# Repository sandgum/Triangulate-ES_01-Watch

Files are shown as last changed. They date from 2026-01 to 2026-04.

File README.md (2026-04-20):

# Triangulate ES_01 E-ink Watch

---

An ultra-thin ESP32S3-based smartwatch (at just 5mm thick at its thickest point) which uses an E-ink display and two OLEDs to display information while consuming a small amount of power. The main E-ink panel is touch-enabled, with the two additional OLED panels above and below it displaying auxiliary information, such as notifications, background activities etc. 
The watch has built-in heart rate and spO2 sensing via an Analog Devices MAX30102, high-precision smart movement sensing via a Bosch BH260AP IMU and a Bosch BMP585 barometric pressure sensor.

render1
render10

*ACKNOWLEDGMENT: Most of the materials and the human hand model you see in the renders are not my own work, but is Royalty-free or CC0 licensed work legitimately downloaded from BlenderKit using their free plan*

---

To top it all off, the ES_01 is completely workout-friendly, with rubberised sides and no pesky side buttons that get pressed mid-pushup (Every physical input is at the top of the watch)!
The watch features a sleek design, with each component being laid out single file and in its own separate segment of the watch. These segments can all bend around the watch, preserving a uniform thickness all around, which also adds the benefit of being aesthetically pleasing.
The main microcontroller running the watch is an Espressif ESP32-S3 running with Bluetooth LE capabilities, which also allow for it to sync with a smartphone to relay notifications, workout, and weather data etc. through firmware based on ESP-IDF and host smartphone software for iPhone based on Swift (Coming soon, and Android support will come later!)

---

## PCB:

- 4 layers
- Flex PCB
- Single-sided component placement
- 0.2mm board thickness
- Added 0.1mm FR4 stiffeners
- All resistors and capacitors are 0402 size

### Schematics:

ES_01 Schematics_Page_1
ES_01 Schematics_Page_2
ES_01 Schematics_Page_3
ES_01 Schematics_Page_4

### PCB Layout and render:


render4

*Render is out of date*

---

## Enclosure:

- Main cases and top plates of each segment 3D printed using PLA
- Bottom plates for OLED segments are CNC machined from 6061 Aluminium by JLCCNC (can substitute with any rigid material or also with SLA/MSLA printed resin)
- Bottom plate for main E-ink segment 3D printed using an SLM printer in 316L stainless steel (can substitute with other rigid metal with high thermal conductivity)
- Side flexible pieces printed in TPU by an FDM 3D printer

---

## Assembly instructions:

### To manufacture the PCB, refer to the instructions [here](PCB/README.md)

1. Use the solder stencil to squeegee solder paste onto main PCB
2. Place each component onto its respective pads on the main PCB
3. Use a hotplate or a reflow oven to reflow the solder paste underneath the components
4. Hand-solder a thin insulated wire (enamel insulated or rubber insulated) connecting the pads "BATT1_WIRE" together on the PCB
5. Create a solder bridge connecting the pads "GND_TO_GNDIO" and "GNDIO_TO_GND"
6. Create a solder bridge connecting the pads "GND_TO_GNDPWR" and "GNDPWR_TO_GND"
7. Assemble the two "end battery" segments by threading battery wires through them, placing the battery in and attaching the top plates to their respective main cases with superglue
8. Assemble the other battery segment and the haptic module segment in the same way, but thread the "end battery" wires through the dedicated channels in these segments, you should have two sets of two segments with four wires coming out of each set of segments
9. Take the main cases of the OLED modules and superglue the OLED displays into the top of each, making sure the flex cables poke through their dedicated holes
10. Do the same with the E-ink segment and the E-ink display
11. Attach each remaining top plate to its respective main case using superglue
12. Place and superglue the main Flex PCB into the bottom of the E-ink segment and the two OLED segments. The back of the PCB should face the displays
13. Thread the wires from the two sets of segments from step 8 through the holes in the side of the OLED modules and hand-solder the wires onto their respective pads
14. Plug in the flex cables from each display into thir respective FPC connectors on the main PCB
15. Superglue the bottom panels for the OLED segments onto their respective main cases
16. Apply thermal paste on the ESP32-S3 chip on the main PCB
17. Superglue threaded inserts in the two dedicated holes in the corners of the bottom panel for the E-ink segment
18. Superglue the bottom panel to the main case of the E-ink segment
19. Screw two screws into the holes in the top case of the E-ink segment until they mesh with the threaded inserts from the previous step
20. Take two more screws and cut off their entire threaded sections until just the heads remain. Superglue those heads in the holes in the other two corners of the top panel of the E-ink segment
21. Superglue the side TPU pieces to the sides of all the segments
22. Plug in a patch antenna into the exposed U.FL port on the back of the watch, guide the cable through its designated groove, and stick the patch antenna somewhere on the watch

---

## Bill of materials:

### Electronic Components: (Order quantities account for minimum order quantity of parts from the chosen retailer)

| Manufacturer Part Number | Mfr. | Order Qty. | Unit Price(USD) | Ext.Price(USD) | Package | Description | Product Link |
| --- | --- | --- | --- | --- | --- | --- | --- |
| CC0402JRNPO9BN110 | YAGEO | 100 | 0.0013 | 0.13 | 0402 | 11pF �5% 50V Ceramic Capacitor NP0 0402 | https://www.lcsc.com/product-detail/C527000.html |
| GRM155R61E475ME15D | muRata | 20 | 0.0403 | 0.81 | 0402 | 4.7uF �20% 25V Ceramic Capacitor X5R 0402 | https://www.lcsc.com/product-detail/C2858031.html |
| ESP32-S3 | ESPRESSIF | 1 | 3.0048 | 3 | QFN-56-EP(7x7) | -98.4dBm 150Mbps 2.412GHz~2.484GHz 2.4GHz 3V~3.6V QFN-56-EP(7x7) RF Transceiver ICs RoHS | https://www.lcsc.com/product-detail/C2913192.html |
| 2328702-6 | TE Connectivity | 5 | 0.2027 | 1.01 | SMD,P=0.5mm,Surface Mount,Right Angle  | FFC/FPC Connector 6 Position 0.5mm Pitch Double-Sided Contacts, Top and Bottom Entry Surface Mount, Right Angle -40?~+85?  | https://www.lcsc.com/product-detail/C3151647.html |
| FFC2B28-24-G | Global Connector Technology | 1 | 0.5754 | 0.58 | SMD,P=0.5mm,Surface Mount,Right Angle  | FFC/FPC Connector 24 Position 0.5mm Pitch Double-Sided Contacts, Top and Bottom Entry Surface Mount, Right Angle -25?~+85? | https://www.lcsc.com/product-detail/C3151659.html |
| BHI260AP | Bosch | 1 | 9.8338 | 9.83 | LGA-44 | LGA-44 IMUs (Inertial Measurement Units) RoHS | https://www.lcsc.com/product-detail/C3288651.html |
| SI1308EDL-T1-GE3 | VISHAY | 5 | 0.1543 | 0.77 | SOT-323 | N-Channel 30V 1.5A 0.4W Surface Mount SOT-323 | https://www.lcsc.com/product-detail/C469327.html |
| XC6206P302MR | HXY MOSFET | 50 | 0.0176 | 0.88 | SOT-23 | Linear Voltage Regulator IC Positive Fixed 1 Output 300mA SOT-23 | https://www.lcsc.com/product-detail/C5148691.html |
| MBR0530 | Huixin | 20 | 0.0296 | 0.59 | SOD-123 | 5.5A 1 Independent 30V 500mV@500mA 500mA SOD-123 Single Diodes RoHS | https://www.lcsc.com/product-detail/C49435625.html |
| 0402WGF1004TCE | UNI-ROYAL | 100 | 0.0008 | 0.08 | 0402 | 1M? �1% 62.5mW 0402 Thick Film Resistor | https://www.lcsc.com/product-detail/C26083.html |
| CL05A105KA5NQNC | Samsung Electro-Mechanics | 100 | 0.0033 | 0.33 | 0402 | 1uF �10% 25V Ceramic Capacitor X5R 0402 | https://www.lcsc.com/product-detail/C52923.html |
| XL2EL89CPI-111YLC-40M | YXC Crystal Oscillators | 10 | 0.0619 | 0.62 | SMD3225-4P | Crystal 40MHz �10ppm 15pF SMD3225-4P | https://www.lcsc.com/product-detail/C5444549.html |
| TS-1088-AR02016 | XUNPU | 10 | 0.0455 | 0.46 | SMD,4x3mm | Tactile Switch SPST 160gf 2mm SMD (SMT) Tab 4mm x 3mm Surface Mount | https://www.lcsc.com/product-detail/C720477.html |
| BSS138 | R+O | 50 | 0.0172 | 0.86 | SOT-23 | N-Channel 50V 340mA 350mW Surface Mount SOT-23 | https://www.lcsc.com/product-detail/C7420339.html |
| TCR2EF33,LM(CT | TOSHIBA | 5 | 0.1077 | 0.54 | TSOT-25 | 3.3V 5.5V Positive Fixed TSOT-25 Voltage Regulators - Linear, Low Drop Out (LDO) Regulators RoHS | https://www.lcsc.com/product-detail/C843273.html |
| LQG15HS3N3S02D | muRata | 100 | 0.0079 | 0.79 | 0402 | 800mA 3.3nH 170m? Multilayer inductor 0402 Fixed Inductors RoHS | https://www.lcsc.com/product-detail/C86064.html |
| MRA4003T3G | onsemi | 10 | 0.1152 | 1.15 | SMA(DO-214AC) | Diode 300V 1A Surface Mount SMA(DO-214AC) | https://www.lcsc.com/product-detail/C94410.html |
| DRV2605LDGSR | TI | 1 | 1.3734 | 1.37 | VSSOP-10-0.5mm | I2C VSSOP-10-0.5mm Motor Drivers, Controllers RoHS | https://www.lcsc.com/product-detail/C527464.html |
| LQG15HS2N0S02D | muRata | 100 | 0.0084 | 0.84 | 0402 | 900mA 2nH 100m? Multilayer inductor 0402 Fixed Inductors RoHS | https://www.lcsc.com/product-detail/C18216.html |
| 0402WGF5603TCE | UNI-ROYAL | 100 | 0.0006 | 0.06 | 0402 | 560k? �1% 62.5mW 0402 Thick Film Resistor | https://www.lcsc.com/product-detail/C132339.html |
| CL05B103KB5NNNC | Samsung Electro-Mechanics | 100 | 0.0014 | 0.14 | 0402 | 10nF �10% 50V Ceramic Capacitor X7R 0402 | https://www.lcsc.com/product-detail/C15195.html |
| 0402B102K500NT | FH | 100 | 0.0012 | 0.12 | 0402 | 1nF �10% 50V Ceramic Capacitor X7R 0402 | https://www.lcsc.com/product-detail/C1523.html |
| CL05B104KO5NNNC | Samsung Electro-Mechanics | 100 | 0.0013 | 0.13 | 0402 | 100nF �10% 16V Ceramic Capacitor X7R 0402 | https://www.lcsc.com/product-detail/C1525.html |
| 0402CG1R0C500NT | FH | 100 | 0.0012 | 0.12 | 0402 | 1pF 50V Ceramic Capacitor C0G 0402 | https://www.lcsc.com/product-detail/C1550.html |
| CL05A106MQ5NUNC | Samsung Electro-Mechanics | 100 | 0.0056 | 0.56 | 0402 | 10uF �20% 6.3V Ceramic Capacitor X5R 0402 | https://www.lcsc.com/product-detail/C15525.html |
| CL05B224KO5NNNC | Samsung Electro-Mechanics | 100 | 0.0041 | 0.41 | 0402 | 220nF �10% 16V Ceramic Capacitor X7R 0402 | https://www.lcsc.com/product-detail/C16772.html |
| BMP585 | Bosch | 1 | 3.5109 | 3.51 | LGA-9(3.3x3.3) | 30Kpa~1.25bar LGA-9(3.3x3.3) Pressure Sensors, Transducers RoHS | https://www.lcsc.com/product-detail/C18184976.html |
| LD39200PU33R | ST | 1 | 1.0184 | 1.02 | DFN-6(3x3) | 3.3V 6V Positive Fixed DFN-6(3x3) Voltage Regulators - Linear, Low Drop Out (LDO) Regulators RoHS | https://www.lcsc.com/product-detail/C222192.html |
| CL05A475MP5NRNC | Samsung Electro-Mechanics | 50 | 0.0055 | 0.28 | 0402 | 4.7uF �20% 10V Ceramic Capacitor X5R 0402 | https://www.lcsc.com/product-detail/C23733.html |
| 0402WGF2201TCE | UNI-ROYAL | 100 | 0.0008 | 0.08 | 0402 | 2.2k? �1% 62.5mW 0402 Thick Film Resistor | https://www.lcsc.com/product-detail/C25879.html |
| 0402WGF4701TCE | UNI-ROYAL | 100 | 0.0008 | 0.08 | 0402 | 4.7k? �1% 62.5mW 0402 Thick Film Resistor | https://www.lcsc.com/product-detail/C25900.html |
| ANR4012T470M | APV | 10 | 0.0544 | 0.54 | SMD,4x4mm | 500mA 47uH 500mA Magnetic Shielded Inductor �20% SMD,4x4mm Fixed Inductors RoHS | https://www.lcsc.com/product-detail/C7497063.html |
| MAX30102EFD+T | MAXIM | 1 | 13.0636 | 13.06 | OESIP-14 | I2C OESIP-14 Specialized Sensors RoHS | https://www.lcsc.com/product-detail/C6454833.html |
| MAX17048X+T10 | MAXIM | 1 | 1.1576 | 1.16 | WLP-8(0.9x1.8) | Lithium Battery I2C WLP-8(0.9x1.8) Battery Management RoHS | https://www.lcsc.com/product-detail/C7497002.html |
| 1N4148 | onsemi | 50 | 0.0353 | 1.77 | DO-35 | Diode 100V 200mA Through Hole DO-35 | https://www.lcsc.com/product-detail/C258182.html |
| FRC0402F1001TS | FOJAN | 100 | 0.0006 | 0.06 | 0402 | 1k? �1% 62.5mW 0402 Thick Film Resistor | https://www.lcsc.com/product-detail/C2906864.html |
| FRC0402F22R0TS | FOJAN | 100 | 0.0006 | 0.06 | 0402 | 22? �1% 62.5mW 0402 Thick Film Resistor | https://www.lcsc.com/product-detail/C2929994.html |
| FRC0402F2R20TS | FOJAN | 100 | 0.0008 | 0.08 | 0402 | 2.2? �1% 62.5mW 0402 Thick Film Resistor | https://www.lcsc.com/product-detail/C2909330.html |
| FRC0402F1002TS | FOJAN | 100 | 0.0006 | 0.06 | 0402 | 10k? �1% 62.5mW 0402 Thick Film Resistor | https://www.lcsc.com/product-detail/C2906861.html |
| LW06121 | WENDA | 100 | 0.07 | 7 | SMD,P=0.62mm,Surface Mount,Right Angle | 1.2H 14Pin 0.62mm Pitch OLED FPC/FFC Upper Contact Pull-Out Horizontal SMD Flat Connector | https://www.alibaba.com/product-detail/WENDA-LW06121-1-2H-14Pin-0_1601292173873.html |
| GDEY0154D67-T03 | Goodisplay | 1 | 11.32 | 11.32 | - | 1.54Inch Touch E-Paper 200x200 E-Ink Display | https://www.aliexpress.com/item/1005005200574055.html |
| SSD1306 | - | 2 | 0.72 | 1.44 | - | 0.91 Inch I2C OLED Module | https://www.aliexpress.com/item/1005004415958608.html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 |
| 401230 | - | 5 | 8.37 | 11.7 | - | 3.7V 130mAh Rechargeable Li-Po Polymer Battery | https://www.aliexpress.com/item/1005011548432569.html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,scm-url:1007.40050.354490.0,pvid:3bd3e2fd-a970-4708-ad0d-5a1d5a035dc8,tpp_buckets:668%232846%238108%231977&pdp_ext_f=%7B"order"%3A"6"%2C"eval"%3A"1"%2C"sceneId"%3A"30050"%2C"fromPage"%3A"recommend"%7D&pdp_npi=6%40dis%21USD%2113.08%218.37%21%21%2189.86%2157.51%21%402101e2b417711150796635781ebc60%2112000055887278871%21rec%21AU%216047249797%21XZ%211%210%21n_tag%3A-29919%3Bd%3A65a10f57%3Bm03_new_user%3A-29895&utparam-url=scene%3ApcDetailTopMoreOtherSeller%7Cquery_from%3A%7Cx_object_id%3A1005011548432569%7C_p_origin_prod%3A |
| 0619AAC | - | 1 | 3.06 | 3.06 | - | Brushless X-axis 1.2V 100mA Max Precision Vibration Motor | https://www.aliexpress.com/item/1005006421331249.html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 |
| TS-A002 | - | 20 | 0.069 | 1.38 | - | Momentary Tact Switch SMD | https://www.aliexpress.com/item/1005008702742151.html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 |
| - | - | 50 | 0.0264 | 1.32 | - | M1.4 Torx countersunk machine screw 4mm length | https://www.aliexpress.com/item/33006942612.html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 |
| - | - | 50 | 0.0244 | 1.22 | - | M1.4 Brass threaded inserts 1.5mm length | https://www.aliexpress.com/item/1005007653131713.html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 |

Total: $88.97 USD

### Manufactured Components

| Description | Manufacturer | Material | Price (USD) |
| --- | --- | --- | --- |
| CNC Machined OLED Segment Bottom Plates  | JLCCNC | Aluminium 6061 | 17.46 |
| SLM 3D Printed Main Segment Bottom Plate | JLC3DP | 316L Stainless Steel | 8.39 |
| Main 4-layer Flex PCB | JLCPCB | Yellow 0.2mm Polyimide with 0.1mm FR4 Stiffener | 94.00 |
| SMD Stencil for Main Flex PCB | JLCPCB | Steel | 7.47 |

Total: $127.32 USD

---

## Grand Total (Excl. Shipping): $216.29 USD

---

render2
render3
render7
render9
render6
render5

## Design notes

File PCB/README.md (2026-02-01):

# How to Manufacture the PCB

1. Go to the folder `PCB/Production Files`

2. Find the zip file named `ES_01_mainPCB-vxx.zip`

3. Upload the zip file to JLCPCB (or your preferred PCB manufacturing site), DO NOT expand the file

4. If you are using JLCPCB, follow these next instructions:
   
   1. **Set Base Material to Flex**
   
   2. Set Substrate Type to 25um dielectric thickness
   
   3. **Set Layers to 4**
   
   4. Leave Dimensions unchanged (They should be greyed out anyways)
   
   5. **Set PCB Qty to 5**
   
   6. Leave Different Design and Delivery Format unchanged
   
   7. **Set PCB Thickness to 0.2mm**
   
   8. Set Coverlay Color to whatever you want! (Yellow is the cheapest btw)
   
   9. Leave Silkscreen, Copper Type, Surface Finish and Gold Thickness unchanged
   
   10. Leave Outer Copper Weight, Inner Copper Weight, Specify Layer Sequence, Stackup Type, Layer Stackup, Coverlay Thickness and Gold Fingers unchanged
   
   11. Set EDA Software to Other
   
   12. **Set Stiffener to FR4**
   
   13. **Set FR4 Thickness to 0.1mm**
   
   14. Leave Cutting Method and Confirm Production file unchanged
   
   15. Set Mark on PCB to Order Number
   
   16. Leave everything else unchanged
   
   17. At the very bottom, select PCB Stencil. In its settings:
       
       1. Leave Framework, Step Stencil and Nano-coating unchanged
       
       2. **Set Stencil Style to Top only**
       
       3. Leave Dimensions unchanged
       
       4. **Set Stencil Qty to 1**
       
       5. Leave everything else unchanged
   
   18. Click Save to Cart, and you're done!

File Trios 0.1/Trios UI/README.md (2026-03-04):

# How this UI project works

* After a lot of going back and forth, this UI uses EEZ studio as its drag and drop editor.
* Since EEZ Studio cannot support multiple displays in one project (The ES_01 has three displays), each display gets its own EEZ Studio project.
* These will be exported (once done) and have custom logic added to the C files which links events happening on the main screen to changes on the two OLEDS.
* There will be a bunch of other stuff added to the C code, including wiring in all the variables and setting callback functions for haptics.

# Implemented features

* Watch face showing:
  * Time
  * Date
  * Heart rate
  * Altitude
  * Step count for today
* 3 menu pages with 12 "apps" in total
  * ### Workout app:
    * 6 different workout types
      * Run
      * Walk
      * Cycle
      * HIIT
      * Yoga
      * Other
    * Statistics based on previous workouts
      * Zoomable graph showing activity over time
      * Top three favourite workouts, ranked by number of times done
    * Multipurpose counter
    * Workout sensor data
      * Heart rate
      * Estimated calories
      * Reps/distance travelled
    * After workout statistics
      * Zoomable graphs for:
        * Heart rate over time
        * Calories over time
        * Distance/reps over time
      * Average heart rate
      * Total calories burnt
  * ### Barometer app:
    * Current altitude
    * Average altitude for today
    * Zoomable graph for altitude over time
    * Current air pressure
    * Average air pressure for today
    * Zoomable graph for air pressure over time
  * ### Activity stats app:
    * Total step count, calories, activity time for today
    * Portion of daily step, calorie, activity goal completed
    * Zoomable graph for:
      * Step count over time
      * Calorie count over time
      * Activity over time
  * ### Vitals app:
    * Current heart rate, SpO2
    * Resting heart rate
    * Average SpO2
    * Zoomable graph showing heart rate, SpO2
  * ### Weather app:
    * Current temperature from iPhone WeatherKit
    * Current temperature measured by onboard sensor
    * Min/max temperatures for today (WeatherKit)
    * Current weather conditions (WeatherKit)
    * Forecasted temperature, weather conditions for the rest of the day (WeatherKit)
    * Forecasted min/max temperatures, weather conditions for next 10 days (WeatherKit)
  * ### Notifications:
    * Shows an indefinite number of notifications in the form of pages of four
    * App, title and text content of each notification
    * Tapping a notification opens an extended notification view, where more content text is shown
    * Notifications show an extended view when new notifications arrive
    * Specialised notification view for calls, with the option to decline or accept on phone
  * ### Timekeeping app:
    * Stopwatch
      * All logic is integrated using EEZ Flow
      * Stopwatch can be stopped, resumed and reset
      * Up to 99h 59m 59s counting
      * Arc to show seconds
    * Timer
      * All logic is implemented using EEZ Flow
      * Rollers for hours, minutes and seconds
      * Values on roller automatically update with countdown
      * Timer continues in the background
      * End of timer pop-up which shows upon completion, no matter where in the UI the user is
  * ### Timetable app:
    * Shows an arbitrary number of timetable events for a single day on a roller
    * Shows all timetable events for each day of the week
    * Editing timetable events will happen through the iPhone app
    * Timetable event popup which appears a set period of time before each event

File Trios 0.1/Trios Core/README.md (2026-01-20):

# Functions implemented so far:

* Wrote driver for 1.54 inch e-ink display to operate over SPI (uses ssd1681 driver IC)
* Wrote driver for FT6336 touch driver IC (for main e-ink panel)
* Implemented LVGL v9 into project
* Implemented OLED displays (ssd1306 driver IC) into project and LVGL
* Upgraded project to use ESP-IDF 5.3 (to use built-in ssd1306 component)
* Created minimal driver library for MAX30102 heart rate sensor
* Implemented basic heart rate measurement using MAX30102
* Implemented various functions using Bosch BHI260AP IMU using Bosch API, including:

  * Orientation tracking using IMU's built-in sensor fusion algorithm
  * Intelligent step counting using IMU's built-in algorithm running on its own coprocessor
  * Intelligent wrist raise detection, sending interrupts to wake ESP32 from light sleep

* Implemented basic sleep/wake-up logic, including:

  * Putting ESP32 in light sleep after a certain period of inactivity on touch screen
  * Putting ESP32 in light sleep when BHI260AP detects that the user's wrist is facing downwards
  * Waking ESP32 from light sleep using its own timer to periodically take heart rate measurements

* Implemented reading Bosch BMP585 pressure/temperature sensor using Bosch sensor API
* Implemented driving DRV2605 haptic driver
* IT BUILDS!!!

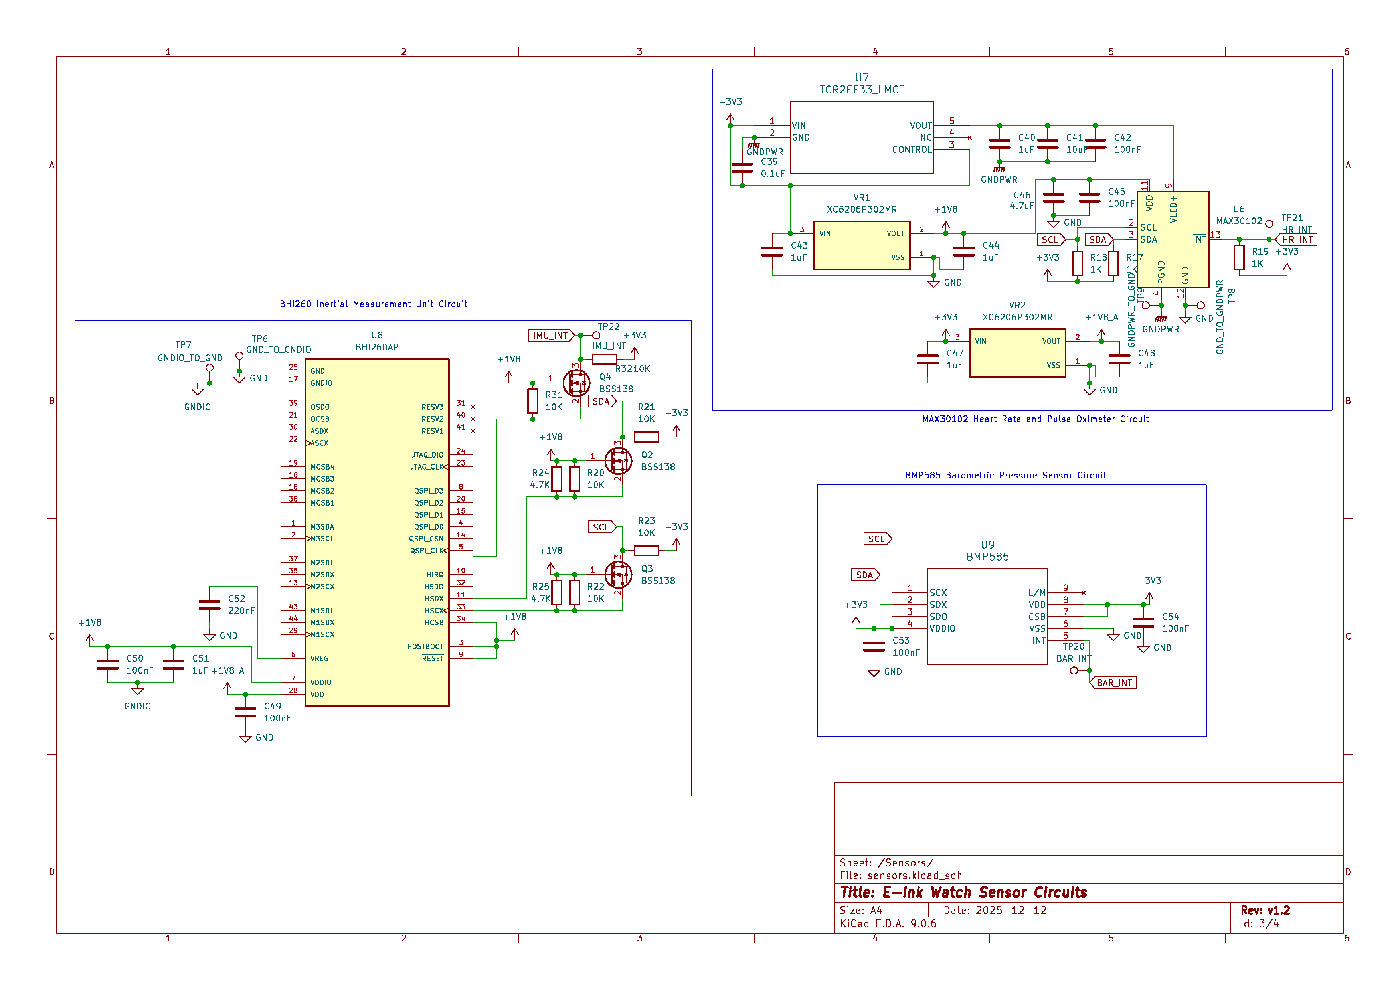
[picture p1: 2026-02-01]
PCB/KiCAD Files v3.2/E-ink watch_Page_3.png

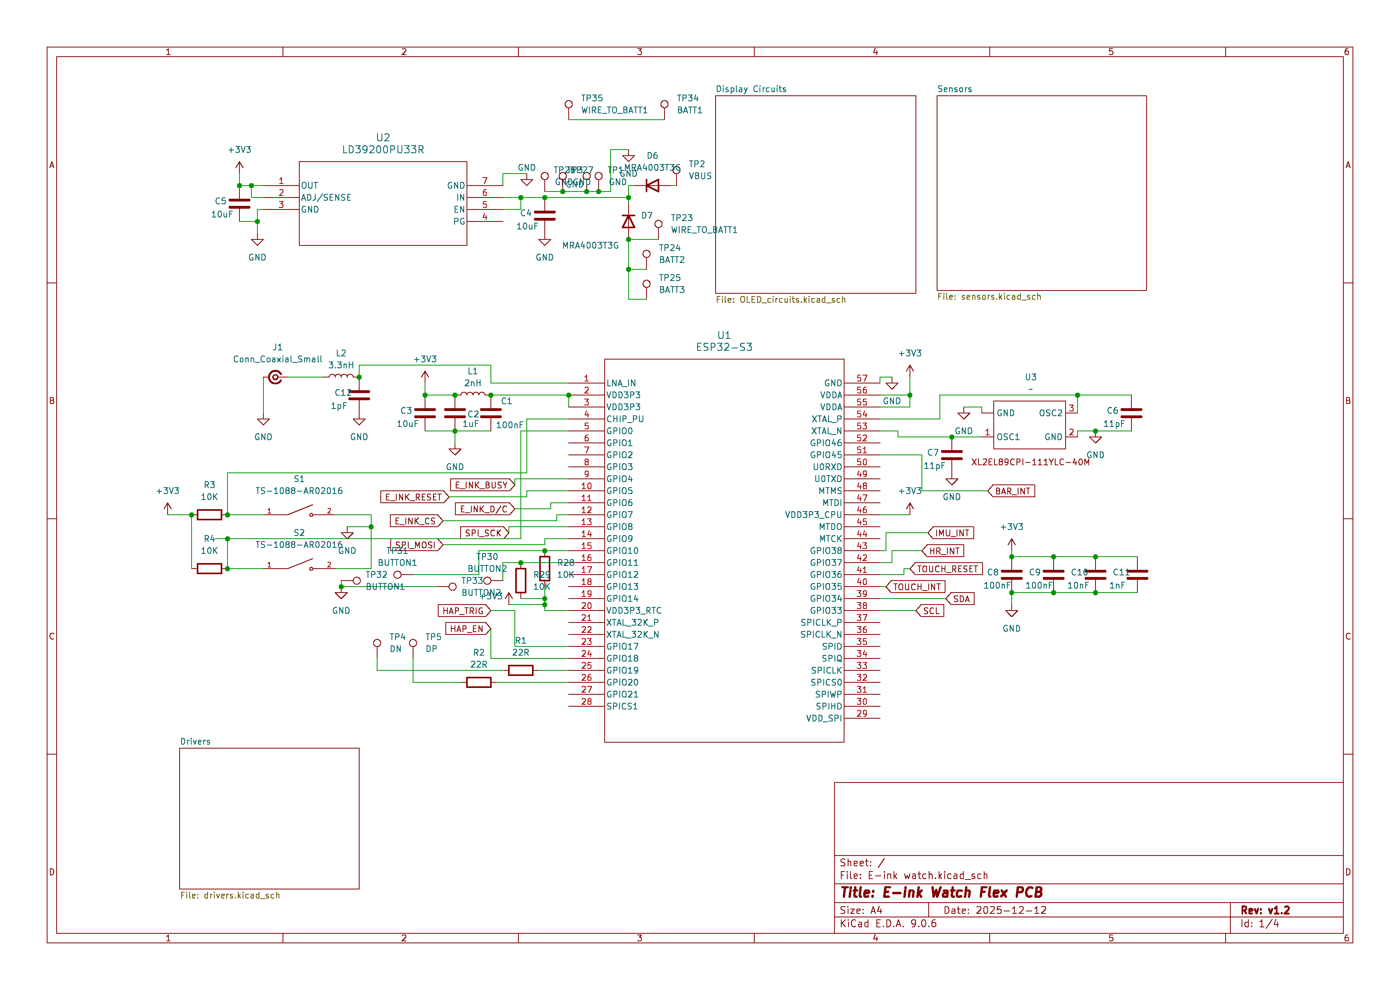
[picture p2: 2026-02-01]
PCB/KiCAD Files v3.2/E-ink watch_Page_1.png

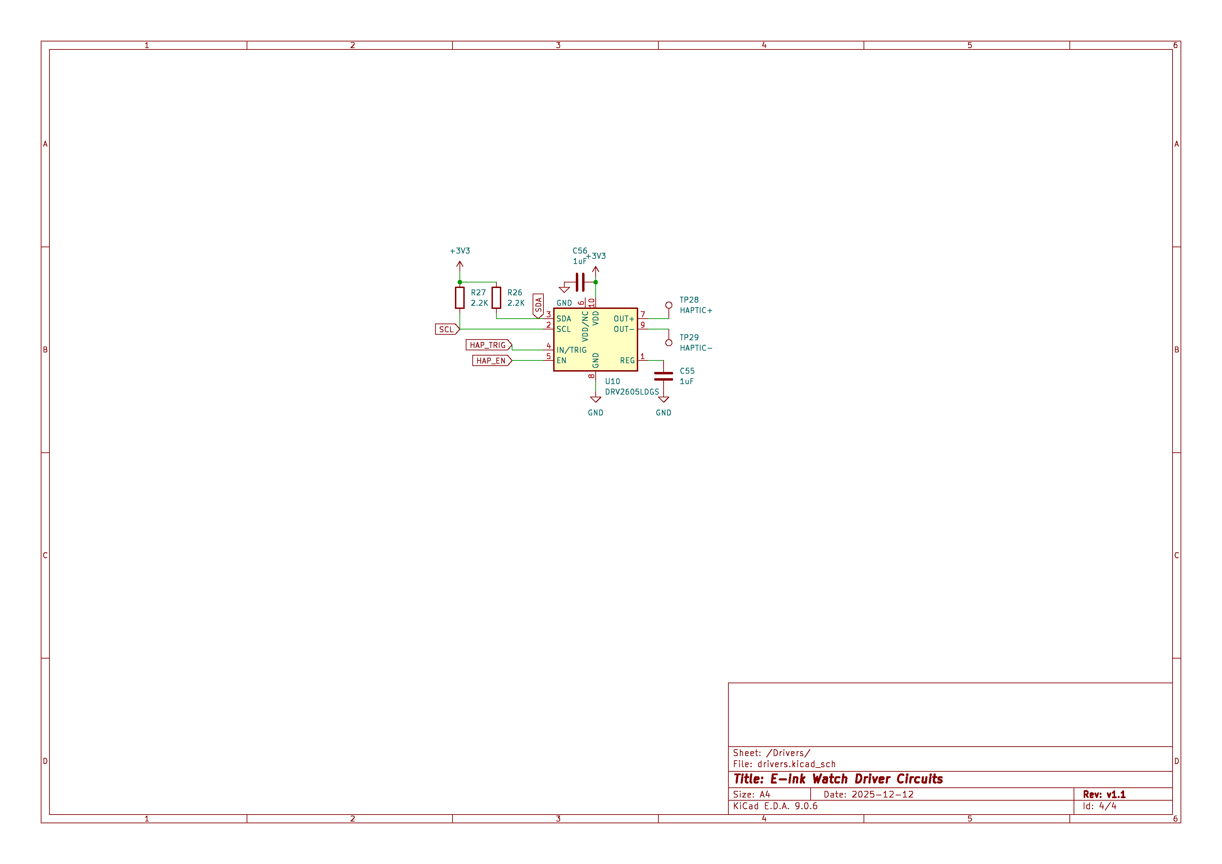
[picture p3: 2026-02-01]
PCB/KiCAD Files v3.2/E-ink watch_Page_4.png

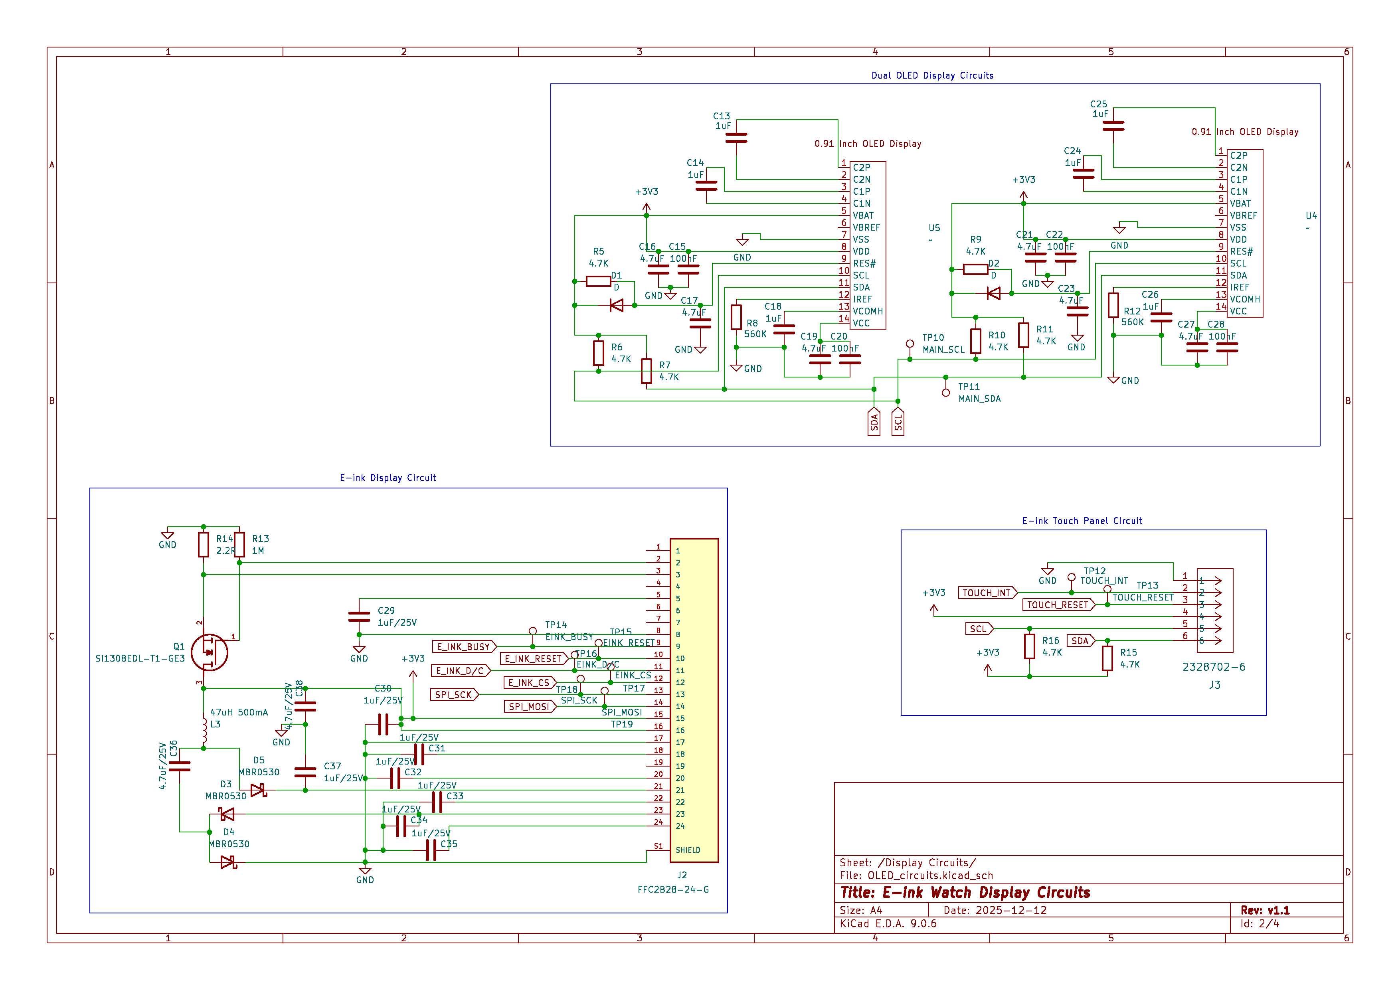
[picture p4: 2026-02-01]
PCB/KiCAD Files v3.2/E-ink watch_Page_2.png

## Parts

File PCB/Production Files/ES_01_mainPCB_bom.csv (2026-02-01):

Designator | Footprint | Quantity | Value | LCSC Part #
C1, C15, C20, C22, C28, C42, C45, C49, C50, C53, C54, C8, C9 | 0402 | 13 | 100nF
C10 | 0402 | 1 | 10nF
C11 | 0402 | 1 | 1nF
C12 | 0402 | 1 | 1pF
C13, C14, C2, C24, C25, C40, C43, C44, C47, C48, C51, C55, C56, C57, C58 | 0402 | 15 | 1uF
C16, C17, C19, C21, C23, C27, C46 | 0402 | 7 | 4.7uF
C18, C26 | 0402 | 2 | 2.2uF
C29, C30, C31, C32, C33, C34, C35, C37 | 0402 | 8 | 1uF/25V
C3, C4, C41, C5 | 0402 | 4 | 10uF
C36, C38 | 0402 | 2 | 4.7uF/25V
C39 | 0402 | 1 | 0.1uF
C52 | 0402 | 1 | 220nF
C6, C7 | 0402 | 2 | 11pF
D1, D2 | D_DO-35_SOD27_P7.62mm_Horizontal | 2 | D
D3, D4, D5 | 0805 | 3 | MBR0530
D6, D7 | D_SMA | 2 | MRA4003T3G
J1 | U.FL_Hirose_U.FL-R-SMT-1_Vertical | 1 | Conn_Coaxial_Small
J2 | GCT_FFC2B28-24-G | 1 | FFC2B28-24-G
J3 | CONN6_2328702-6_TEC | 1 | 2328702-6
L1 | 0402 | 1 | 2nH
L2 | 0402 | 1 | 3.3nH
L3 | Untitled | 1 | 47uH 500mA
Q1 | SOT65P210X110-3N | 1 | SI1308EDL-T1-GE3
Q2, Q3, Q4 | SOT-23 | 3 | BSS138
R1, R2 | 0402 | 2 | 22R
R10, R11, R15, R16, R24, R25, R5, R6, R7, R9 | 0402 | 10 | 4.7K
R12, R8 | 0402 | 2 | 560K
R13 | 0402 | 1 | 1M
R14 | 0402 | 1 | 2.2R
R17, R18, R19 | 0402 | 3 | 1K
R20, R21, R22, R23, R28, R29, R3, R30, R31, R32, R33, R34, R35, R4 | 0402 | 14 | 10K
R26, R27 | 0402 | 2 | 2.2K
S1, S2 | SW_TS-1088-AR02016 | 2 | TS-1088-AR02016
TP1, TP26, TP27, TP3 | TestPoint_Pad_1.5x1.5mm | 4 | GND
TP10 | TestPoint_Pad_D1.0mm | 1 | MAIN_SCL
TP11 | TestPoint_Pad_D1.0mm | 1 | MAIN_SDA
TP12 | TestPoint_Pad_D1.0mm | 1 | TOUCH_INT
TP13 | TestPoint_Pad_D1.0mm | 1 | TOUCH_RESET
TP14 | TestPoint_Pad_D1.0mm | 1 | EINK_BUSY
TP15 | TestPoint_Pad_D1.0mm | 1 | EINK_RESET
TP16 | TestPoint_Pad_D1.0mm | 1 | EINK_D/C
TP17 | TestPoint_Pad_D1.0mm | 1 | EINK_CS
TP18 | TestPoint_Pad_D1.0mm | 1 | SPI_SCK
TP19 | TestPoint_Pad_D1.0mm | 1 | SPI_MOSI
TP2 | TestPoint_Pad_1.5x1.5mm | 1 | VBUS
TP20 | TestPoint_Pad_D1.0mm | 1 | BAR_INT
TP21 | TestPoint_Pad_D1.0mm | 1 | HR_INT
TP22 | TestPoint_Pad_D1.0mm | 1 | IMU_INT
TP23, TP35 | TestPoint_Pad_1.5x1.5mm | 2 | WIRE_TO_BATT1
TP24 | TestPoint_Pad_1.5x1.5mm | 1 | BATT2
TP25 | TestPoint_Pad_1.5x1.5mm | 1 | BATT3
TP28 | TestPoint_Pad_1.5x1.5mm | 1 | HAPTIC+
TP29 | TestPoint_Pad_1.5x1.5mm | 1 | HAPTIC-
TP30, TP33 | TestPoint_Pad_1.5x1.5mm | 2 | BUTTON2
TP31, TP32 | TestPoint_Pad_1.5x1.5mm | 2 | BUTTON1
TP34 | TestPoint_Pad_1.5x1.5mm | 1 | BATT1
TP4 | TestPoint_Pad_1.5x1.5mm | 1 | DN
TP5 | TestPoint_Pad_1.5x1.5mm | 1 | DP
TP6 | TestPoint_Pad_1.5x1.5mm | 1 | GND_TO_GNDIO
TP7 | TestPoint_Pad_1.5x1.5mm | 1 | GNDIO_TO_GND
TP8 | TestPoint_Pad_1.5x1.5mm | 1 | GND_TO_GNDPWR
TP9 | TestPoint_Pad_1.5x1.5mm | 1 | GNDPWR_TO_GND
U1 | QFN56_7X7_EXP | 1 | ESP32-S3
U10 | VSSOP-10_3x3mm_P0.5mm | 1 | DRV2605LDGS
U11 | SON50P200X200X80-9N | 1 | MAX17048G_T10
U2 | SON_DFN6_3X3_STM | 1 | LD39200PU33R
U3, U4, U5 | Untitled | 3 | ~
U6 | Maxim_OLGA-14_3.3x5.6mm_P0.8mm | 1 | MAX30102
U7 | SOT-25 SMV_TOS | 1 | TCR2EF33_LMCT
U8 | XDCR_BHI260AP | 1 | BHI260AP
U9 | LGA9_BMP585_BOS | 1 | BMP585
VR1, VR2 | SOT95P280X130-3N | 2 | XC6206P302MR

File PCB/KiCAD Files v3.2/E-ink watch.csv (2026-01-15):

Reference | Qty | Value | DNP | Exclude from BOM | Exclude from Board | Footprint | Datasheet
C1,C8,C9,C15,C20,C22,C28,C42,C45,C49,C50,C53,C54 | 13 | 100nF |  |  |  | Capacitor_SMD:C_0402_1005Metric_Pad0.74x0.62mm_HandSolder | ~
C2,C13,C14,C18,C24,C25,C26,C40,C43,C44,C47,C48,C51,C55,C56 | 15 | 1uF |  |  |  | Capacitor_SMD:C_0402_1005Metric_Pad0.74x0.62mm_HandSolder | ~
C3,C4,C5,C41 | 4 | 10uF |  |  |  | Capacitor_SMD:C_0402_1005Metric_Pad0.74x0.62mm_HandSolder | ~
C6,C7 | 2 | 11pF |  |  |  | Capacitor_SMD:C_0402_1005Metric_Pad0.74x0.62mm_HandSolder | ~
C10 | 1 | 10nF |  |  |  | Capacitor_SMD:C_0402_1005Metric_Pad0.74x0.62mm_HandSolder | ~
C11 | 1 | 1nF |  |  |  | Capacitor_SMD:C_0402_1005Metric_Pad0.74x0.62mm_HandSolder | ~
C12 | 1 | 1pF |  |  |  | Capacitor_SMD:C_0402_1005Metric_Pad0.74x0.62mm_HandSolder | ~
C16,C17,C19,C21,C23,C27,C46 | 7 | 4.7uF |  |  |  | Capacitor_SMD:C_0402_1005Metric_Pad0.74x0.62mm_HandSolder | ~
C29,C30,C31,C32,C33,C34,C35,C37 | 8 | 1uF/25V |  |  |  | Capacitor_SMD:C_0402_1005Metric_Pad0.74x0.62mm_HandSolder | ~
C36,C38 | 2 | 4.7uF/25V |  |  |  | Capacitor_SMD:C_0402_1005Metric_Pad0.74x0.62mm_HandSolder | ~
C39 | 1 | 0.1uF |  |  |  | Capacitor_SMD:C_0402_1005Metric_Pad0.74x0.62mm_HandSolder | ~
C52 | 1 | 220nF |  |  |  | Capacitor_SMD:C_0402_1005Metric_Pad0.74x0.62mm_HandSolder | ~
D1,D2 | 2 | D |  |  |  | Diode_THT:D_DO-35_SOD27_P7.62mm_Horizontal | ~
D3,D4,D5 | 3 | MBR0530 |  |  |  | Diode_SMD:D_0805_2012Metric_Pad1.15x1.40mm_HandSolder | ~
D6,D7 | 2 | MRA4003T3G |  |  |  | Diode_SMD:D_SMA | http://www.onsemi.com/pub_link/Collateral/MRA4003T3-D.PDF
J1 | 1 | Conn_Coaxial_Small |  |  |  | Connector_Coaxial:U.FL_Hirose_U.FL-R-SMT-1_Vertical | ~
J2 | 1 | FFC2B28-24-G |  |  |  | FFC2B28-24-G:GCT_FFC2B28-24-G
J3 | 1 | 2328702-6 |  |  |  | 2328702-6:CONN6_2328702-6_TEC | https://www.te.com/commerce/DocumentDelivery/DDEController?Action=srchrtrv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
L1 | 1 | 2nH |  |  |  | Inductor_SMD:L_0402_1005Metric_Pad0.77x0.64mm_HandSolder | ~
L2 | 1 | 3.3nH |  |  |  | Inductor_SMD:L_0402_1005Metric_Pad0.77x0.64mm_HandSolder | ~
L3 | 1 | 47uH 500mA |  |  |  | ANR4012T470M inductor:Untitled | ~
Q1 | 1 | SI1308EDL-T1-GE3 |  |  |  | SI1308EDL-T1-GE3:SOT65P210X110-3N
Q2,Q3 | 2 | BSS138 |  |  |  | Package_TO_SOT_SMD:SOT-23 | https://www.onsemi.com/pub/Collateral/BSS138-D.PDF
R1,R2 | 2 | 22R |  |  |  | Resistor_SMD:R_0402_1005Metric_Pad0.72x0.64mm_HandSolder | ~
R3,R4,R20,R21,R22,R23,R28,R29 | 8 | 10K |  |  |  | Resistor_SMD:R_0402_1005Metric_Pad0.72x0.64mm_HandSolder | ~
R5,R6,R7,R9,R10,R11,R15,R16,R24,R25 | 10 | 4.7K |  |  |  | Resistor_SMD:R_0402_1005Metric_Pad0.72x0.64mm_HandSolder | ~
R8,R12 | 2 | 560K |  |  |  | Resistor_SMD:R_0402_1005Metric_Pad0.72x0.64mm_HandSolder | ~
R13 | 1 | 1M |  |  |  | Resistor_SMD:R_0402_1005Metric_Pad0.72x0.64mm_HandSolder | ~
R14 | 1 | 2.2R |  |  |  | Resistor_SMD:R_0402_1005Metric_Pad0.72x0.64mm_HandSolder | ~
R17,R18,R19 | 3 | 1K |  |  |  | Resistor_SMD:R_0402_1005Metric_Pad0.72x0.64mm_HandSolder | ~
R26,R27 | 2 | 2.2K |  |  |  | Resistor_SMD:R_0402_1005Metric_Pad0.72x0.64mm_HandSolder | ~
S1,S2 | 2 | TS-1088-AR02016 |  |  |  | TS-1088-AR02016:SW_TS-1088-AR02016
TP1,TP3,TP26,TP27 | 4 | GND |  |  |  | TestPoint:TestPoint_Pad_1.5x1.5mm | ~
TP2 | 1 | VBUS |  |  |  | TestPoint:TestPoint_Pad_1.5x1.5mm | ~
TP4 | 1 | DN |  |  |  | TestPoint:TestPoint_Pad_1.5x1.5mm | ~
TP5 | 1 | DP |  |  |  | TestPoint:TestPoint_Pad_1.5x1.5mm | ~
TP6 | 1 | GND_TO_GNDIO |  |  |  | TestPoint:TestPoint_Pad_1.5x1.5mm | ~
TP7 | 1 | GNDIO_TO_GND |  |  |  | TestPoint:TestPoint_Pad_1.5x1.5mm | ~
TP8 | 1 | GND_TO_GNDPWR |  |  |  | TestPoint:TestPoint_Pad_1.5x1.5mm | ~
TP9 | 1 | GNDPWR_TO_GND |  |  |  | TestPoint:TestPoint_Pad_1.5x1.5mm | ~
TP10 | 1 | MAIN_SCL |  |  |  | TestPoint:TestPoint_Pad_D1.0mm | ~
TP11 | 1 | MAIN_SDA |  |  |  | TestPoint:TestPoint_Pad_D1.0mm | ~
TP12 | 1 | TOUCH_INT |  |  |  | TestPoint:TestPoint_Pad_D1.0mm | ~
TP13 | 1 | TOUCH_RESET |  |  |  | TestPoint:TestPoint_Pad_D1.0mm | ~
TP14 | 1 | EINK_BUSY |  |  |  | TestPoint:TestPoint_Pad_D1.0mm | ~
TP15 | 1 | EINK_RESET |  |  |  | TestPoint:TestPoint_Pad_D1.0mm | ~
TP16 | 1 | EINK_D/C |  |  |  | TestPoint:TestPoint_Pad_D1.0mm | ~
TP17 | 1 | EINK_CS |  |  |  | TestPoint:TestPoint_Pad_D1.0mm | ~
TP18 | 1 | SPI_SCK |  |  |  | TestPoint:TestPoint_Pad_D1.0mm | ~
TP19 | 1 | SPI_MOSI |  |  |  | TestPoint:TestPoint_Pad_D1.0mm | ~
TP20 | 1 | BAR_INT |  |  |  | TestPoint:TestPoint_Pad_D1.0mm | ~
TP21 | 1 | HR_INT |  |  |  | TestPoint:TestPoint_Pad_D1.0mm | ~
TP22 | 1 | IMU_INT |  |  |  | TestPoint:TestPoint_Pad_D1.0mm | ~
TP23,TP35 | 2 | WIRE_TO_BATT1 |  |  |  | TestPoint:TestPoint_Pad_1.5x1.5mm | ~
TP24 | 1 | BATT2 |  |  |  | TestPoint:TestPoint_Pad_1.5x1.5mm | ~
TP25 | 1 | BATT3 |  |  |  | TestPoint:TestPoint_Pad_1.5x1.5mm | ~
TP28 | 1 | HAPTIC+ |  |  |  | TestPoint:TestPoint_Pad_1.5x1.5mm | ~
TP29 | 1 | HAPTIC- |  |  |  | TestPoint:TestPoint_Pad_1.5x1.5mm | ~
TP30,TP33 | 2 | BUTTON2 |  |  |  | TestPoint:TestPoint_Pad_1.5x1.5mm | ~
TP31,TP32 | 2 | BUTTON1 |  |  |  | TestPoint:TestPoint_Pad_1.5x1.5mm | ~
TP34 | 1 | BATT1 |  |  |  | TestPoint:TestPoint_Pad_1.5x1.5mm | ~
U1 | 1 | ESP32-S3 |  |  |  | ESP32-S3:QFN56_7X7_EXP | ESP32-S3
U2 | 1 | LD39200PU33R |  |  |  | LD39200PU33R:SON_DFN6_3X3_STM | https://www.st.com/resource/en/datasheet/ld39200.pdf
U3 | 1 | ~ |  |  |  | XL2EL89CPI-111YLC-40M:Untitled
U4,U5 | 2 | ~ |  |  |  | 2328702-6:Untitled
U6 | 1 | MAX30102 |  |  |  | OptoDevice:Maxim_OLGA-14_3.3x5.6mm_P0.8mm | https://datasheets.maximintegrated.com/en/ds/MAX30102.pdf
U7 | 1 | TCR2EF33_LMCT |  |  |  | TCR2EF33_LMCT:SOT-25 SMV_TOS | TCR2EF33_LMCT
U8 | 1 | BHI260AP |  |  |  | BHI260AP:XDCR_BHI260AP
U9 | 1 | BMP585 |  |  |  | BMP585:LGA9_BMP585_BOS | BMP585
U10 | 1 | DRV2605LDGS |  |  |  | Package_SO:VSSOP-10_3x3mm_P0.5mm | http://www.ti.com/lit/ds/symlink/drv2605l.pdf
VR1,VR2 | 2 | XC6206P302MR |  |  |  | XC6206P302MR:SOT95P280X130-3N

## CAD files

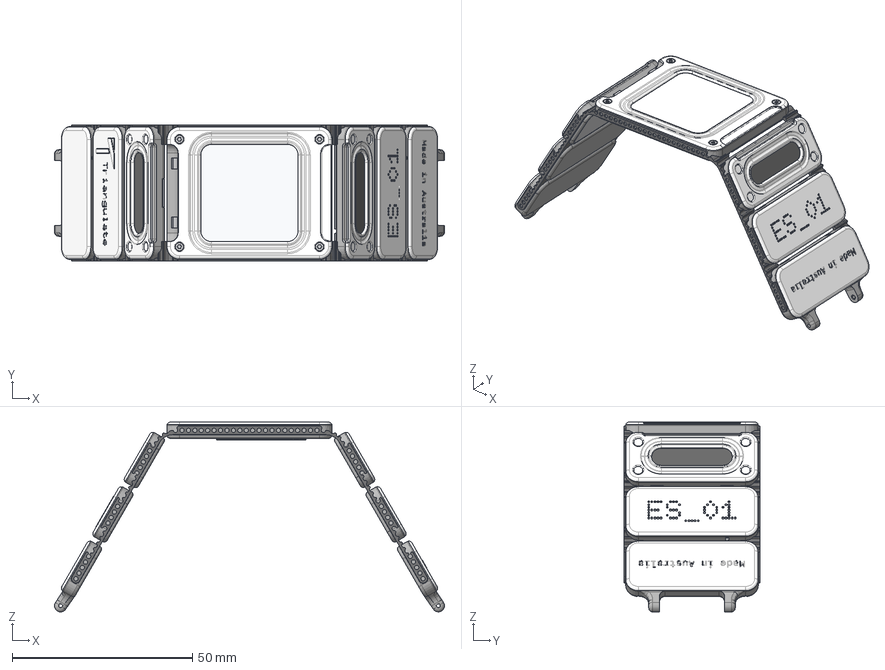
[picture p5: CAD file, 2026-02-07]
CAD/ES_01_FullAssembly.step
108.2 x 37.8 x 52.7 mm

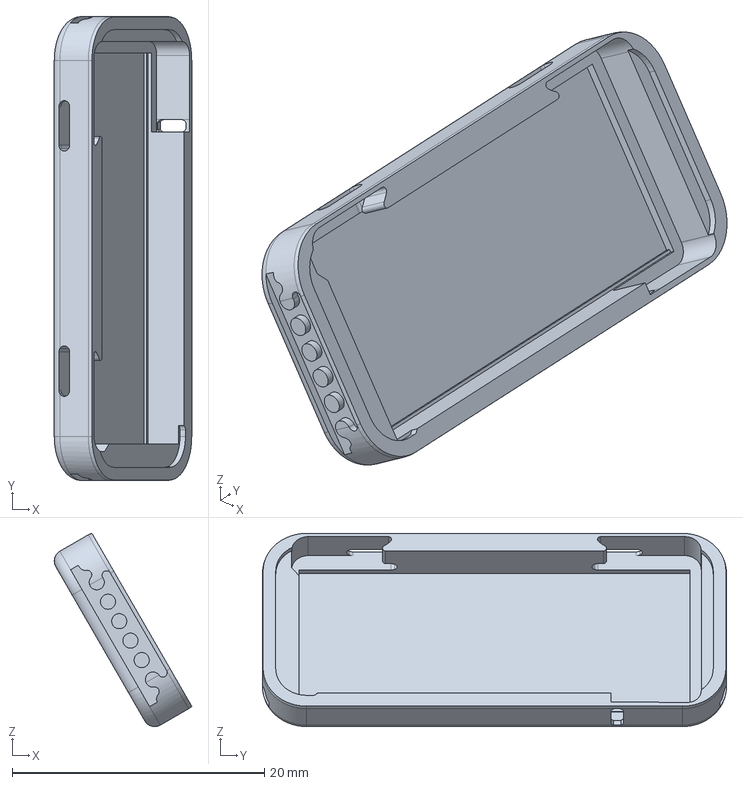
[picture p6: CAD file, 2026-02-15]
CAD/Battery Segment/main case (battery).step
10.9 x 36.8 x 15.3 mm

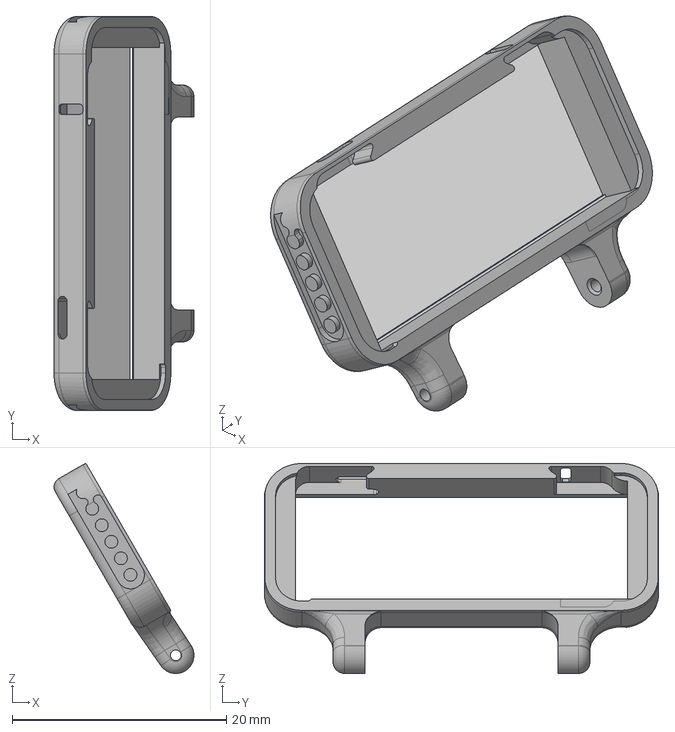
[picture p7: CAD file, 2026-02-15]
CAD/End Battery Segment 2/main case (end battery 2).step
13.1 x 36.8 x 19.6 mm

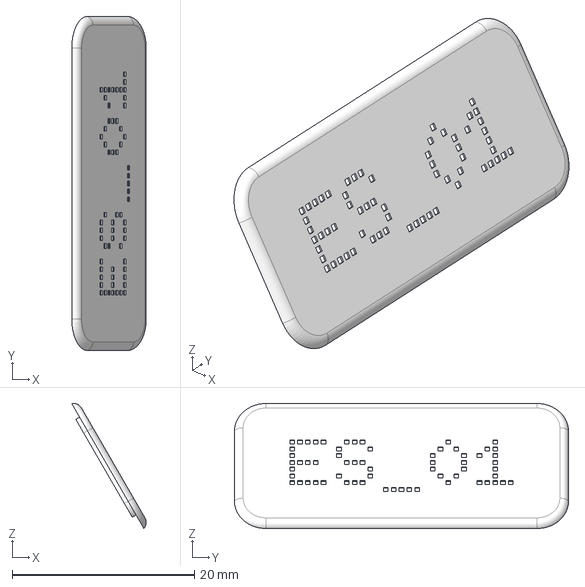
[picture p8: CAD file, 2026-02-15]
CAD/Battery Segment/top plate (battery).step
8.17 x 36.7 x 13.7 mm

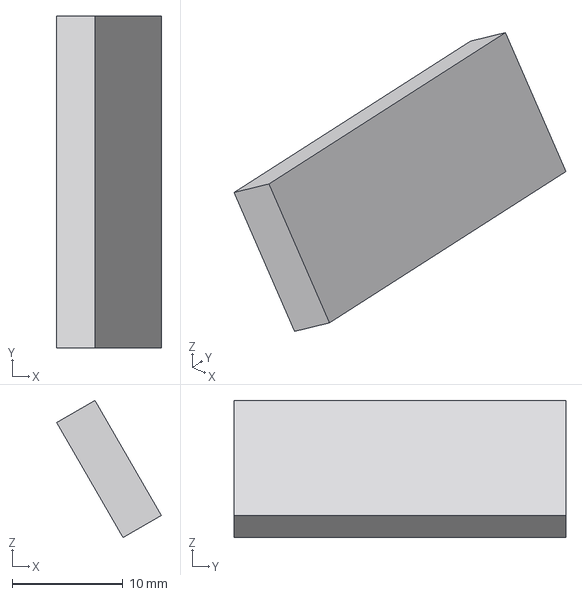
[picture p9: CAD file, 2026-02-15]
CAD/Components (DON'T PRINT)/130mah battery_2.step
9.46 x 30.0 x 12.4 mm

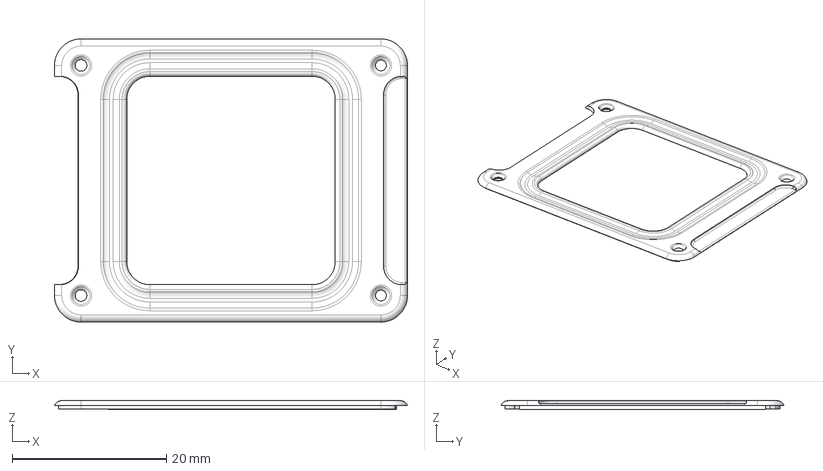
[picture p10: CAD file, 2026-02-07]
CAD/E-Ink Segment/top plate (E-ink).step
45.7 x 36.7 x 1.13 mm

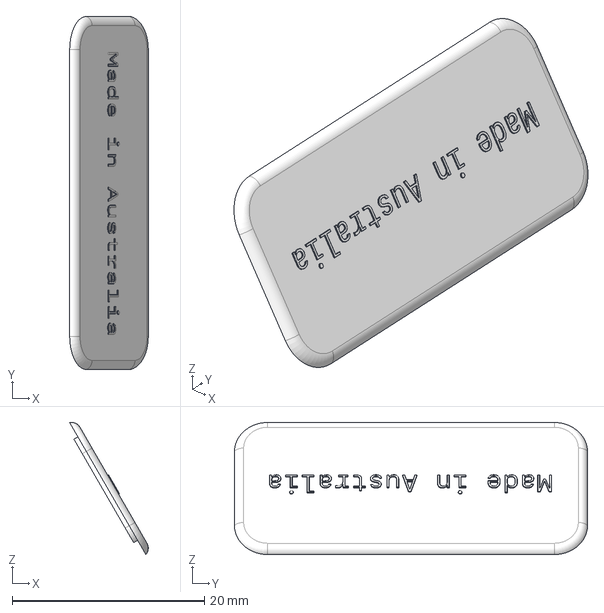
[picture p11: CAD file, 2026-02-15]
CAD/End Battery Segment 2/top plate (end battery 2).step
8.17 x 36.7 x 13.7 mm

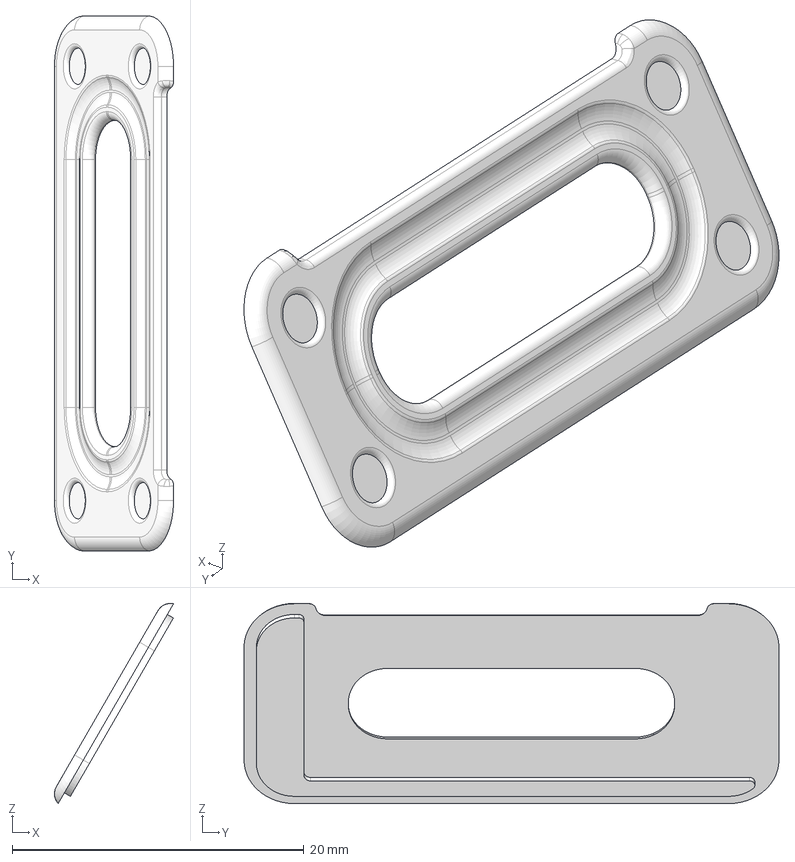
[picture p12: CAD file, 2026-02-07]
CAD/OLED Segment 2/top plate (OLED 2).step
8.17 x 36.7 x 13.7 mm

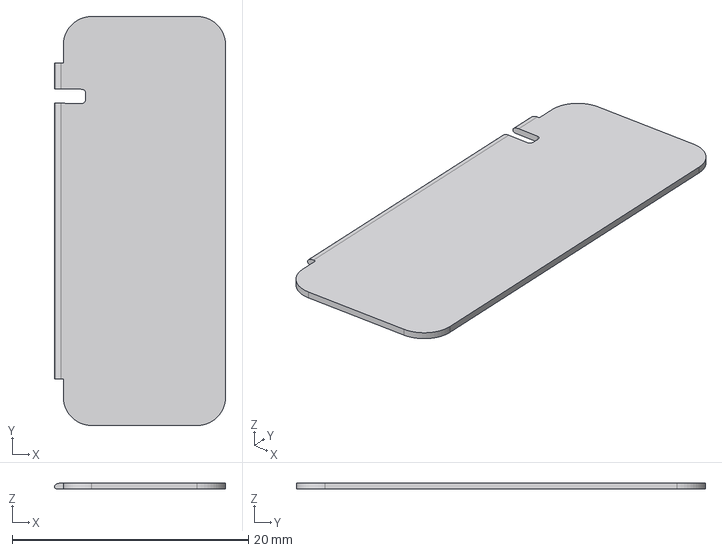
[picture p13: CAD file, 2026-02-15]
CAD/OLED Segment/bottom plate (OLED).step
14.5 x 34.6 x 0.5 mm

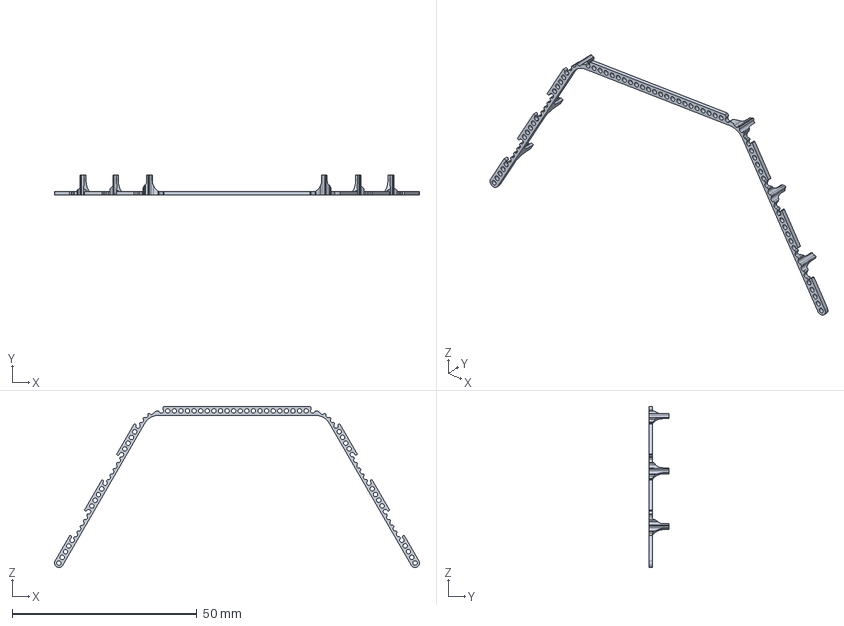
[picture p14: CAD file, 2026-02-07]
CAD/Side TPU Pieces/Side TPU Piece 1.step
98.7 x 5.39 x 43.6 mm

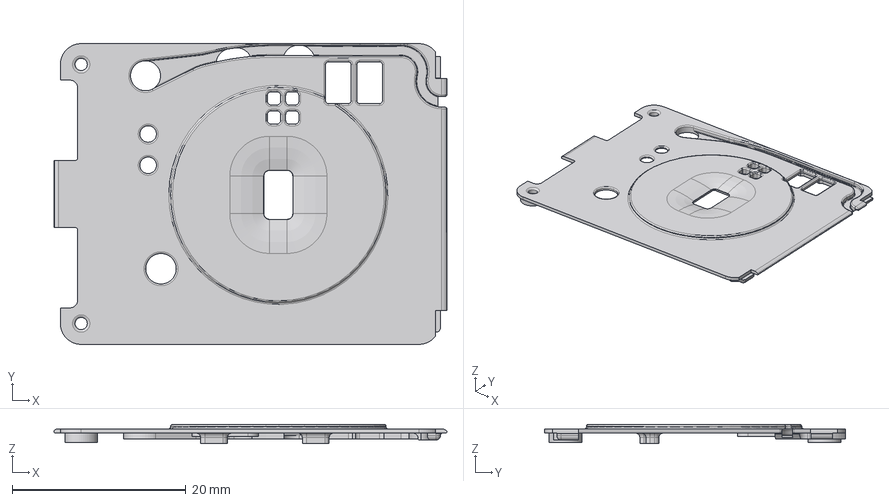
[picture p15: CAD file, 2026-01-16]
CAD/E-Ink Segment/bottom plate (E-ink)(DONT PRINT).step
45.2 x 34.6 x 2.20 mm

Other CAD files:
CAD/End Battery Segment/main case (end battery).step
CAD/End Battery Segment/top plate (end battery).step
CAD/Haptic Segment/top plate (haptic).step
CAD/Components (DON'T PRINT)/130mah battery_3.step
CAD/OLED Segment 2/bottom plate (OLED 2).step
CAD/OLED Segment/top plate (OLED).step
CAD/Side TPU Pieces/Side TPU Piece 2.step
Blender/ES01Render.blend
Blender/assets/materials/black-plastic-ti_b99e844b-22d0-4a01-904a-b68efa6bd27f/black-plastic-tiles_2K_43d20e5f-ffd5-40af-b8ef-8094d5e06349.blend
Blender/assets/materials/black-plastic_7241e7a9-cc3e-4f80-ab34-076465f5e7b7/black-plastic_6acbffe2-8be6-4458-9b88-4d81a32f724b.blend
Blender/assets/materials/black-scratched-_5ea80401-e392-4653-b911-38c41de30f31/black-scratched-plastic_2K_563fd0d4-9b0a-4c85-abd9-2abbef7b1642.blend
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

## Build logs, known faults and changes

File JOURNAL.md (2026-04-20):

<!--
  This journal is auto generated by Hack Club Blueprint.
-->

# 12/5/2025 12 PM - Initial Design  

_Time spent: 3.0h_  

I own a smartwatch which I use throughout my daily life, but there are so many gripes I have about my watch which seems like EVERY other manufacturer includes in their watches as well.

1. The watch's OLED display consumes too much power, and is unreadable in bright sunlight. Although manufacturers have tried to brute-force this problem with brighter and brighter OLED screens, that just increases power consumption and nukes battery life.

Why not use E-ink display technology for this??? It consumes so much less power and works in a way that bright sunlight actually makes the watch MORE readable.

2. The watch is BULKY. Modern smartwatches have become so thick, regularly exceeding 11 or 12mm in thickness. This is not the noticeable for regular use, but during workouts, where the wrist has to bend backwards at large angles (for bench-presses, push-ups etc.), the thickness of the watch digs into the wrist, making it extremely uncomfortable. Moreover, most watch manufacturers place their buttons on the side of the watch, exactly where the wrist contacts it when it bends backwards. This results in me accidentally pausing my workouts SO MANY TIMES mid-bench-press.

Therefore, this watch must be less than 5mm thick at its thickest point, and have NO buttons or touch surfaces on the side.

With this set of criteria, I looked towards finding suitable components for the main aspects of the watch, such as the display(s), battery and haptic motor.

Of course, including an E-ink display was at the top of my list, so I settled on a 1.54-inch panel with touch functionality from Good Display. 
(Link: https://www.aliexpress.com/item/1005005200574055.html)
However, I also remembered some of E-ink's drawbacks which I would have to work around in my design. For example, E-ink does not emit any light, so I would either have to engineer my own backlight/frontlight for the display so that it can be used in the dark, or... I decided to include two tiny 0.91 inch OLED displays alongside the E-ink panel, one above and one below, to show additional information and to show information in the dark.
(Link: https://www.aliexpress.com/item/1005004415958608.html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)

I also wanted this watch to have satisfying haptics, so I did some research into different types of haptic motors and settled on a linear motor (The same kind used in Apple's Taptic Engine) with reasonably beefy specs for MAXIMUM HAPTICS!!!
(Link: https://www.aliexpress.com/item/1005006421331249.html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)

Powering everything were three small (but mighty) 100mAh 3.7v LiPo batteries, which I chose because they are thin, narrow and almost the same width as the other components, so it would be a PERFECT fit.
(Link: 
https://www.aliexpress.com/item/1005006129236699.html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)

After compiling a list of components I wanted to include into the watch, I had some baseline dimensions to morph the design around.



I took the official dimensions of each component listed by the seller, modelled them in my 3D software of choice, Shapr3D, and started moving around the components in 3D to explore my options.



I eventually settled on a linear design, as it was one of my criteria for this watch to be as thin as possible for maximum comfort while wearing it. Placing each component in single file in a single layer was the best way to achieve that. I then brainstormed rough 2D renditions of the final design, making sure the overall silhouette looks aesthetically pleasing.



I settled on a design which splits up each component into its own segment, which are all connected together using a flexible material (most likely TPU) structurally, while a flexible PCB runs through each segment. To make the design as simple as possible, I wanted to design the watch so that it would only use 1 flexible circuit board for the entire device.

And that's about it for now! Now that I have a basic idea as to what this watch will look like, I can start designing the enclosure for it, making it actually manufacturable.

# 12/5/2025 11 PM - Enclosure Design  

_Time spent: 4.0h_  

After coming up with a rough 2D design of the watch, I then hopped onto Shapr3D to model my vision in 3D. Starting off with the segment of the watch which houses the E-ink display, it was very important to the aesthetics for the display to be centred within the segment. However, as the display itself was asymmetric vertically, this resulted in a significant amount of empty space between the top of the display and the border of the segment. Also, the amount of blank plastic surrounding the display made it look blocky. 



But then I remembered: One of the criteria for this watch was for it to not have any buttons on the side, so the top of the watch can be used to house buttons! On top of that, this watch is made from segments that bend relative to each other when wrapped around a wrist. That means that the gaps in between each segment will expand towards the top of the segment, which frees up a lot of space for a human finger to reach into the gap and press a button. Plus, fitting two large buttons into the watch filled up the empty space I talked about previously, and also allowed for some of the blank plastic on both sides (as you can see in the picture) to be cut away, which added more visual depth to the design, making it much more aesthetically pleasing.

Now, up until this point, I haven’t really talked about where the control circuitry for the watch will reside. There must be somewhere where I can fit an ESP32-S3 circuit, a heart rate sensor circuit, an IMU circuit, a haptic  motor driver circuit and maybe a lil amplifier circuit for a speaker. This is where I decided to design each enclosure which houses a display to have two separate sections, one for the approx. 1.5mm display, and the rest reserved for all of the circuitry, elegantly placed on a single flexible PCB which makes its way through the central three segments.




Also, you can see the addition of 2 screws (Yes, you see 4, the other two are fake) to hold the top, middle, and bottom pieces of the E-ink segment together, with the bottom piece having a cool mechanism which lets one end slot into the middle piece (Like the battery cover on a TV remote) and the other end gets secured with the screws, which secures all four corners of the bottom plate. Of course, a smartwatch has to be water resistant, so a bunch accommodations were made to ensure that watertight adhesive could easily be used to join all the pieces. 



After coming up with a sick colour palette for the finished product (off-white for the top and bottom, and grey for the sides), I modelled the segments housing the OLED displays, which basically used the exact thickness and width of the E-ink segment to keep the design consistent. Since the modules were too small to incorporate real screws into them, some stylistic circles were carved into the corners, which again added visual depth to the design. Also, at this time I realised that the display segments were still too bland, so a nice indentation around the display borders was also added.

Next, it was time to design the segments of the watch which carry the batteries, which again used the exact same dimensions as the OLED segments. After adding two batteries to one side and two other segments to the other side, the uniform dimensions of each segment started to make the watch almost look like it has a bracelet made from REALLY chunky links. After me blabbering on about visual depth this whole time, you might be surprised to see completely blank faces on the battery segments, but that was done for two reasons:

A: The thickness of the top piece was WAY too thin for any carvings to be made in it (The battery is 4mm thick and the watch is 4.5mm thick)

B: This part of the watch is barely going to be visible to the wearer, and it should only serve to draw attention to the main focus of the watch, the displays. Plus, it looks CLEAN.



However boring the face of these battery segments might be, I cut some cable channels inside the middle piece for the cables from segments after it to be neatly routed through, as there really isn’t any room in this watch for messy cabling. 



Now, it was finally time to address the aspect of this watch I have been shoving under the carpet this whole time. How is each segment actually going to connect to each other??? Initially, I thought about using hinges to allow for each segment to pivot relative to each other, but that would result in the hairs on the wearer’s writs being caught up in the hinge, and also: How can I fit a reliable hinge between two segments just 1.5mm apart?

Next, I thought about inserting a flexible piece of material between each segment, but that also came with potential drawbacks. Firstly, placing flexible material between segments would interfere with the placement of wires and the flex PCB, and it would be extremely fiddly to print and attach tiny 1.5mm-long pieces between segments.

I then settled on having one continuous piece of rubber-like material (Most likely 3D printed TPU) on each side of the watch, with dedicated sections optimised for where the material will bend. I went with this cool circle design to keep things visually interesting, while cutting away the top part of the structure where it’s designed to bend. Moreover, the places where the material bends are curved into the gap between the segments for extra thickness. Apart from being SO MUCH EASIER to print and assemble, another advantage of this design is that the sides of the watch are also rubberised, which improves shock resistance and durability. 





After adding some 18mm standard watch band attachment points, the overall design is virtually finished!. Of course, some cutouts will have to be made for the heart rate sensor and the charging pins, but that will only be possible after the flex PCB is fully designed, which is what I will be doing next! In the meantime, enjoy some preliminary renders of the enclosure.



# 12/8/2025 - Started the PCB Schematic  

_Time spent: 2.5h_  

Now that I had spent quite a bit of time tweaking and perfecting the aesthetics of the enclosure of the watch, it was time to focus my attention on towards creating the flexible PCB which will precisely fit inside the central three segments housing the displays.



So, I booted up KiCad to start work on the first (and most obvious) part of the schematic of the E-ink smartwatch: The ESP32-S3 circuit itself! I had measured the amount of space I had left underneath the main display in my 3D model, and it turns out that the smallest pre-built ESP32-S3 module I could find was more than a millimetre TOO THICK to fit inside the watch’s enclosure. Well, there went my only chance to include a relatively fail-proof built-in module, so I turned to the various teeny-tiny ESP32-S3 boards I could find, and set about finding the one with the simplest schematic that I could integrate into my project. I eventually found that the ESP32-S3 Zero module from Waveshare had an extremely compact circuit schematic which still allowed for a plethora of pins to be exposed to connect to the various other components of the watch. 

Screenshot 2025-12-06 at 6.55.13 pm
Screenshot 2025-12-06 at 6.55.36 pm

Then I started trying to create a separate schematic sheet for the driving circuits of all the displays, as the panels I selected for my use case needed quite a lot of extra components to function correctly (This was done because of (you guessed it) thickness). I managed to find proper pinouts for the bare 0.91 inch OLED displays I wanted to use, and there are plenty of manufacturers who make simple breakout boards for the displays to be connected via I2C, so I used a schematic from one of those breakout boards and incorporated that into my design as well. The OLEDs would be simple to implement in code as well, as they communicate over I2C and have extensive libraries that the open-source community have created for them.

Screenshot 2025-12-06 at 6.55.49 pm

But I had to address the elephant in the room: The fancy Good Display E-ink panel with TOUCH functionality. After checking the data sheet, I was provided with a nice application circuit for the main 24-pin display, however the pinout and application circuit for the touch panel were nowhere to be found. It was only after reaching out to a Good Display representative that I was directed to a full application circuit intended for an ESP32 (How lucky!!) that utilised the display and ALL of its capabilities! I promptly implemented the schematic into my PCB, making sure to link the I2C lines with the ones from the OLED displays and other devices included in the schematic. Interestingly, the display itself uses a variant of SPI for communication with the microcontroller, which, thankfully, the ESP32 also supports through basically all of its pins.

Screenshot 2025-12-07 at 9.23.48 pm

After implementing a robust 3.3v regulator to power everything, the first half of the schematic was DONE. Now it’s time to focus my attention towards the sensors that will be included in the watch, and also the driver circuitry for the haptic feedback and possibly the loudspeaker!  

# 12/12/2025 - Finished the PCB Schematic  

_Time spent: 3.0h_  



After fully implementing the circuits for the displays and the main microcontroller, it was time to shift my focus to the various sensors and the haptic driver circuit that would enable the smartwatch to take accurate measurements, both of the user and of the environment around it, and also be able to communicate with the user to notify them of events.

First up was to select the main inertial measurement unit (IMU) as that will be used for various functions, like wake up on raise, step counting, calorie/rep counting during workouts and depending on the quality of the IMU used, it can even be used (sort of) as a 3D mouse by using sensor fusion and dead reckoning together to give rough position estimates in 3D space. Since my main ESP32-S3 only has two cores (although quite powerful ones running at 200MHz), I would ideally want to perform a minimal number of calculations on the main microcontroller, as the IMU is one of the sensors which need to be operational almost all of the time, since it dictates when the device sleeps. 

Screenshot 2025-12-12 at 9.04.34 am
Screenshot 2025-12-12 at 9.05.43 am

I then turned to Bosch Sensortec’s line of IMUs, specifically, *smart* IMUs which incorporate their own teeny-tiny microcontroller to handle basic functions such as sensor fusion and even some tiny machine learning models to provide stuff like step counting. I immediately set my sights on their newest and most powerful addition to their lineup, the BHI385, however there was no library, API, or even SDK (to develop custom machine learning models) available for it, as the chip had only been released in September 2025. Looking around for a chip with more community support and established open-source software, I eventually landed on using the BHI260AP, which foregoes some of the more fancy AI-enabled features of the BHI385, but still provides onboard step tracking, wake interrupts, and sensor fusion so that the gyroscope and the accelerometer’s outputs are properly combined together to give an accurate idea of the absolute position and velocity of the watch. Following the application schematic on the datasheet for the BHI260AP was simple enough, but the implementation of this IMU also needed a separate 1.8V (TWO separate 1.8V power rails, actually) power rail to not fry the chip, and that also meant that the I2C signals coming from the chip had to be level shifted up to 3.3V so that it could interface with the ESP32, and I used a simple bidirectional logic level shifter circuit to achieve this.

Screenshot 2025-12-12 at 9.07.14 am
Screenshot 2025-12-12 at 9.07.41 am

Another integral part of any smartwatch is the heart rate tracking, which I decided to implement in this watch using the very well-known (and very well-documented) Analog Devices MAX30102 module, which incorporates the sensor IC, an LED, optics, and a light detector all in one tiny package, which was very convenient as it did not require *me* messing around with those things and possibly blowing something up. The application schematic for this module is also very simple, with it nicely interfacing through I2C and it also having a comprehensive Arduino library which can be implemented into ESP-IDF as a header file.

Screenshot 2025-12-12 at 9.08.21 am

Since I wanted to possibly enable absolute 3D positioning in this watch (using dead reckoning on the IMU), I thought it would be very useful to include a barometer into the build to precisely monitor the watch’s absolute elevation, which can be used for other things as well, such as an estimation of calories burnt during a hike based on elevation change data and many more. Again, Bosch Sensortec has the perfect option for this available, with the BMP585 pressure sensor being one of their most accurate and also happening to be completely waterproof (It is even specifically designed for wearables!). Plus, the sensor itself integrates a large number of components into its own package, which made it so the sensor only required two external capacitors to function!

Screenshot 2025-12-12 at 9.09.10 am

Lastly, I went on a hunt to find the perfect haptic driver for my linear resonant actuator (LRA) motor that I had selected for the watch. After searching online and reading forums, I settled on the DRV2605L from Texas Instruments, as it provides a handy selection of over 100 of its own built-in haptic waveforms, which can all be triggered using simple I2C yet again. Moreover, the chip has comprehensive open-source libraries available for it, one of them being a module specifically designed for ESP-IDF which would slot nicely into the watch’s firmware stack. So I implemented the application schematic for that as well.

Screenshot 2025-12-12 at 9.10.41 am

Looking back at the total of three schematic sheets in the whole project, the schematic and all of the watch’s intended functionality was now fully laid out. Now it is time to lay out all of these components on the PCB. Bye for now!

P.S. You can see the updated KiCAD Files on my Github repository right now!!

# 12/14/2025 - Designed and routed the PCB  

_Time spent: 7.0h_  

Now that the schematic for the main PCB on the ES-01 (Yes, I ACTUALLY came up with a name!!) was finished, I then started to lay out the PCB as it would be in its final form (Spoiler! Here’s the finished layout).

Screenshot 2025-12-14 at 1.22.46 pm

To start, I drew out a rough outline for the flex PCB inside the 3D model, making sure it precisely matched the dimensions of the space I had left for it in the enclosure. Since the PCB is supposed to flex between the different segments of the watch, I also accounted for the length of the PCB that would be lost due to it bending in the enclosure, which added roughly 4mm to the length. After modelling the PCB’s shape, I exported its sketch in an SVG file, which I imported into KiCAD as the board’s Edge Cuts layer.

Screenshot 2025-12-14 at 2.26.11 pm

Then, after selecting and assigning various footprints to the custom libraries I uploaded while making the schematic, it was time to place all the components. I determined (and locked in) the placement of the four display connectors (Yes, four, because the E-ink panel’s touch feature needed its own connector), the heart rate sensor and the battery and haptic motor pads, which corresponded to holes cut out for their wires in the enclosure. 

Soooooo, I decided to tackle probably the toughest-to-wire and most complicated package in my PCB FIRST, which was the ESP32-S3 chip. I decided on placing this sorta in the corner of the PCB, which allowed for *just* enough room above and ton the left of it for me to place the circuitry needed for WiFi and Bluetooth, a BUNCH of decoupling caps, and other circuitry for stuff like the external crystal oscillator. I decided to go for a 4-layer flexible PCB to base my design on, as I *really* need ultimate thinness, and flex PCBs start at just 0.2mm thick (even for 4-layer boards, that’s CRAZY). I’m proud of the way I efficiently placed each component so that it maximises the space used on the top of the PCB while minimising trace length as much as possible. However, to achieve this incredible component density, I did have to use some goofy routing in my internal and bottom layers, which you’ll see later as the board started to become more crowded with components…

Screenshot 2025-12-10 at 2.10.48 pm
Screenshot 2025-12-10 at 2.55.14 pm

During this time, I also placed the pads for the watch’s connection to its charging/programming dock, after which I realised that having exposed pads… with a DIRECT electrical connection to the 3.7v Li-Po batteries AND the internal power management unit was maybe a little bit of an oversight in terms of safety, cause literally ANYTHING could find its way onto those pads, short the batteries, and BLOW UP THE WATCH. So I added two beefy diodes which limited which way the current could go, as I only intended to use those pads for *supplying* power to the watch, not the other way around. With my configuration, it is also possible for a USB device to supply a clean 5V to power the whole watch without the 3.7v from the batteries, buuuuut that probably won’t be used if I’m already going to implement a battery charging circuit in the charging/programming puck thingy.

Screenshot 2025-12-14 at 2.27.51 pm

When routing the wires for the main display’s connector, things really started to get packed, with me having to resort to using quite a lot of vias (and some crazy precise placement to not violate design rules) to route the SPI and various other signals from the display to the ESP32 chip. It only got worse while routing the wires for the heart rate sensor and the two other sensors, however the wiring for those components could just connect to the shared I2C bus throughout the whole PCB, so that saved MANY vias from being placed near the main chip. There, the main section of the PCB was basically done, but I still had to route the power signals… See, what I had done up to this point was that every time a component needed a connection to the 3.3v or 1.8v power rails, I just placed some vias there in the hopes of connecting them all together when I had fully routed all the signal traces. When the routing for these traces was done, however, there was basically no space left in ANY layer to route the power rails, and so I was left stumped. I even considered switching to a 6-layer flex PCB, but that would drive costs SKY HIGH, limiting how many iterations I could make of the PCB. So I did the difficult task of carefully rerouting a bunch of the signals to make way for 3.3v and 1.8v power traces of acceptable thicknesses which could accommodate the power needs of every component. 

Screenshot 2025-12-14 at 2.28.57 pm

Thankfully, I managed it, which then just left the two auxiliary parts of the PCB to be routed. These would include the two OLED display circuits and the haptic motor driver, which were thankfully very easy to route together, because there was quite a lot of space on these two sections.

Now to spend a couple of hours fixing OVER 100 DESIGN RULES VIOLATIONS that I had somehow missed during the design of the board, and then it was time to finally move on to the silkscreen layer and add some *flair* to the PCB. I opted to use a very small 0.4mm text size for all the component designations (simply because there was only enough space between said components for that size), and added some nice logos and text to the board, tying up the whole design nicely. I added a custom layer for JLCPCB to apply plastic stiffeners to the parts of the watch which DON’T bend, and finally, FINALLY the first version of the completed PCB was DONE.

Screenshot 2025-12-14 at 2.37.20 pm

Since I’m using a 4-layer Flex PCB, the manufacturing costs were quite high on JLCPCB, with my putting in a quote and seeing the price of just 5 boards at just less than $150 Australian dollars (that’s basically $100 USD for the Americans). Yikes. (I think it’s time to go tier 1???)

# 12/17/2025 - Budgeting!!!  

_Time spent: 4.5h_  

After finalising the design of the PCB, I exported all of the production files for it onto JLCPCB, which (through the KiCAD Plugin for JLCPCB I used) also left me with the bill of materials file which I uploaded into JLCPCB’s automatic parts selector. I previously wanted the PCB to be assembled by JLCPCB, but that resulted in the cost for only two PCBs rising to over $400 AUD, which would eat up a significant portion of my allocated budget. Instead, I have chosen to assemble the PCB myself, with the aid of a metal stencil that I will order from JLCPCB and the tools I have for solder reflowing (I have already assembled SMD PCBs before, so I also have experience).


*nice image for banner lol*

Screenshot 2025-12-17 at 11.53.33 am

Finding parts on JLC that suited my requirements, the parts needed to assemble one PCB totalled a much more modest $48 AUD, with the actual PCB and stencils totalling $180 AUD (including shipping) for one iteration. That brings the total cost of the PCB to $228 AUD, which is just over $151 USD (Well under my budget!).

Screenshot 2025-12-17 at 11.50.33 am

However, I have run into a major problem relating to the enclosure design for the ES_01 watch. A lot of the smallest parts that make up the enclosure were too small to be printed by JLC3DP, so I have to revise the design and merge some of the smallest base plates of the battery and haptic segments into the larger main enclosures. This left the bottom plates of the OLED segments that were too small to be printed in any JLC3DP machine, so I decided that the bottom plates of the three central segments (E-ink, and the two OLEDs) will be CNC machined out of aluminium. This, as well as making the small OLED bottom plates manufacturable, will also place metal directly above the heat-generating components of the watch, such as the ESP32-S3 chip which generates quite a lot of heat when doing compute-intensive tasks, especially with any wireless tasks like Bluetooth and WiFi.

Also, having the bottom plates be made from aluminium will add additional rigidity to the watch, and also make it look much more aesthetically pleasing. After quoting the cheapest possible options for 3D printing the remaining parts, CNC machining the bottom plates, fabricating the PCB and obtaining the PCB’s components, the total cost of everything from JLC (including shipping) came to $295 AUD, which is roughly $196 USD. Additionally, the total cost of the rest of the components (E-ink display, two OLEDs, missing PCB components JLCPCB did not have) is approximately $70 AUD, which is roughly $47 USD. 

Therefore, the total combined cost of the ES_01 watch at this point is $243 USD. This cost might also increase with the additional charging/programming puck I have yet to design, but the manufacturing of that component will be quite cheap, so my current estimate on its cost is less than $10 USD. Accordingly, I have updated my requested grant from Hack Club to $250 USD. Yippeeee! Now I actually know how much this thing will cost!! Full compiled BoM coming later!  

# 12/22/2025 - Finishing Touches on the 3D Model  

_Time spent: 4.0h_  

Now that I have basically finished the design of the first version of the ES_01, it was time to focus on making some finishing touches to make the project *perfect* and ready to be manufactured.

u74837684

First up, I assigned each and every component in my KiCAD PCB to its own 3D STEP file, as a bunch of the packages I had used were from external libraries from Ultra Librarian and SnapEDA. Finding (in some cases, creating), assigning and aligning each 3D model to its respective PCB footprint took about two hours of work, after which I was ready to finally export the full PCB’s 3D model from KiCAD.

pcbrender

After importing the PCB 3D model into Shapr3D, I checked the fitment of the PCB inside of the watch’s enclosure (IT FITS!!) and also started to work on the bottom panel of the segment of the watch which holds the E-ink panel. This component had to be modified now that the PCB that sits above it has a bunch of parts which require extra clearance. I created holes for the 5 or so components on the PCB which stick out the most, and also created holes that expose the contacts for charging the watch and programming it. 

Most importantly, I created cutouts for the heart rate sensor and the pressure sensor (they need cutouts for obvious reasons) but then I also created a raised section around the heart rate sensor so that it would provide clearance for air to make its way to the pressure sensor, and so that the two diodes which stick out the most would not dig into the wearer’s wrist uncomfortably. Plus, this raised section allows for a gentle fillet into the cutout for the heart rate sensor, which will hopefully guide the wearer’s skin towards the sensor, potentially improving accuracy.

bottomplate64724

Also, I previously discussed the benefits of an aluminium bottom panel for providing thermal relief to the ESP32-S3 chip, so I made a raised section towards the chip which aims to contact it directly (through a thermal intersect material like thermal paste) and dissipate its generated heat through the whole panel. Moreover, I made use of the electrical conductivity of aluminium to act as EMI shielding for the circuits in the watch. To achieve this, I created more raised sections towards the PCB which directly connect to exposed GND pads in the PCB (which I designed to connect together analog and digital grounds).

This shielding is especially useful for the U.FL patch antenna I plan on routing through the watch (for Bluetooth and WiFi), which will now have a nice EMI-shielded path for the antenna’s cable (before the actual patch in the patch antenna) to go through to minimise noise. 

insideESP32

At this point, I realised that maybe the bottom plate for the E-ink segment was too complicated to CNC machine, especially with the many tiny geometric features I had modelled into it. So I looked towards getting this part 3D printed out of stainless steel, and it is nearly 3 times less expensive to do so! While CNC-ing this part would cost about $36 AUD, 3D printing it only costs about $12 AUD! (Plus, I’ll save some poor CNC machinist the pain of machining such a complex part).

bottomsidefinished

Now, the full 3D model is basically done, and now it’s time to focus on polishing up my project (especially the GitHub repo) with some PROPER renders (not in Shapr3D, but BLENDER!!!) of the whole thing!

# 12/25/2025 - Finished Blender Renders  

_Time spent: 3.0h_  

To polish up my repository so that it passes the design review, I set my sights on creating some really pretty renders of the ES_01 in Blender, where I had WAY more flexibility for lighting and scene design than in the native model renderer in Shapr3D. Importing a model with THOUSANDS of components (thanks to the very detailed PCB model 😅) while preserving colour information for each of them was not very straightforward, however, and required multiple exports into multiple file formats. This continued until I found that exporting into a USDZ file finally retained material information that Blender could recognise. 

Of course, this was only for the PCB model, as I planned on assigning more visually advanced materials to the rest of the components which would make the whole watch look even more realistic.



I then decided that it would be a good idea to bend the watch and actually show what it would look like on a human hand, which required me to create an armature rig for the watch and also required importing a Blender model of a human hand (The BlenderKit add-on was EXTREMELY useful for quickly importing materials and external models).

In the end, I was left with 10 really nice-looking renders (while using all my Blender skills) that I have now updated the Readme on my repository with! Now I just have to add the final touches (Journal, full BoM on repo) and I’ll be ready to submit this project for a design review!!!

render4render3
render7render5
render10render9render8render2render6render1

# 1/13/2026 - Started working on firmware and implemented displays  

_Time spent: 5.0h_  

After a restful holiday (and some feedback from Blueprint reviewers that I should include firmware), I set out on a journey to learn ESP-IDF (the main FreeRTOS-based framework used to develop REAL apps on ESP32) and to implement components for all of my physical electronic components in the watch, and most of all, to make them all work together. That is my main goal for now.

Screenshot 2026-01-09 at 7.30.36 pm

First of all, I assumed that ESP-IDF would have way more support from the community as in most components I would need would have already been available, much like the situation with libraries on Arduino. I was wrong. I only found one component to drive my main e-ink display, and that required me to completely change my ESP-IDF project from C to C++! 

Screenshot 2026-01-09 at 7.29.53 pm

I was not having that, so I turned to the sample Arduino code that GooDisplay themselves provided as a demo for their e-ink display on ESP32. As this was written in Arduino in C++, it did require major changes to the code to be able to import it into my project as a component, and ChatGPT assisted quite a bit with actually interpreting the COMPLETELY COMMENT-LESS code and condensing the functions into simpler versions compatible with ESP-IDF.

Screenshot 2026-01-10 at 7.19.42 pm

And there it was! A display driver for the SSD1681 driver IC (used in my e-ink display) which supported all the fancy features listed in the data sheet, namely the screen’s ability to perform partial refreshes (which only take 0.3 seconds) and fast refreshes (which only take 1.5 seconds). Next, I had to try and figure out how to implement touch functionality in my project using the e-ink display’s built-in FT6336 touch driver IC. Again, I turned to the internet to hopefully find a nice, well-maintained open-source component I could use, but alas, I had to resort to the same thing I did with the e-ink display. I used the demo code from GooDisplay and got ChatGPT to assist in writing a driver for it.

Next up was actually figuring out how LVGL works. See, to create nice-looking UIs on ESP32, you can pick from a bunch of different libraries, but none is as full-featured and as FREE as LVGL. Buuuuut with such a full-featured library comes a complicated API to use. Eventually, I figured out display flush callbacks and also learnt a surprising amount about how LVGL actually works, and I was able to successfully link my touch driver and e-ink driver with LVGL.

Now here’s where a HUGE roadblock showed itself. I wanted to add in the two OLED panels which use the SSD1306 driver IC into LVGL. Since this is a very widely-used display in the world of Arduino and ESP32, I found a bunch of drivers for it, the most-used ones developed by Espressif themselves. I found a particular component which was actually built into ESP-IDF itself, and didn’t need importing into my project at all. So I implemented the component into my project, and added two of these displays to my LVGL instance, but when I tried to build the project, it kept saying that it couldn’t find that built-in component at all. That’s when I found out that that component was only added in ESP-IDF 5.3 and later, and my project was in ESP-IDF 5.1. So I changed the version, but all of a sudden, several MORE errors which hadn’t been there before began to appear. The WHOLE PROJECT was filled with red and yellow lines. Feeling utterly hopeless, I turned to ChatGPT again, which explained all the changes Espressif made between 5.1 and 5.3, and that I was using functions and structs which had been renamed and revised. After implementing ChatGPT’s suggested fixes…

Screenshot 2026-01-12 at 10.20.56 pm

IT BUILDS!!! IT FINALLY BUILDS!!!!!!

Now that the main displays are implemented, I can write the logic for BLE and the other sensors, like heart rate and altitude.  

# 1/16/2026 - Implemented IMU and pressure/temp sensor in firmware  

_Time spent: 4.0h_  

After finishing my implementation of the first actual sensor that is in the watch’s PCB. I turned to implementing logic to control the next most important sensor in the whole project, which is the Bosch BHI260AP intelligent inertial measurement unit. What makes this IMU “intelligent” (and it’s also the reason I chose it for this project) is that Bosch have integrated not only a pretty accurate 3-axis accelerometer and 3-axis gyroscope into its package, they have also integrated an adorable little microcontroller into the same package which runs its own firmware, complete with algorithms which enable all sorts of cool functionality in the form of virtual sensors which the ESP32 can read data from.

render1
*Nice image for banner lol*

Screenshot 2026-01-16 at 6.47.09 pm

For example, the BHI260AP has its own internal sensor fusion algorithm which lets its microcontroller do some complex maths to give the ESP32 an idea of its general orientation, which is accurate enough to be used in VR game controllers and head tracking applications. Furthermore, the BHI260AP also has its own step-tracking feature, which runs a teeny-weeny little machine learning model (you heard that right) to detect and count every step when its mounted on a user’s wrist or placed in a pocket (Hmmm… I wonder what smart device is mounted on the user’s wrist?). Even better, the BHI260AP can send an interrupt signal to the ESP32, telling it to wake up because ANOTHER algorithm on the sensor said that the user raised their wrist to look at the smartwatch’s display. 

Screenshot 2026-01-16 at 6.47.50 pm

ALL of the functions I have just said were implemented into the ES_01’s firmware, and having all of this happening on the sensor’s microcontroller frees up SO MANY resources on the main ESP32-S3 chip. Moreover, Bosch provides their own APIs which just drop into ESP-IDF and (most of the time) just WORK. I only needed a little bit of assistance from ChatGPT for this one, plus I learnt so much from this coding adventure.

It was also at this time that I realised that for the interrupt function between the BHI260AP and the ESP32 to work, I had to add a logic level converter which converts from 1.8V logic (used by the BHI260AP) to 3.3V logic for the interruption to work. That then required a change in the PCB schematic, where I added a transistor and a couple of resistors to do the job, and was luckily able to find enough free space on the PCB to make room for those extra components. I also didn’t need to update the BoM since the minimum order quantity for all the resistors I’ll order are like 50 anyways. 

Screenshot 2026-01-16 at 6.48.46 pm

Next, it was time to integrate code for the Bosch BMP585 sensor to work in my firmware, which required a process very similar to that of implementing the other Bosch sensor. Actually, this one was much easier to do as well, since the BMP585 is way “dumber” than the BHI260AP, and so behaves much more like a normal sensor where it just spits out values and doesn’t care. Therefore, the API Bosch provided for this sensor was also much smaller and friendlier to an amateur like me.

Screenshot 2026-01-16 at 6.49.23 pm

Finally, with the newfound functions and callbacks I had gained access to, I wanted to create a main task that schedules when the watch should sleep and wake up to hopefully make the battery last longer than the ones in the watches from a certain trillion-dollar fruit company. That required setting timers for when the ESP32 should go to sleep and wake up, and I implemented logic which would only wake up the watch every so often to take heart rate (the most power-intensive) measurements, and then force it back to sleep.

Screenshot 2026-01-16 at 6.49.53 pm

Anyways, this firmware is progressing very well, and I’ve finally done the task of integrating all my hardware and making my software recognise it. I also think I’m pretty close to resubmitting this project for review, and the next things to do in the firmware is to tackle another beast: the USER INTERFACE!!!  

# 1/20/2026 - Added support for DRV2605 haptic driver in firmware  

_Time spent: 1.5h_  

After submitting my project for review, a strong urge came upon me to continue the development of the ES_01's firmware IMMEDIATELY after. Now I understand why people code for a living, the profession just drags people gravitationally towards it. Jokes aside, I still hadn't integrated the last piece of hardware into my ESP-IDF project, which is one of the most important for cool factor, the DRV2605 haptic driver.

render5
*cool image for the project banner lol*

First of all, I searched the ESP-IDF component registry for a library that could provide an easy path to integration, and my search was successful. I came across the DRV2605 library in the espp project, but upon downloading the component, I was shocked to see that it is written in C++ and is meant for ESP-IDF projects written in C++! I *could* possibly try and smash it into my project by using a bunch of C to C++ linker wrappers, but I decided that implementing I2C mutexes into the library's own I2C functions would be WAY too cumbersome.



See, an I2C mutex is what FreeRTOS uses to orchestrate I2C bus access across different tasks. Because my sensors and OLED displays each have their own tasks, but all share a SINGLE I2C bus (the same two wires), then a bunch of tasks running independently of each other would try and access the shared bus at the same time, which causes things to break SPECTACULARLY. An I2C mutex ensures that each task has to wait for other tasks to finish their I2C transactions before taking control of the bus for themselves. It was already a chore to go into all my hardware component files and tell them to manipulate an I2C mutex, but doing that IN C++!? Hell no.

The only other DRV2605 library I found was one made for Arduino, which again, USES C++. After I was done crashing out at letters on a screen, I asked ChatGPT as a last resort to hopefully conjure up a clean ESP-IDF component (in C) which supported the many features of the DRV2605 (namely the ability to select from the chip's built-in library of haptic effects). And the component it spat out was surprisingly simple, and IT BUILDS!!!



This journal entry was quite short, but I'm going to post another one like, today, which explains the ordeal of trying to develop UI for this thing. Byee!  

# 1/21/2026 - Found a suitable UI editor and started building the UI  

_Time spent: 5.0h_  

Time to finally tackle the task of trying to make something PRETTY display on the ES_01’s screens! That task was MUCH easier said than done, as I will explain in this journal entry. I initially configured my ESP-IDF project to use the Light and Versatile Graphics Library, or LVGL for all of its UI needs, so I passed display refresh callback functions to LVGL and initialised an LVGL task in my main firmware. Now I just needed to find an editor for it which would let me drag and drop LVGL widgets precisely where I want them on the screen. I figured that doing this programmatically would be HELLA cumbersome, and would require a bunch of trial and error to make sure things are aligned.

render6
*nice image for banner once again*

Good thing for me, there are exactly three good LVGL editors grazing the web right now, with the first one I tried being the VERY newly introduced LVGL Pro Web Editor. It’s only on version 1.0  right now, so it was riddled with bugs, such as straight-up NOT BEING ABLE TO CREATE NEW FILES. Instead of submitting an error, I thought it would be faster to switch to the desktop version of the LVGL Pro Editor, which, after only giving me a 30-day free trial, decided to actually work… until it stopped working when I switched from doing my project on Mac to doing my project on my Windows PC. The same story happened for the LVGL Pro Editor’s VSCode extension.

Screenshot 2026-01-21 at 11.09.42 am
*i know this one says "No repository found", I took this screenshot like right now*

After that, I had had ENOUGH of this LVGL Pro editor (which, by the way, only lets you add stuff programmatically via a separate XML language I had to learn). I abandoned my very basic UI project and switched to the other editor on the market, SquareLine Studio. Upon activating my very basic and feature-limited free license (only a maximum of 10 pages!? Are you serious?), I was greeted by a user interface which forced me to use one of the 15 or so curated boards with displays of different resolutions to mine. “Ok, maybe I can just change the display resolution and bit depth once I’m in a project” is what I assumed with hope, until that hope was crushed by  the unyielding software. It DIDN’T LET ME CHANGE THE DISPLAY RESOLUTION!? 

Screenshot 2026-01-21 at 11.11.30 am

Once AGAIN, I had enough of SquareLine Studio, and then moved to using EEZ studio for UI modelling. STILL, there were headaches, because EEZ studio does not support projects with multiple displays, so I had to create separate UI projects for each of my displays. That isn’t really a problem however, as I can just modify the C logic generated by EEZ studio to use callback functions which synchronise the pages displayed on my OLEDs with the page displayed on the E-ink panel. Moreover, I can also modify the code to call a function that triggers haptic feedback every time I press a button on screen.

Screenshot 2026-01-21 at 11.11.57 am

After finally, FINALLY settling on an editor, now I can share my UI-building experience with you. After figuring out how to change pages with buttons on EEZ studio, I managed to build a really nice-looking main launch screen, and two cute launch screens for the OLEDs as well. This was also the time where I made my font and icon choices, and I really have to give credit to Google Fonts, which provided both really high-quality fonts and icons completely free of charge. It’s much better than some virus-riddled website named “really-cool-legit-fonts.com” or something.

Screenshot 2026-01-21 at 11.12.26 am

*this is how the UI will appear to the user, OLED1 at the top and OLED2 at the bottom*
Screenshot 2026-01-21 at 10.49.31 am
Screenshot 2026-01-21 at 10.49.05 am
Screenshot 2026-01-21 at 10.49.41 am

During the process of building the launch screen, I also got an idea of the general design direction that this UI will take, which aims to make the most of the monochrome-ness and the crazy low resolution of all three display panels I am using. After that, I designed the UIs for the main watch face, which carries across all three displays, showing a ton of useful information beautifully.

Screenshot 2026-01-21 at 10.51.40 am
Screenshot 2026-01-21 at 10.51.28 am
Screenshot 2026-01-21 at 10.51.50 am

The upper OLED (which is called OLED1 in my project) shows the current time (That is because in the dark, the e-ink panel won’t be visible, so you can tell the time using the OLED) and the current weather conditions, which it will hopefully connect to a phone and use its weather service to obtain. The main e-ink panel shows the time (again, but prettier), the date and a bunch of sensor data, like steps, heart rate, altitude and finally, battery percentage (uhhhh, I actually have no way for the ESP32 to measure the battery percentage in my PCB right now…). Next, the bottom OLED displays notifications, with it showing the number of unread notifications and also showing a preview of the most recent one. This functionality will be implemented using BLE ANCS functionality on iPhone (which thankfully, the ESP32-S3 supports).

Next, I built the screens which show on the OLEDs during workouts, showing sensor data such as heart rate (with a really nice animation), number of reps or distance travelled (The Bosch BHI260AP can approximate this using dead reckoning and also step data). The top OLED continues showing the current time (in case you like working out in the dark?) and the time elapsed since the workout started. I chose to place these rapidly-changing stats on the OLEDs to reduce the number of refreshes the E-ink display has to do, which saves a bunch of power. I haven’t built the workout UI for the E-ink panel yet, but it will most likely be a bunch of buttons to control the workout, such as pausing/ending, and maybe even a counter.

Screenshot 2026-01-21 at 11.14.49 am
Screenshot 2026-01-21 at 11.14.57 am

So far, this UI doesn’t look so bad, and I tried to make it different to the various cloned UIs that most smartwatches use, while still making it look neat with concentric rounding radii and leaning into the low-resolution, monochrome nature of the displays.  

# 1/25/2026 - Implemented Workout and Barometer "Apps" in UI  

_Time spent: 6.5h_  

After creating the basis upon which the ES_01’s user interface will be built, including the all-important design and aesthetic direction I would be heading, it was time to flesh out the watch’s basic navigational UI (basically, how is the user going to get around the different “apps” and functions of the watch?).

render10
*unrelated, but cool render of the watch's enclosure (for the banner)*

Screenshot 2026-01-25 at 9.49.55 am

First of all, I have decided to go with an “apps” structure for how functions will be laid out in the watch, with each sensor reading or calculated value appearing in its own “app” complete with other relevant stats and numbers. This is quite similar to how many low-cost smartwatches structure their UIs, such as examples from Huawei. Higher-end watches like the Apple Watch and Samsung Galaxy watches use a more “phone-like” approach to their UIs, where most raw sensor numbers are calculated into insights or trends for the user to see. This, of course, introduces A LOT of computing overhead, which the beefy chips in those high-end watches can easily handle. The same cannot be said about the ESP32-S3 I am using.

So, I needed to create a “Home Screen” of apps on the ES_01, but I was significantly limited by the capabilities of the e-ink display I am using. Since even a fast refresh of that panel takes about 1.5 seconds, it would be INSANELY clunky for the user to be able to scroll through the various apps and menus in the UI. Plus, the goal with any E-ink display is to do as few refreshes as possible, because even though the panel consumes no power when its just sitting there, refreshing the panel consumes quite a lot and frequent refreshes can outweigh the power savings e-ink panels are known for. That’s why I decided on reserving the top of the watch’s screen EXCLUSIVELY for navigation buttons, like forward, back and switching between tabs.

Screenshot 2026-01-25 at 9.50.49 am

Placing the navigation buttons in a consistent place, and always colouring them in white creates a sort of muscle memory for the user, very similar to how Android phones always have the back button on the bottom of the screen. I have also designed the placement of each back button in my UI to make it so that if a user keeps pressing the top-left corner of the screen repeatedly, they will always end up back at the watch face. Also, since my “Home Screen” only has two pages, it’s not that bad to navigate between them using buttons.

Most of the “apps” that I will develop for this watch will have more than one page, in which case I have settled for using a “tab switcher” element at the top to switch between two or more pages. This makes sure the user can switch between every page very easily, and doesn’t have to use back and forward buttons which they could easily get lost in the UI with.

Ok, Ok, enough about me blabbering about the UI’s actual design, let’s get to the two “apps” that I have implemented so far. First on the list is one of the most complicated “apps”, the Workout app. Clicking on its icon in the Home Screen takes you to the New screen, in which you can choose your workout to do right now, or you can switch to the Stats screen, which shows your workout activity in a zoomable graph, and your three favourite workouts plus how many times you did them.

Screenshot 2026-01-25 at 9.51.47 am
Screenshot 2026-01-25 at 9.51.53 am

Selecting a new workout takes you to the active workout page, which starts the workout (which will be a task in ESP_IDF) and shows you your total calories burned, pause and end buttons, and a HUGE button that maps to a counter which can count pretty much whatever you want. If you’re running or cycling, you can use it to count laps, or you can use it to count sets if you’re weight training. It’s super useful, and I haven’t really seen it implemented in any other watch. On this screen, you only see one stat. This is on purpose, as most of the workout data is shown on the OLEDs, as the data is rapidly changing. Calories only update like once every 10 seconds, so that’s fine to show on the E-ink display. I have specifically designed the buttons in the active workout page to be as large as possible, so they’re easy to press in the heat of the moment.

Screenshot 2026-01-25 at 9.52.26 am
Screenshot 2026-01-25 at 9.52.48 am

After pressing the End button, you are taken to a confirmation screen which asks you whether to actually end the workout, and if you press End, then you are taken to a workout summary page specific to the workout you just did. This shows a graph of either heart rate, calories, or distance/reps over time (By tapping the button that says “Tap”), and also shows average heart rate, calories and the total time spent in the workout.

Screenshot 2026-01-25 at 9.53.19 am

That’s the workout “app” done, after which I moved onto creating the Barometer “app’s” UI. This consists of two pages, one showing the current altitude and stats relating to it (including a zoomable graph), and an identical page showing the same data about air pressure in hPa, which can be used to roughly forecast weather. I have also mapped the Altitude icon in the watch face to this app.

Screenshot 2026-01-25 at 9.53.43 am
Screenshot 2026-01-25 at 9.53.50 am

There we have it! The first two “apps” are fully fleshed out, and there are now six to go!

# 1/31/2026 - Activity, Vitals, Notifications, Timekeeping, Weather apps!  

_Time spent: 5.5h_  

Ok, I have been HARD at work relentlessly trying to complete this UI, because I have created 7 of the 8 "apps" that form all of the functions that the ES_01 is capable of. The first of the "apps" created during this time is the Activity "app", where it provides the user with all the information regarding step count, exercise time and total calories burned during the day. The Activity "app" has easy-to-read arcs which visualise the total percentage of each of the three tasks, which all get their data from the watch's sensors and user actions. The number of steps, exercise goal and calorie goals can also be adjusted by the user, and all of the visualisers in the Activity "app" reflect those changes. Much like most of the "apps" in the ES_01's UI (Which I have named es_OS), the Activity "app" has two pages, with the other page showing a zoomable graph of each of the activity parameters. This allows users to see trends in their performance and activity levels, with a button cycling through all three parameters at the bottom.




Next up was the design of the Vitals "app", which provides real-time data from the MAX30102 sensor in the watch. This "app" is very similar in layout to the previously-designed Altimeter "app", with there being a dedicated page for heart rate and blood oxygen levels, with each page showing current values as well as zoomable graphs.




After this, I decided to tackle the challenge of implementing a proper way for users to receive and view notifications, which started with a "pop-up" notification page. This page is shown by ESP-IDF whenever there is a new notification, with the page showing a maximum of 9 lines of text to show as much of the notification's content as possible. Since this page will interrupt users wherever they are in the UI, I created a much larger-than-normal back button for users to immediately find and hit to avoid annoyance. After this, I created the main Notifications "app", where the user can scroll through pages of their past notifications. Now, I could create a bunch of different pages depending on how many notifications there are, but you have to define each page in EEZ studio beforehand, and also it would make the code extremely unreadable and clunky to have a TON of pages. This is why I chose to give the user an illusion of switching pages, when in fact they are only switching the text in one page. This makes the generated EEZ code much more decipherable (in the very likely event I forgot to add some logic) and is just elegant in general. Plus, the pop-up notifications page is also used to view any of the notifications in the Notifications "app" by clicking on them.


*Ignore the blue lines, those aren't in the final UI*


After creating the UI for that, I moved on to making the Timekeeping "app", which houses a stopwatch and a configurable timer which continue in the background when the user leaves the "app". I decided to make these features look unique, yet still part of the UI, with the stopwatch page showing a large half-arc which shows seconds. The numbers displayed are large as well, and this page turned out to be one of my favourites for how simple yet elegant it subjectively looks. The timer page adjacent to the stopwatch shows LVGL UI elements that are new in this project: number rollers. Three number rollers allow for the user to pick seconds, minutes and hours, with a nice haptic tap happening when they change any of those values (iOS style!). Instead of having a separate label showing the actual timer's time, I also decided to use the number rollers *themselves* as labels, which saves a bunch of screen space and also makes the timer more user-friendly.




And lastly, I created the Weather "app" , which shows the user weather data which will hopefully be relayed to the watch from an iPhone with access to Apple's Weather API. This "app" consists of two pages yet again, with one showing the weather today, and the other showing the weather for the next 10 days. This first page shows the current temperature from the iPhone in huge letters, and also the temperature measured from the BMP585 sensor on the watch. Paired with that, the max and min temperatures are also shown, as well as the current weather conditions in the form of an icon. The right side of the page has a roller which shows the expected conditions and temperature for all of the hours of the day. The weather forecast page shows another roller which shows the weather for the next 10 days, and below that is a zoomable graph showing the temperature over those 10 days.


*Yeah the icons look cooked, that's just because all of them are placed on top of each other. In the actual UI, only one of them is shown at a time*

*Over here, the Day roller actually has a really long bit of logic to actually display the day of the week, it looks normal once its running*

This user interface is almost completely done now, with the only elements left to implement being the settings page where the user should have plenty of choices to customise the UI to their taste. I also still have to implement blood oxygen sensing algorithms in the main firmware, and also need to add BLE support to the firmware. But for now, I'll focus on the hardware to make this watch come to FRUITION!  

# 2/2/2026 - Fixed PCB Errors and added Fuel Gauge chip  

_Time spent: 2.5h_  

As I recently got my grant from Blueprint (Finally!!!), I can now start work on actually ordering the hardware that will make the ES_01 come to life. But first, I had to check all of my PCB documents to make ABSOLUTELY sure that my PCB was wired and arranged correctly, and I'm glad that I did do that.



Looking at my schematic, I found that the circuit for the main E-ink display was wired wrong enough that the PCB would not work at all if it was manufactured with that defect. After correcting the errors in the E-ink display circuit so that it matched the application circuit in the datasheet, I also found out that the connections to the touch panel for the E-ink display were wired in the wrong order. As the cables from the E-ink display have to bend around to reach the connectors on the PCB, the physical contacts are reversed, which I hadn't accounted for when wiring the touch panel's connector. Thankfully, that was also a quick fix. These schematic modifications did not result in major changes in the PCB layout either, so it was all done quite quickly.



I also made another modification to the schematic, which involved adding new components entirely. Specifically, I wanted added a MAX17048 fuel gauge chip which can measure the voltage and also calculate the amount of energy flowing through the batteries in the watch to provide an accurate estimate of the battery percentage. This is very similar to chips used in phones and laptops, and crucially allows for the watch to put itself in deep sleep when the battery gets to a low enough percentage so as to not damage the cells. I chose this specific chip mostly because it's extremely small and widely supported by the ESP32 community, so I won't have to write any sketchy drivers for it.



Because the chip is so small, it was able to fit easily in the less dense parts of the flex PCB which are underneath the OLED panels. Plus, the fuel gauge communicated via I2C, so those lines were easily connected to the same lines used to drive the OLEDs.



Now all that is left is to actually order the parts!  

# 2/8/2026 - Final FINAL finishing touches to 3D model and new "apps"!  

_Time spent: 3.5h_  

It’s time to make the FINAL FINAL finishing touches to all aspects of the ES_01’s hardware, and what was left to refine was the actual 3D model. This whole time, the ES_01 had no actual logos or identifiers on its 3D model, which I saw as a MASSIVE oversight that I promptly fixed. I installed the same Doto font from Google Fonts that was used in the main title screen of the UI, and cut away a nicely-proportioned “ES_01” in the top of one of the battery segments. Since that part of the top battery segment was only around 0.2mm thick, the indents of the text became holes which will show the real colour of the battery underneath. I think that’s actually pretty cool.

Screenshot 2026-02-08 at 8.09.31 am

Next to the ES_01 branding, on the second battery module, I put an embossed piece of text saying “Made in Australia” and rotated it by 180 degrees (hehe!). On the other side of the watch, the Triangulate logo and name were also embossed on the haptic driver segment of the watch. These texts only rise 0.1mm above the surface, so they are pretty subtle and not overly “in your face”, which would ruin the clean aesthetic. I also made a minor change to the display segments by rounding in the “cliffs” between the 3D-printed top cases and display screens for easier touch-ability, especially on the main panel.

Screenshot 2026-02-08 at 8.10.44 am

One more BIG change I made to the ES_01 is in its side TPU pieces, which now introduce a 60° downwards angle between the main E-ink segments and the OLED segments. I decided to do this because when worn, the angle between the E-ink and OLED segments are going to be quite large, (as you can see in the renders with a hand), and having a TPU piece that bends THAT much will pretty much guarantee failure in the future, That's why I rebuilt those pieces from scratch to account for that angle, and now the TPU pieces will not bend nearly as much when worn.

Screenshot 2026-02-08 at 8.11.27 am

I also made some changes to the UI after gaining a bunch of new ideas for functions the watch should do. As I recently started Year 12 of school, I found myself wanting to have my timetable on my watch so that I don’t have to access my phone (only for it to be confiscated). Then I noticed my smartwatch, and most smartwatches, for the matter, didn’t have a feature for this. This is why I created another page in the main menu in the UI, and added 4 MORE “apps” (just concepts, not developed yet) that I think would be really useful for a lot of people, whether they are in school or not. First is the Timetable “app”, which stores all your timetable data and displays it to you, as well as keeping track of time and telling you which class or meeting you have next through notifications. As it’s pretty complicated to set up each entry in ANY timetable, I have relegated the actual timetable editing to the iPhone app. So users can edit timetables and calendars in the app, and just observe them through the watch.

Screenshot 2026-02-08 at 8.12.25 am

Which brings me onto the next “app” I added, a Calendar. This basically functions the exact same as the Timetable “app”, but instead does not repeat and is meant for one-off events. Next, I added a “Find ur Phone” button in the main menu, which, through the app, causes the user’s phone to vibrate and make noise so that they can find it. It would have also been nice to include an Ultra Wideband module which works with Apple’s Find My so that users can locate their phone with more precision, but I guess that’s something to implement in version 2! 

Screenshot 2026-02-08 at 8.12.42 am

Lastly, I added a Shot Button to the main menu, which, when tapped, triggers the user’s phone to take a photo. This feature is similar to one found in Apple Watches, and it allows the user to set their phone down and remotely trigger a photo while they’re standing in front of it. 

Now that the 3D model of the ES_01 is completely refined as well, I think it’s now FINALLY FINALLY time to order the parts!  

# 2/15/2026 - PARTS ORDERED!!!!  

_Time spent: 2.5h_  

I FINALLY ORDERED THE PARTS!!! After like so much time meticulously looking over and refining the scariest parts of the ES_01 (namely, the PCB), I have activated my Hack Club grant and have ordered the majority of the parts from LCSC and AliExpress, and also the PCB and Metal 3D-printed E-ink bottom plate from JLC.

Firstly, just to make sure I wasn't going to order the wrong parts, I reloaded the Electronics_BOM.csv file from my repository onto LCSC, and good thing I did cause I found a couple of problems. There were 4 models of resistor in my BOM which were completely out of stock and backordered on LCSC, and they would've taken *60 DAYS* to get back in stock (Yikes), so I quickly changed those resistors out for ones that were in stock.

Also, looking at my AliExpress cart, I found that the 401225 batteries I was going to usei in the ES_01 were not available anymore, but that wasn't a really big deal as there were like 20 other listings selling the same thing. However, looking at these listings, I found a battery which was almost the same size as the 401225 batteries I was going to use, but have 30mAh more capacity each. 



These are 401230 batteries, with them being 30mm long instead of 25. After a quick check with my 3D model, I found that these batteries can easily fit into the battery compartments in the ES_01, so I set out to work modifying those segments from the inside to fit the extra 5mm. That turned out successfully, and now the ES_01 has a significant boost in battery capacity, going up from an already hefty (for a smartwatch) 300mAh to just under **390mAh!** For comparison, this is roughly 50% MORE capacity than an Apple Watch (non-Ultra), which uses a much more power-hungry S-series chip and OLED panel, so the ES_01 should now last ridiculously long, even with its ESP32-S3 chip.

As of now, I have still yet to order some random very specific connector (from Alibaba) for my OLED displays to work, but those only cost like $7. I've also gotten 3D-printing arranged as well (Shoutout to 0x62)!!!

# 3/4/2026 - Reworked Trios UI, added Timetable app, and parts arrived!  

_Time spent: 3.5h_  

Sorry for being silent for a while, cause these parts are do take their time! Anyways, this journal entry is an update on what has been happening in the past two-ish weeks, and BOY do I have some updates to give.

I continued with the firmware development process of the ES_01, with a bunch of newly-added functions which I still had to actually develop. But before I did that, I started reworking the internals of the UI which Trios (Yes, I came up with a name for the firmware) runs on. 

Looking back at my EEZ Studio project, especially the timekeeping app could have a bunch of its logic offloaded to EEZ Flow instead of implementing it in Trios core (the main ESP-IDF project). Both the stopwatch and timer features can be implemented in the EEZ Flow engine, so that’s exactly what I did, and it works!!

Screenshot 2026-03-04 at 7.18.36 pm
Screenshot 2026-03-04 at 7.19.07 pm

*Ignore the blue lines, those are just flow logic arrows which won't be visible while running*

After that, I started with redoing the notifications section in Trios. Before, Trios could only store a maximum of 32 notifications at a time, and ALL of them were loaded into the ES_01’s RAM on startup. Since strings take up a LOT of data, this would both eat RAM and restrict the number of notifications users can see. This was unacceptable, so I reworked it so that only 4 notifications are loaded into RAM at a time, and Trios will get any other notifications from the ES_01’s internal flash that can store WAY more data. Of course, implementing actual flash file storing logic is beyond the scope of the UI, so I just let the UI call some functions which I’ll define in Trios core later.

Screenshot 2026-03-04 at 7.19.38 pm

The third thing I added in Trios’s UI was the timetable app. This app shows upcoming events for the whole week, and it will have its timetable events loaded onto it by the ES_01’s iPhone app. To implement this, I created two rollers, one that scrolls through the events happening today, and another which scrolls through the days of the week, updating the first roller each time. Since a user can have an arbitrary number of timetable events, it would be terrible to have them all loaded into RAM for every day of the week, so only a single day’s events are actually in RAM. Trios will fetch the timetable events for each day from the ES_01’s internal flash when they are requested by the user. Lastly, I created a timetable screen which flashes 5 minutes (or a configurable amount of time) before a timetable event to notify the user.

Screenshot 2026-03-04 at 7.20.04 pm
Screenshot 2026-03-04 at 7.20.17 pm
Screenshot 2026-03-04 at 7.20.35 pm

Apart from the progress I made on Trios, the first of the ordered components for the ES_01 finally arrived today, which includes the huge box of tiny SMD components ordered from LCSC electronics! The flex PCB should arrive within the next week, after which I can finally start assembling the electronics for the watch! Stay tuned for further updates!

  

# 3/5/2026 - PCB has arrived!!!  

_Time spent: 0.5h_  

All of the parts from JLC have arrived! This includes the all-important main flex PCB, the solder stencil for it, and the one metal 3D-printed part meant for cooling the really hot ESP32-S3 chip!



The PCBs turned out basically flawless, with them having just the right rigidity in the parts with stiffeners, and just the right amount of flexibility in the parts that bend. It’s only now that I realise how crazy small the components in the ES_01 really are, but I’m reassured because now I have a proper stencil.



The stencil is really huge compared to the PCB it’s for, and I guess I’ll frame it and hang it up in my room after I don’t need it anymore! There is a small problem with the metal 3D printed part though.



It is quite warped, and I was notified of this issue by JLCPCB, but I insisted that they manufacture the part. This isn’t that big of a deal however, as since the part is made from steel, I can heat it up on a hotplate and bend it back into shape if I’m careful. Otherwise, this haul from JLCPCB was successful, and I look forward to assembling the PCB of the ES_01!!!
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

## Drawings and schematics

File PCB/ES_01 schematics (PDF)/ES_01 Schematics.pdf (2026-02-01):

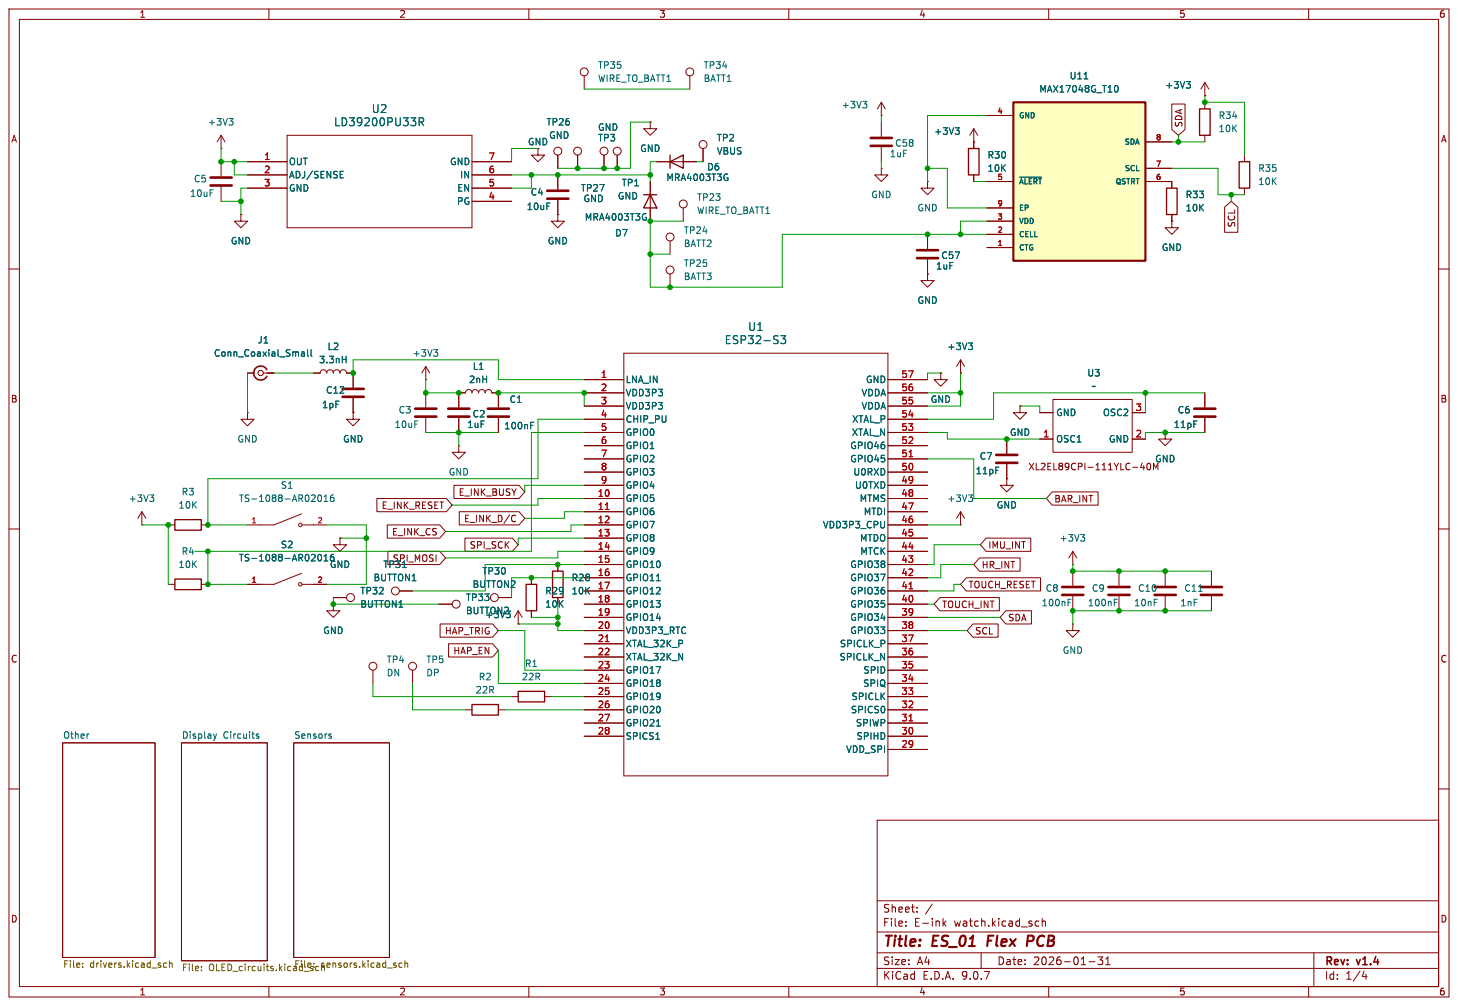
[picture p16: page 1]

Id: 1/4 Title: ES_01 Flex PCB

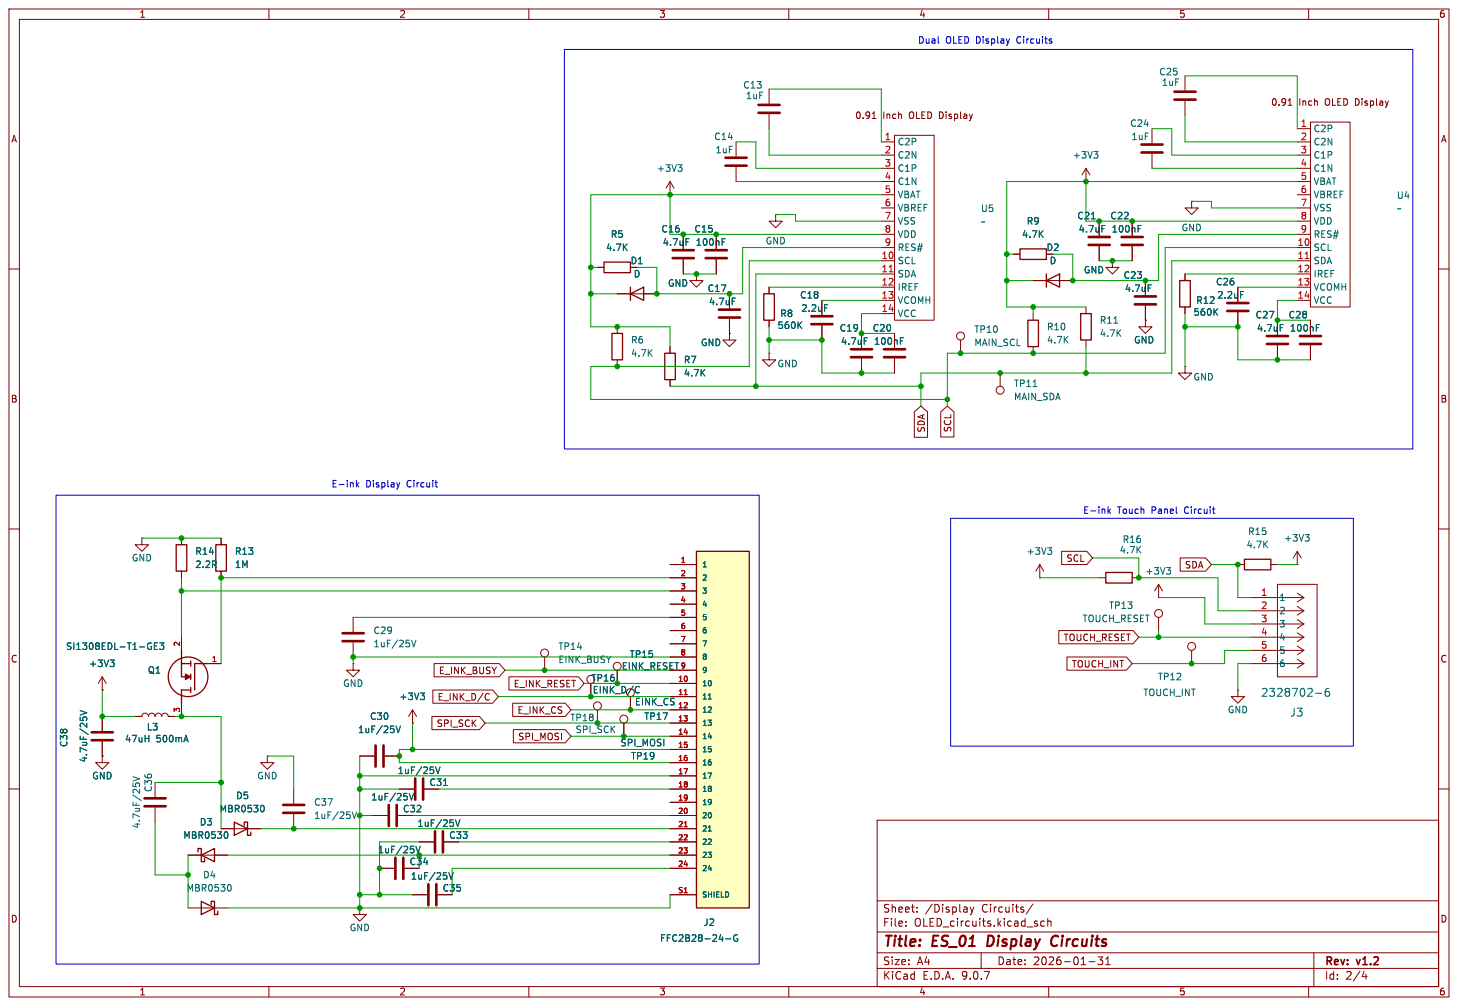
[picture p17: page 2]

Id: 2/4 Title: ES_01 Display Circuits

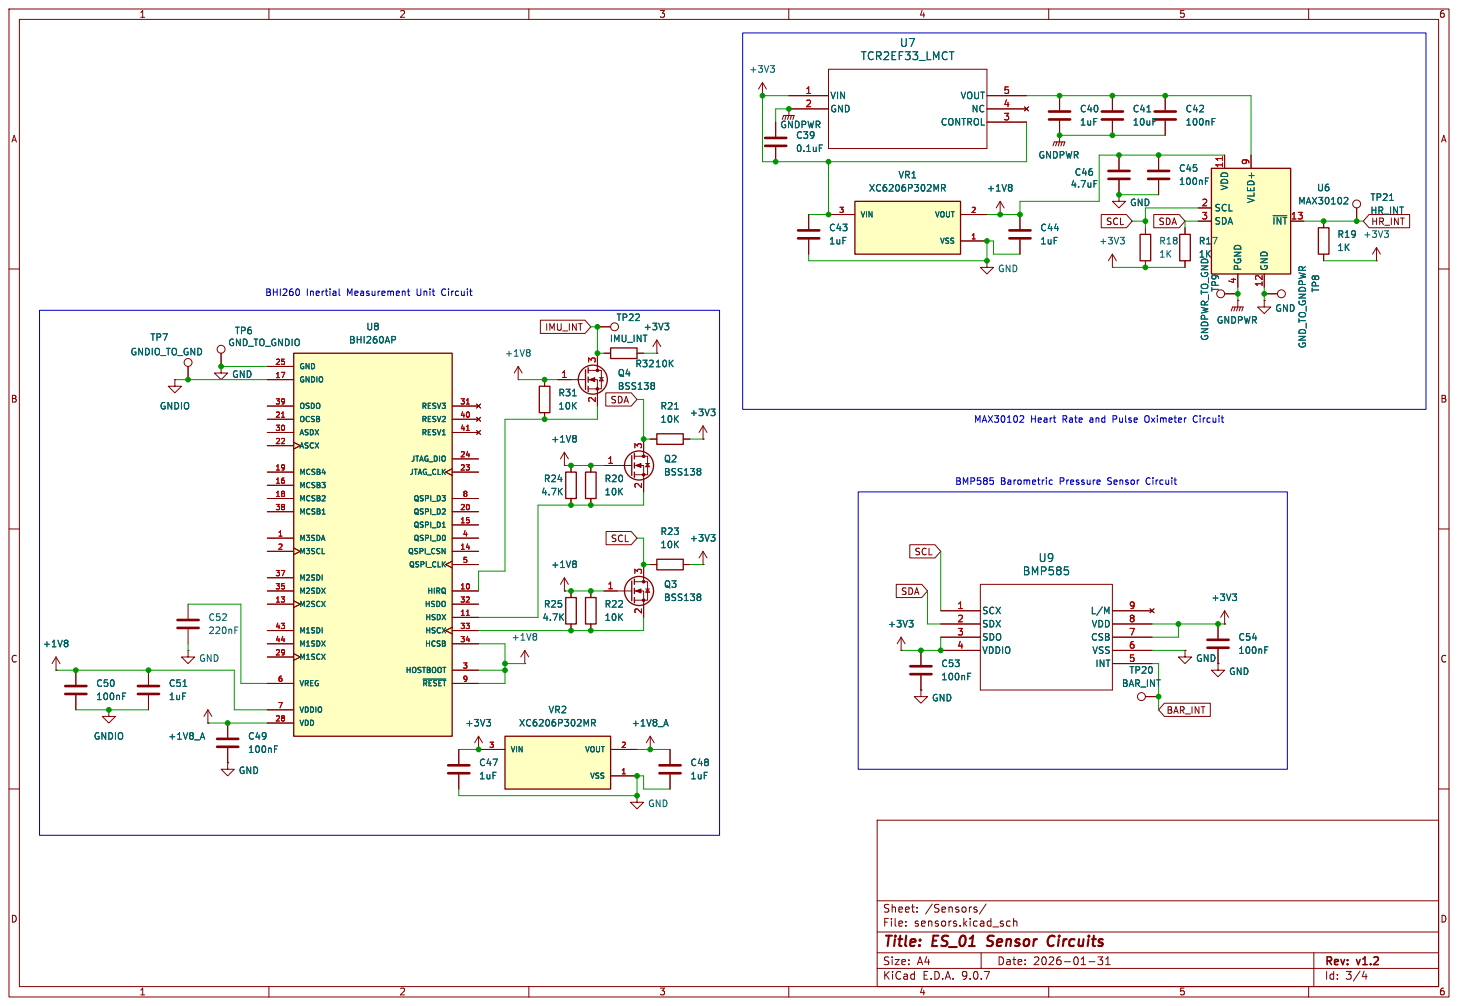
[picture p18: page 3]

Id: 3/4 Title: ES_01 Sensor Circuits

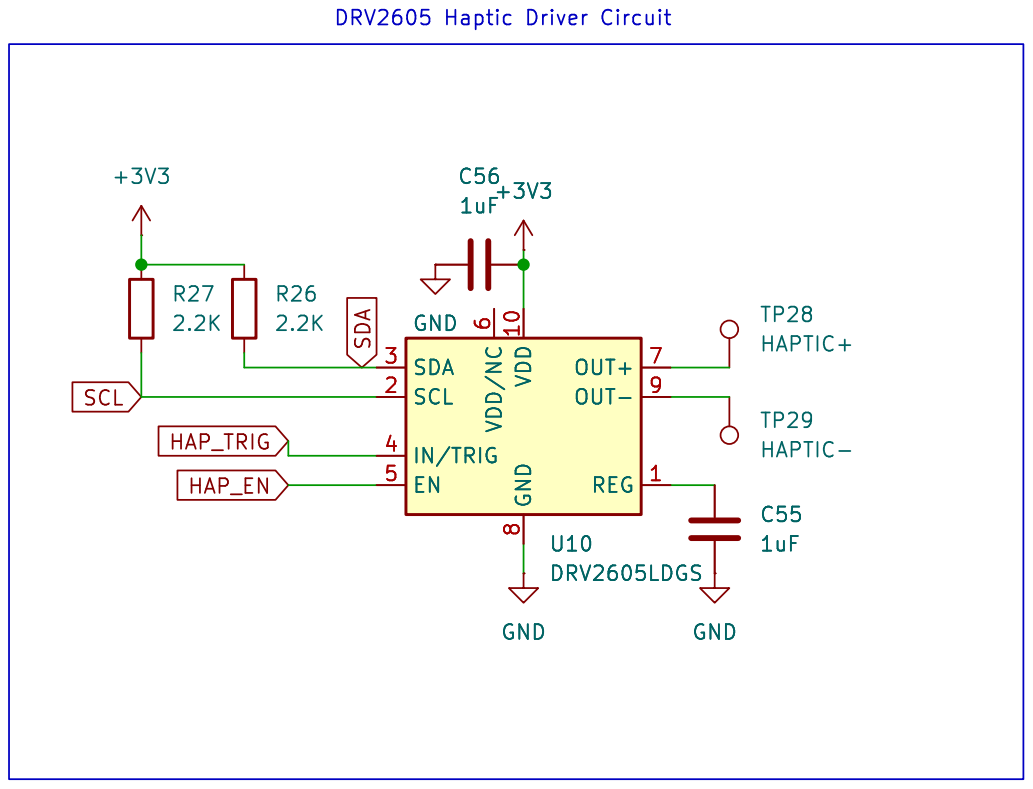
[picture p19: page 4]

DRV2605 Haptic Driver Circuit GND

8 OUT+ 7 OUT- 9 REG 1 U10 DRV2605LDGS GND

8 OUT+ 7 OUT- 9 REG 1 GND

File: drivers.kicad_sch Sheet: /Other/
Id: 4/4 Title: ES_01 Other Circuits

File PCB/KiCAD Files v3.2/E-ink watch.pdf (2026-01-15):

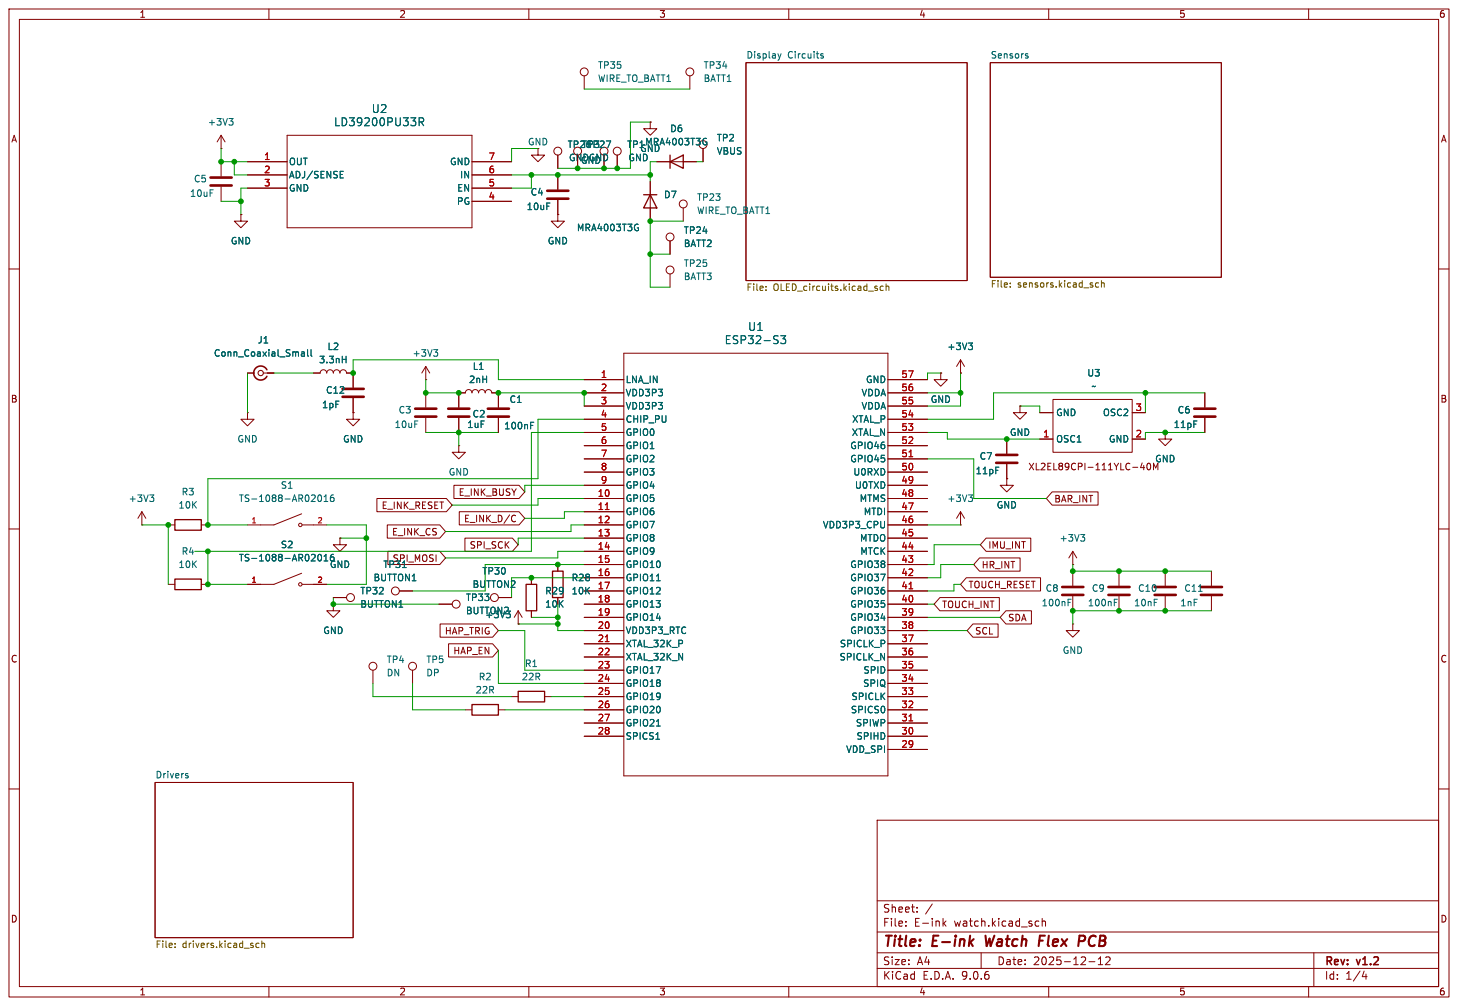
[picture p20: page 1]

Sensors File: sensors.kicad_sch Drivers File: drivers.kicad_sch

Id: 1/4 Title: E-ink Watch Flex PCB

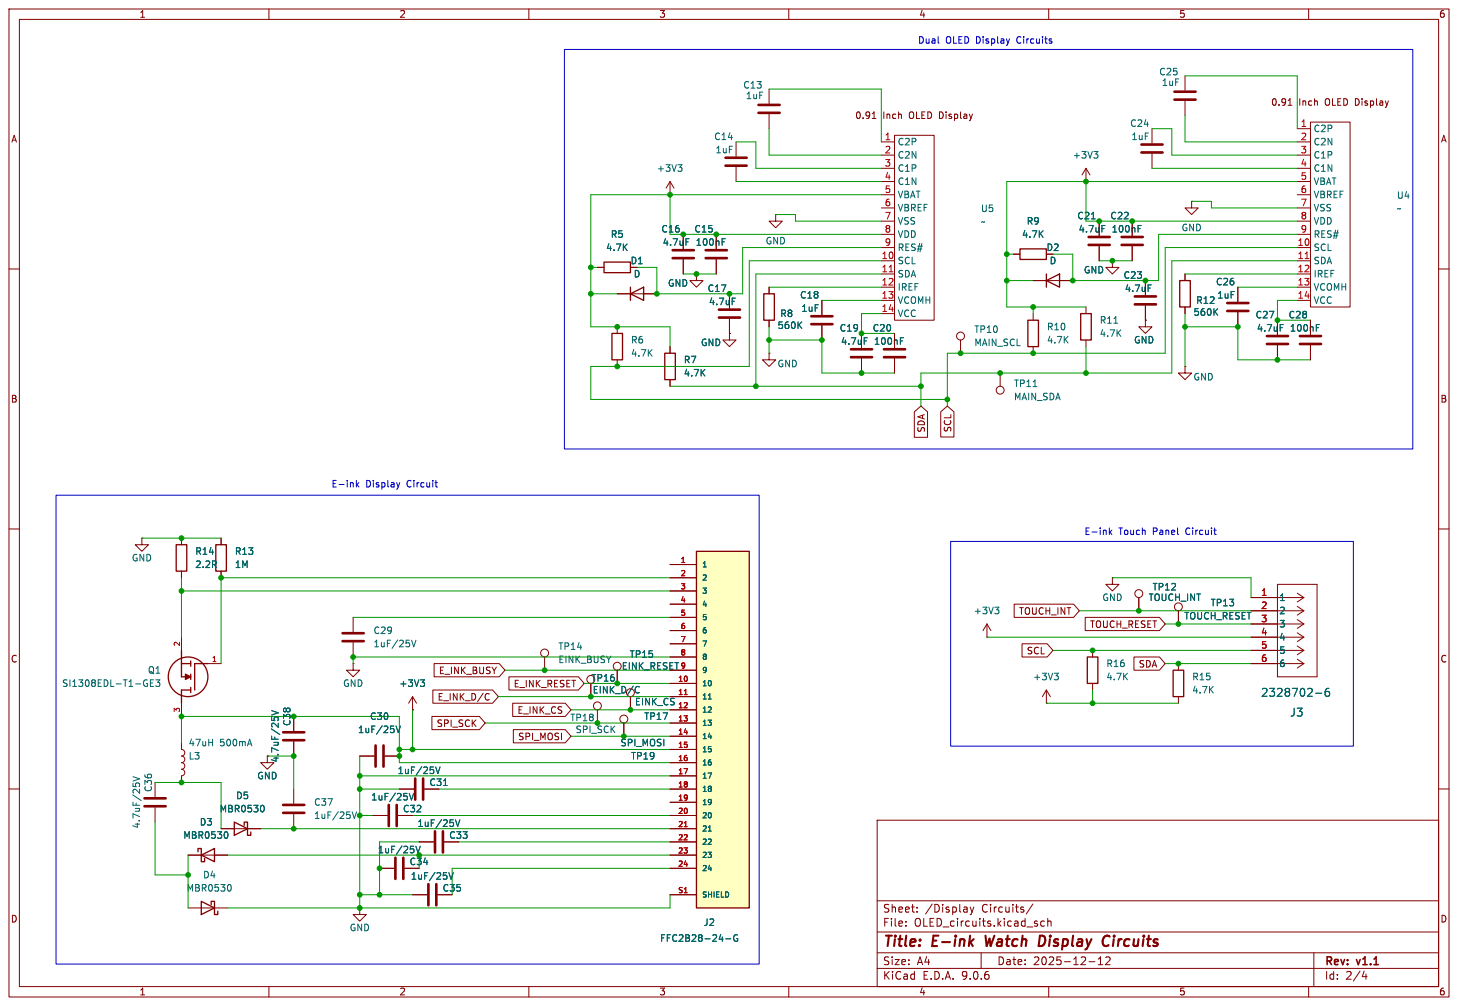
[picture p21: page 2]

0.91 Inch OLED Display C2P 1 C2N 2 C1P 3 C1N 4 VBAT 5 VBREF 6 VSS 7 VDD 8 RES# 9 SCL 10 SDA 11

Id: 2/4 Title: E-ink Watch Display Circuits

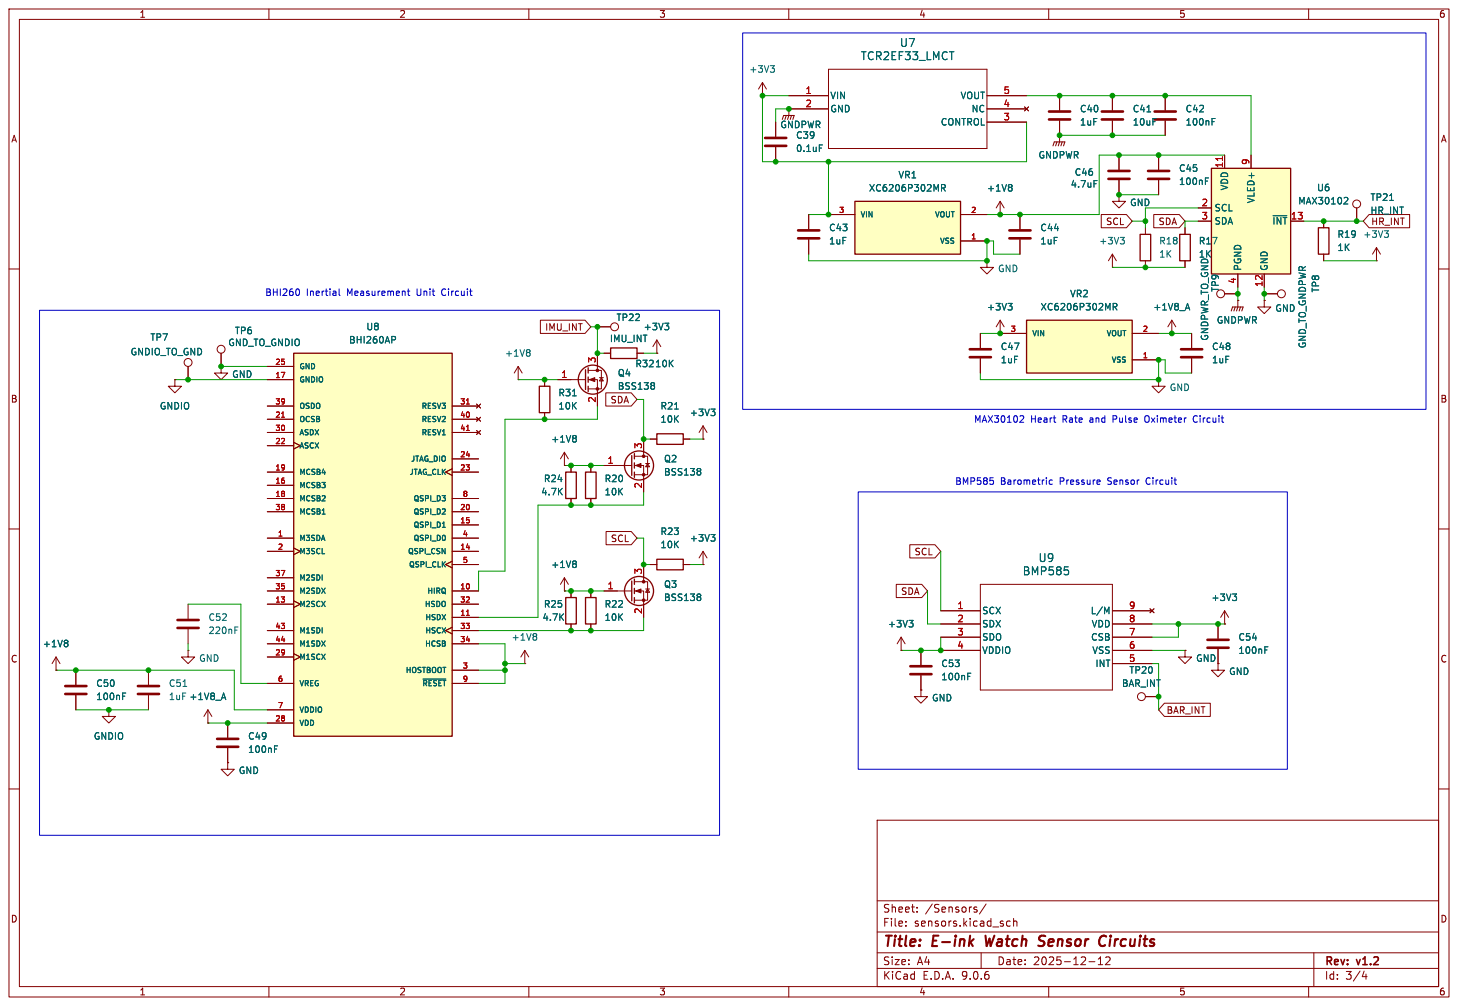
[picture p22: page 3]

File: sensors.kicad_sch Sheet: /Sensors/
Id: 3/4 Title: E-ink Watch Sensor Circuits

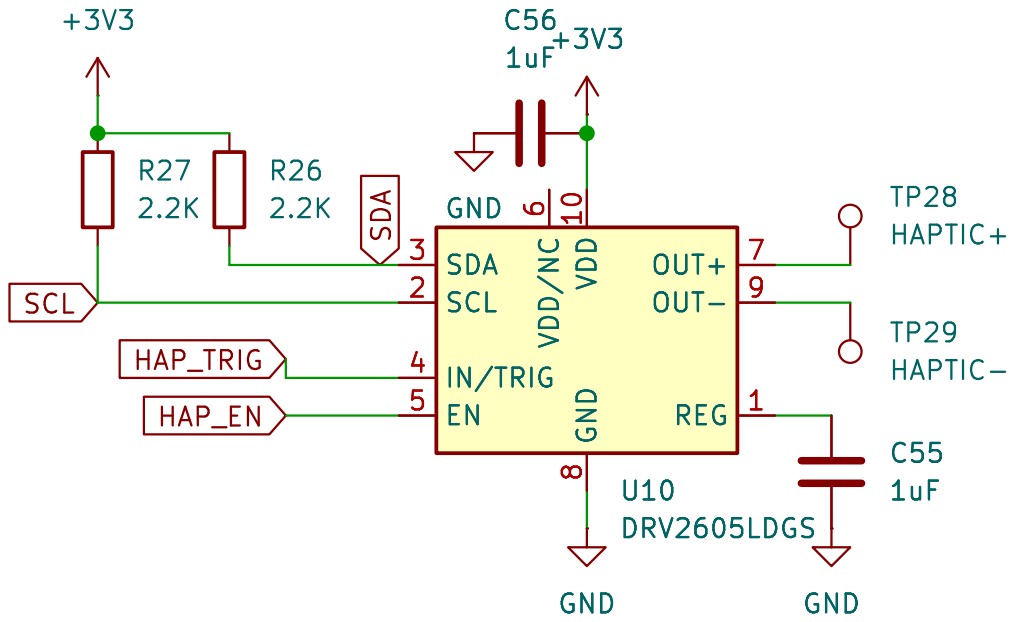
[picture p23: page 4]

8 OUT+ 7 OUT- 9 REG 1 U10 DRV2605LDGS GND

8 OUT+ 7 OUT- 9 REG 1 GND

File: drivers.kicad_sch Sheet: /Drivers/
Id: 4/4 Title: E-ink Watch Driver Circuits

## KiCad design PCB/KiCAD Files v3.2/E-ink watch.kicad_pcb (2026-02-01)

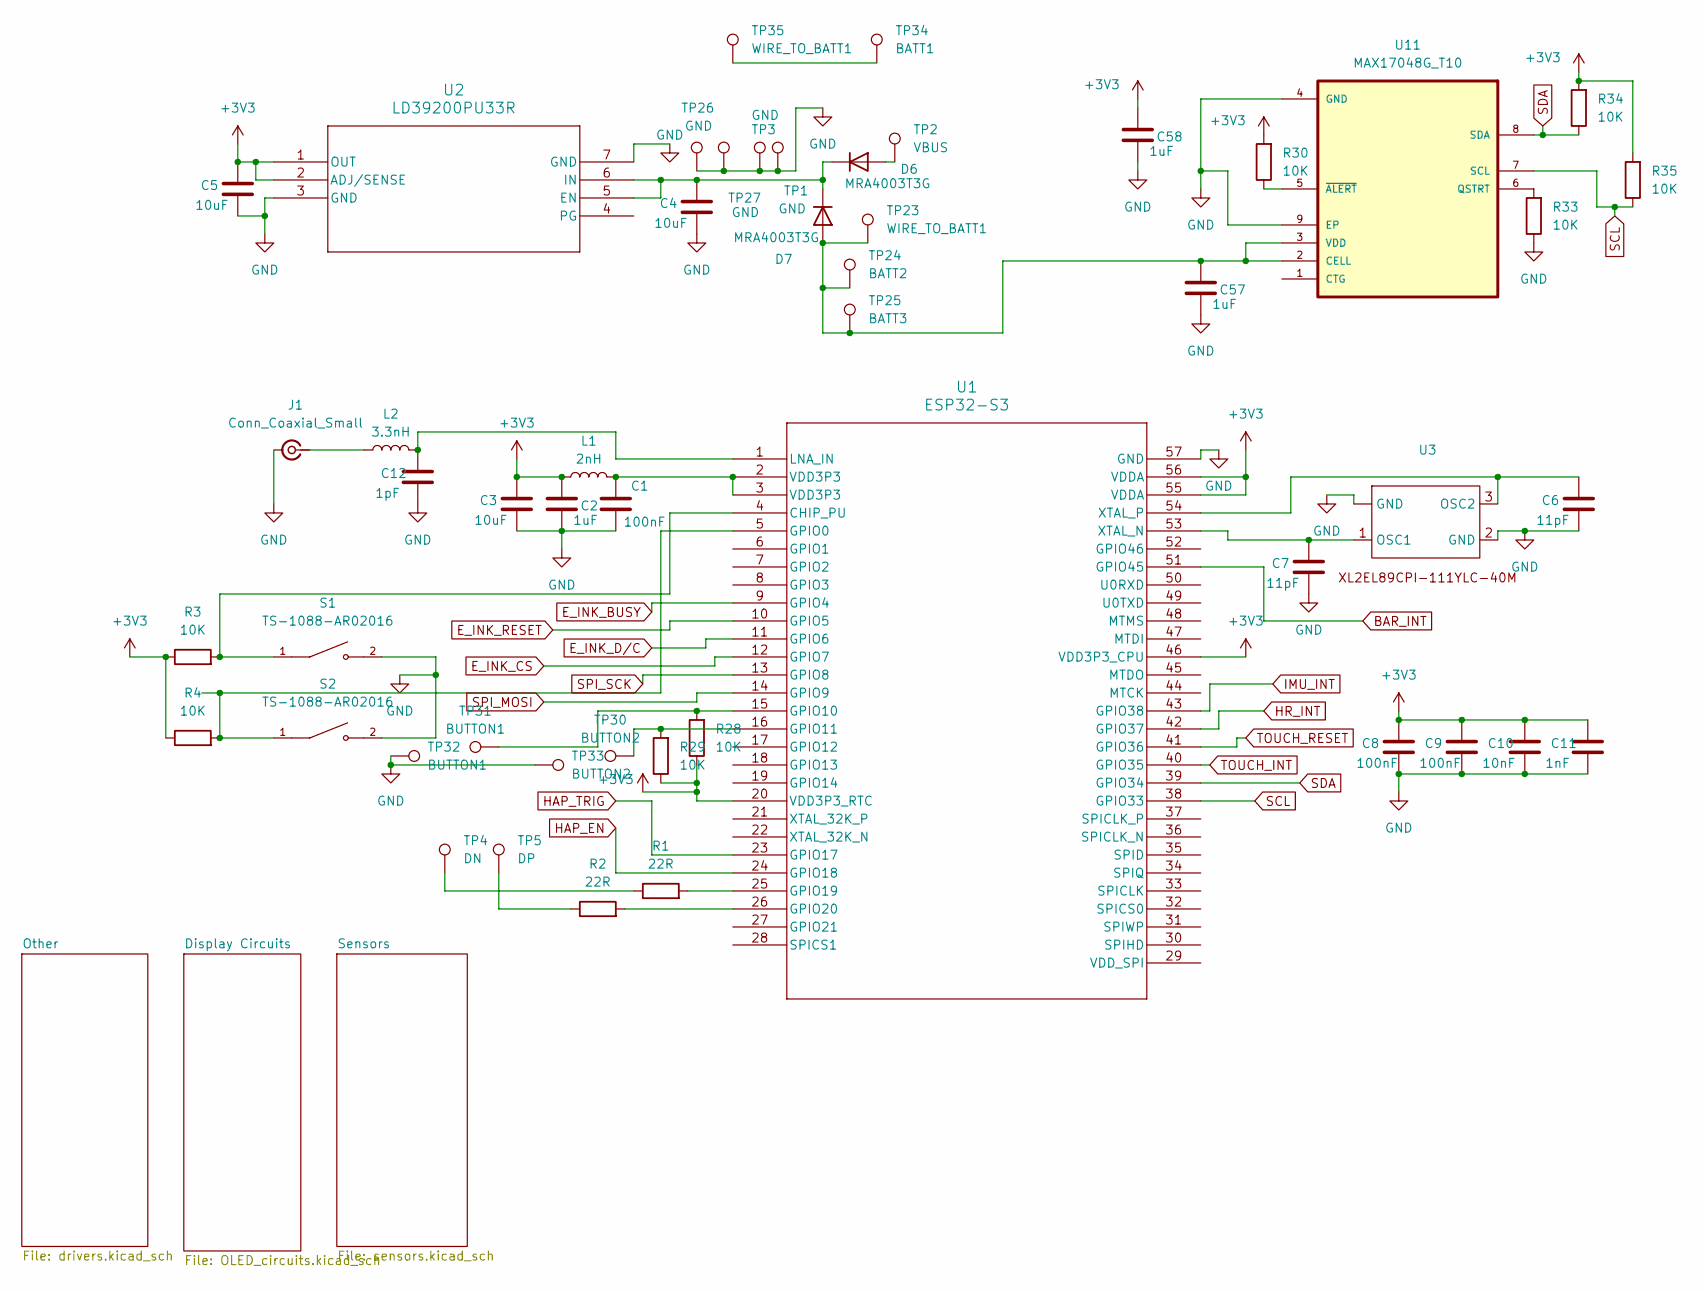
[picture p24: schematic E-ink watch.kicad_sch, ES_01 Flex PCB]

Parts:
C1, C8, C9: 100nF; C_0402_1005Metric_Pad0.74x0.62mm_HandSolder
C2, C57, C58: 1uF; C_0402_1005Metric_Pad0.74x0.62mm_HandSolder
C3, C4, C5: 10uF; C_0402_1005Metric_Pad0.74x0.62mm_HandSolder
C6, C7: 11pF; C_0402_1005Metric_Pad0.74x0.62mm_HandSolder
C10: 10nF; C_0402_1005Metric_Pad0.74x0.62mm_HandSolder
C11: 1nF; C_0402_1005Metric_Pad0.74x0.62mm_HandSolder
C12: 1pF; C_0402_1005Metric_Pad0.74x0.62mm_HandSolder
D6, D7: MRA4003T3G; D_SMA
J1: Conn_Coaxial_Small; U.FL_Hirose_U.FL-R-SMT-1_Vertical
L1: 2nH; L_0402_1005Metric_Pad0.77x0.64mm_HandSolder
L2: 3.3nH; L_0402_1005Metric_Pad0.77x0.64mm_HandSolder
R1, R2: 22R; R_0402_1005Metric_Pad0.72x0.64mm_HandSolder
R3, R4, R28, R29, R30, R33, R34, R35: 10K; R_0402_1005Metric_Pad0.72x0.64mm_HandSolder
S1, S2: TS-1088-AR02016; SW_TS-1088-AR02016; PARTREV N/A
TP1, TP3, TP26, TP27: GND; TestPoint_Pad_1.5x1.5mm
TP2: VBUS; TestPoint_Pad_1.5x1.5mm
TP4: DN; TestPoint_Pad_1.5x1.5mm
TP5: DP; TestPoint_Pad_1.5x1.5mm
TP23, TP35: WIRE_TO_BATT1; TestPoint_Pad_1.5x1.5mm
TP24: BATT2; TestPoint_Pad_1.5x1.5mm
TP25: BATT3; TestPoint_Pad_1.5x1.5mm
TP30, TP33: BUTTON2; TestPoint_Pad_1.5x1.5mm
TP31, TP32: BUTTON1; TestPoint_Pad_1.5x1.5mm
TP34: BATT1; TestPoint_Pad_1.5x1.5mm
U1: ESP32-S3; QFN56_7X7_EXP
U2: LD39200PU33R; SON_DFN6_3X3_STM
U3: Untitled
U11: MAX17048G_T10; SON50P200X200X80-9N

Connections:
+3V3: C2.1, C3.1, C5.1, C8.1, C9.1, C10.1, C11.1, C58.1, L1.1, R3.1, R4.1, R28.1, R29.1, R30.2, R34.2, R35.2, U1.20 (VDD3P3_RTC), U1.46 (VDD3P3_CPU), U1.55 (VDDA), U1.56 (VDDA), U2.1 (OUT), U2.2 (ADJ/SENSE); also elsewhere on the board
BAR_INT: U1.51 (GPIO45); also elsewhere on the board
E_INK_BUSY: U1.9 (GPIO4); also elsewhere on the board
E_INK_CS: U1.12 (GPIO7); also elsewhere on the board
E_INK_D/C: U1.11 (GPIO6); also elsewhere on the board
E_INK_RESET: U1.10 (GPIO5); also elsewhere on the board
GND: C1.2, C2.2, C3.2, C4.2, C5.2, C6.2, C7.2, C8.2, C9.2, C10.2, C11.2, C12.2, C57.2, C58.2, J1.2 (Ext), R33.1, S1.2, S2.2, TP1.1, TP3.1, TP26.1, TP27.1, TP32.1, TP33.1, U1.57 (GND), U2.3 (GND), U2.7 (GND), U3. (GND), U3.2 (GND), U11.4 (GND), U11.9 (EP); also elsewhere on the board
HAP_EN: U1.24 (GPIO18); also elsewhere on the board
HAP_TRIG: U1.23 (GPIO17); also elsewhere on the board
HR_INT: U1.42 (GPIO37); also elsewhere on the board
IMU_INT: U1.43 (GPIO38); also elsewhere on the board
unnamed: C1.1, L1.2, U1.2 (VDD3P3), U1.3 (VDD3P3)
unnamed: D6.2 (A), TP2.1
unnamed: C4.1, D6.1 (K), D7.1 (K), U2.5 (EN), U2.6 (IN)
unnamed: C57.1, D7.2 (A), TP23.1, TP24.1, TP25.1, U11.2 (CELL), U11.3 (VDD)
unnamed: J1.1 (In), L2.1
unnamed: R1.1, TP4.1
unnamed: R2.1, TP5.1
unnamed: TP34.1, TP35.1
unnamed: R3.2, S1.1, U1.4 (CHIP_PU)
unnamed: R4.2, S2.1, U1.5 (GPIO0)
unnamed: R28.2, TP31.1, U1.15 (GPIO10)
unnamed: R29.2, TP30.1, U1.16 (GPIO11)
unnamed: R1.2, U1.25 (GPIO19)
unnamed: R2.2, U1.26 (GPIO20)
unnamed: C12.1, L2.2, U1.1 (LNA_IN)
unnamed: C7.1, U1.53 (XTAL_N), U3.1 (OSC1)
unnamed: C6.1, U1.54 (XTAL_P), U3.3 (OSC2)
unnamed: R33.2, U11.6 (QSTRT)
unnamed: R30.1, U11.5 (~ALERT)
SCL: R35.1, U1.38 (GPIO33), U11.7 (SCL); also elsewhere on the board
SDA: R34.1, U1.39 (GPIO34), U11.8 (SDA); also elsewhere on the board
SPI_MOSI: U1.14 (GPIO9); also elsewhere on the board
SPI_SCK: U1.13 (GPIO8); also elsewhere on the board
TOUCH_INT: U1.40 (GPIO35); also elsewhere on the board
TOUCH_RESET: U1.41 (GPIO36); also elsewhere on the board

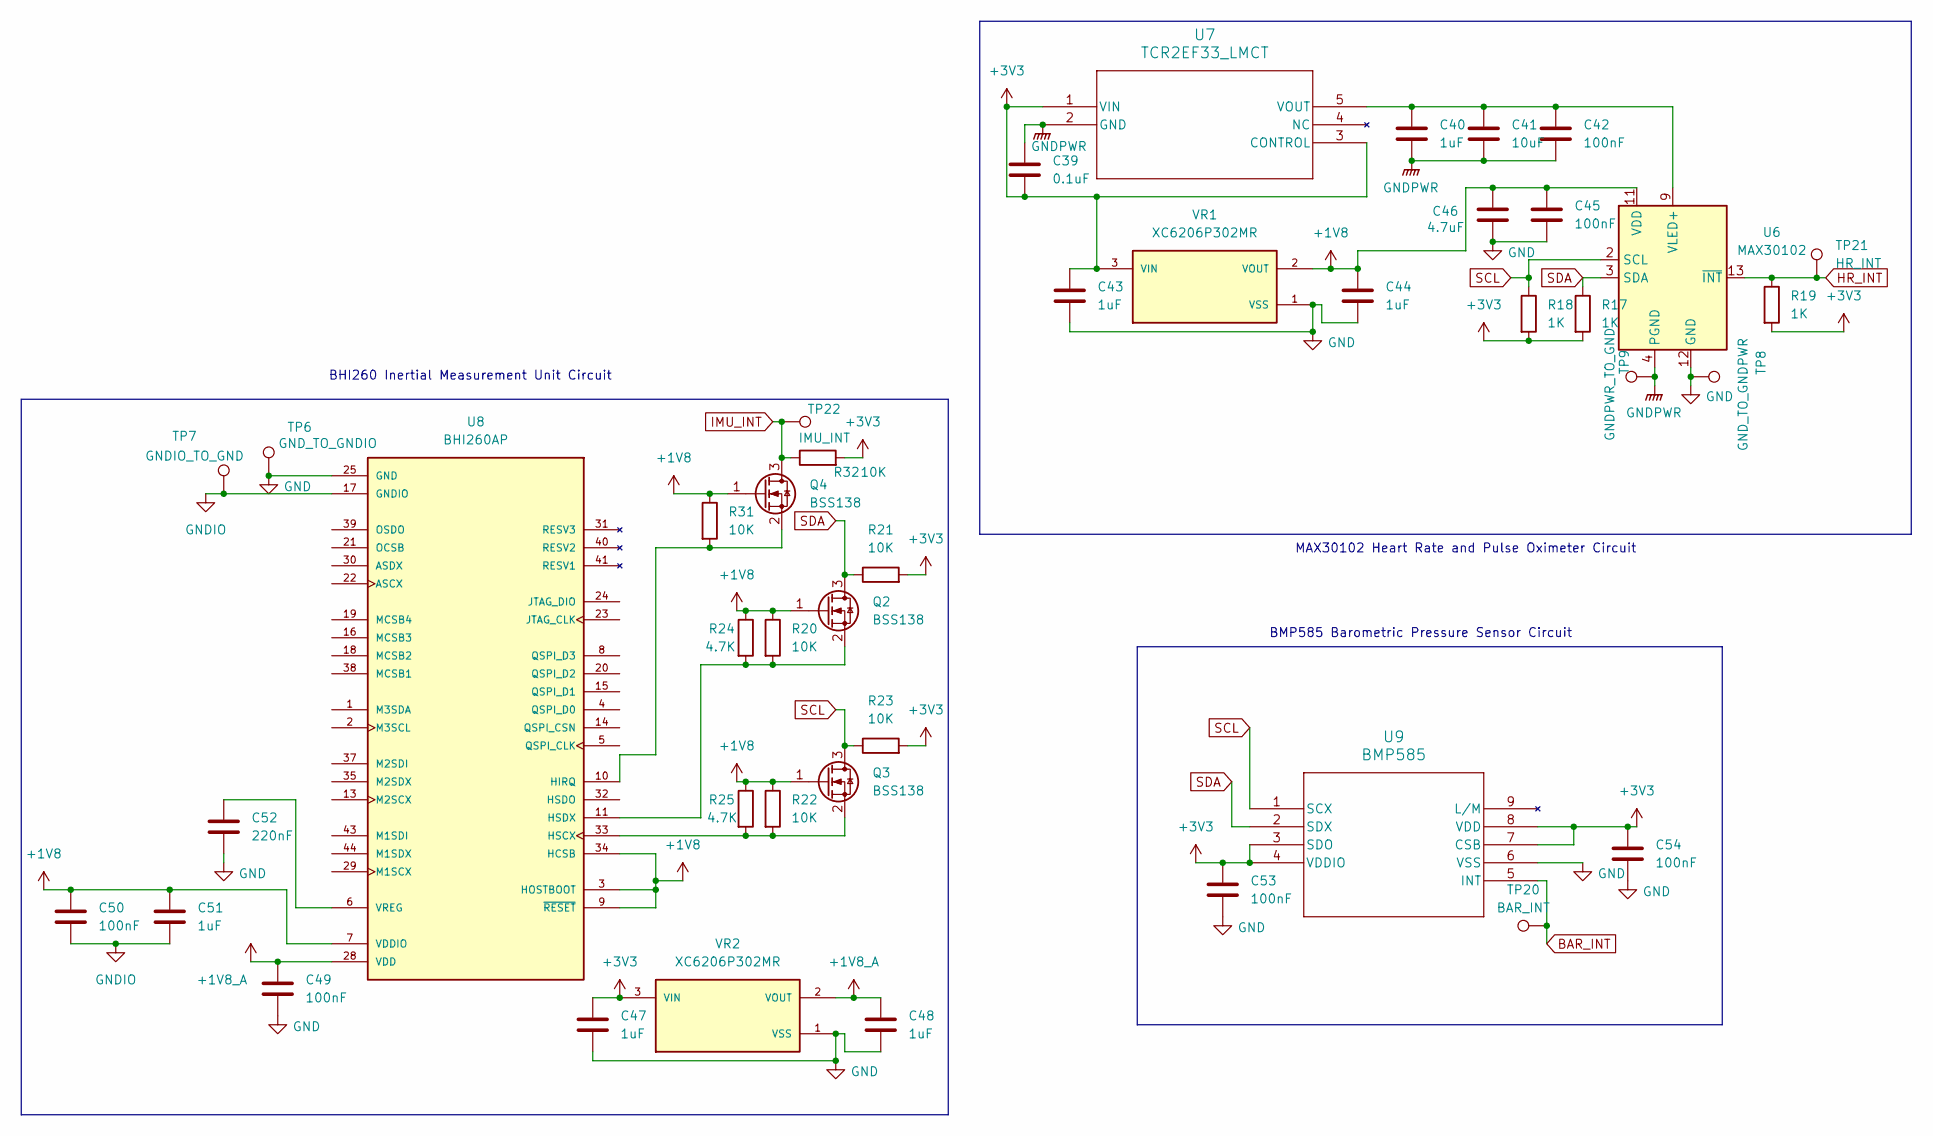
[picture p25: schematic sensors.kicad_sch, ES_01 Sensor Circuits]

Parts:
C39: 0.1uF; C_0402_1005Metric_Pad0.74x0.62mm_HandSolder
C40, C43, C44, C47, C48, C51: 1uF; C_0402_1005Metric_Pad0.74x0.62mm_HandSolder
C41: 10uF; C_0402_1005Metric_Pad0.74x0.62mm_HandSolder
C42, C45, C49, C50, C53, C54: 100nF; C_0402_1005Metric_Pad0.74x0.62mm_HandSolder
C46: 4.7uF; C_0402_1005Metric_Pad0.74x0.62mm_HandSolder
C52: 220nF; C_0402_1005Metric_Pad0.74x0.62mm_HandSolder
Q2, Q3, Q4: BSS138; SOT-23
R17, R18, R19: 1K; R_0402_1005Metric_Pad0.72x0.64mm_HandSolder
R20, R21, R22, R23, R31, R32: 10K; R_0402_1005Metric_Pad0.72x0.64mm_HandSolder
R24, R25: 4.7K; R_0402_1005Metric_Pad0.72x0.64mm_HandSolder
TP6: GND_TO_GNDIO; TestPoint_Pad_1.5x1.5mm
TP7: GNDIO_TO_GND; TestPoint_Pad_1.5x1.5mm
TP8: GND_TO_GNDPWR; TestPoint_Pad_1.5x1.5mm
TP9: GNDPWR_TO_GND; TestPoint_Pad_1.5x1.5mm
TP20: BAR_INT; TestPoint_Pad_D1.0mm
TP21: HR_INT; TestPoint_Pad_D1.0mm
TP22: IMU_INT; TestPoint_Pad_D1.0mm
U6: MAX30102; Maxim_OLGA-14_3.3x5.6mm_P0.8mm
U7: TCR2EF33_LMCT; SOT-25 SMV_TOS
U8: BHI260AP; XDCR_BHI260AP; PARTREV 1.1
U9: BMP585; LGA9_BMP585_BOS
VR1, VR2: XC6206P302MR; SOT95P280X130-3N; PARTREV N/A

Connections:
+1V8: C44.1, C45.1, C46.1, C50.1, C51.1, Q2.1 (G), Q3.1 (G), Q4.1 (G), R20.1, R22.1, R24.1, R25.1, R31.1, U6.11 (VDD), U8.3 (HOSTBOOT), U8.7 (VDDIO), U8.9 (~RESET), U8.12 (VDDIO), U8.34 (HCSB), U8.42 (VDDIO), VR1.2 (VOUT)
+1V8_A: C48.1, C49.1, U8.28 (VDD), VR2.2 (VOUT)
+3V3: C39.2, C43.1, C47.1, C53.1, C54.1, R17.2, R18.2, R19.2, R21.2, R23.2, R32.2, U7.1 (VIN), U7.3 (CONTROL), U9.3 (SDO), U9.4 (VDDIO), U9.7 (CSB), U9.8 (VDD), VR1.3 (VIN), VR2.3 (VIN); also elsewhere on the board
BAR_INT: TP20.1, U9.5 (INT); also elsewhere on the board
GND: C43.2, C44.2, C45.2, C46.2, C47.2, C48.2, C49.2, C52.2, C53.2, C54.2, TP6.1, TP8.1, U6.12 (GND), U8.25 (GND), U8.26 (GND), U8.27 (GND), U9.6 (VSS), VR1.1 (VSS), VR2.1 (VSS); also elsewhere on the board
GNDIO: C50.2, C51.2, TP7.1, U8.17 (GNDIO), U8.36 (GNDIO)
GNDPWR: C39.1, C40.2, C41.2, C42.2, TP9.1, U6.4 (PGND), U7.2 (GND)
HR_INT: R19.1, TP21.1, U6.13 (~INT); also elsewhere on the board
IMU_INT: Q4.3 (D), R32.1, TP22.1; also elsewhere on the board
unnamed: Q2.2 (S), R20.2, R24.2, U8.11 (HSDX)
unnamed: Q3.2 (S), R22.2, R25.2, U8.33 (HSCX)
unnamed: Q4.2 (S), R31.2, U8.10 (HIRQ)
unnamed: C40.1, C41.1, C42.1, U6.9 (VLED+), U6.10 (VLED+), U7.5 (VOUT)
unnamed: C52.1, U8.6 (VREG)
SCL: Q3.3 (D), R18.1, R23.1, U6.2 (SCL), U9.1 (SCX); also elsewhere on the board
SDA: Q2.3 (D), R17.1, R21.1, U6.3 (SDA), U9.2 (SDX); also elsewhere on the board

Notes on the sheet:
MAX30102 Heart Rate and Pulse Oximeter Circuit
BHI260 Inertial Measurement Unit Circuit
BMP585 Barometric Pressure Sensor Circuit

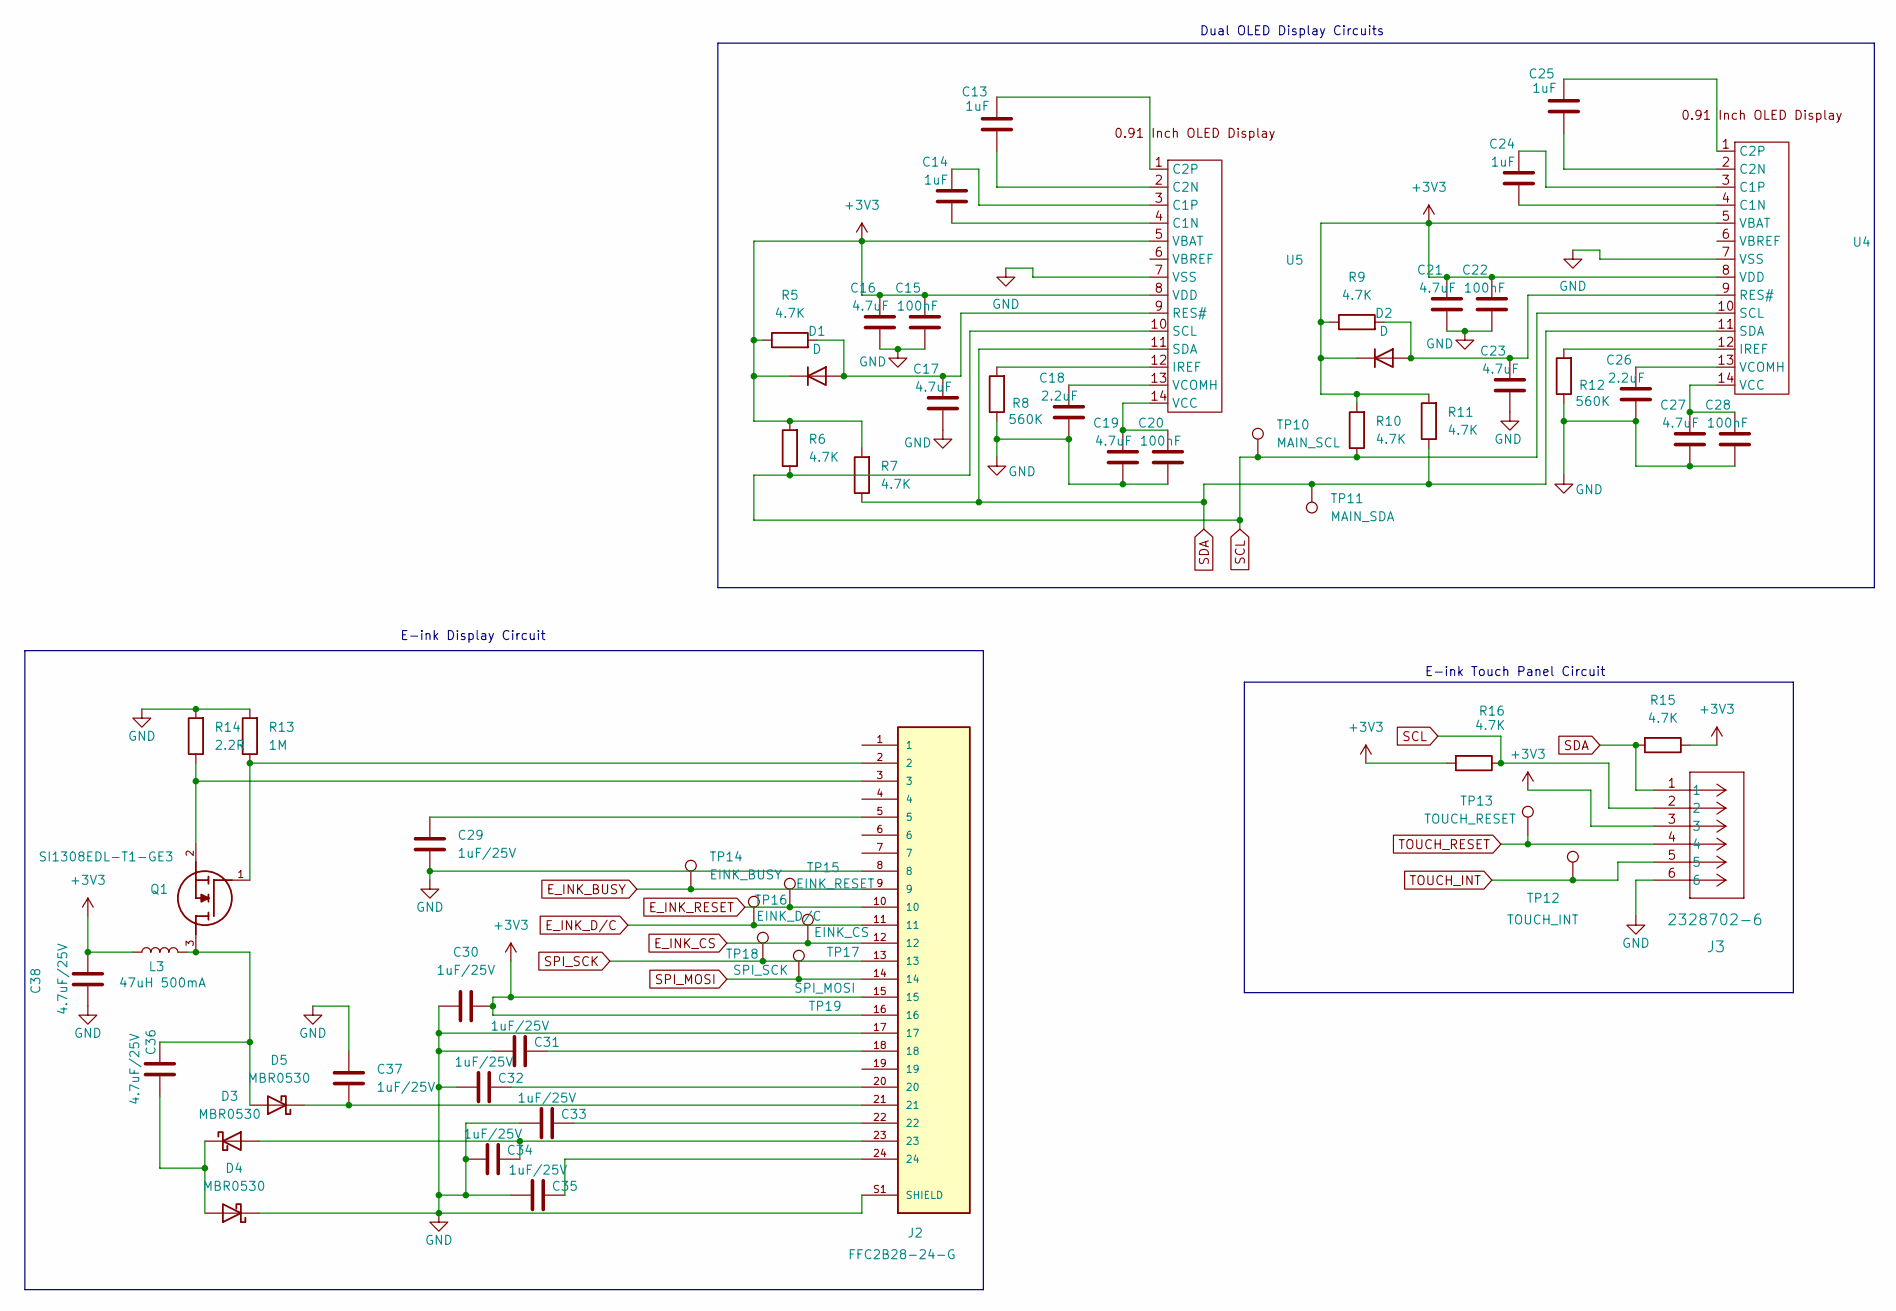
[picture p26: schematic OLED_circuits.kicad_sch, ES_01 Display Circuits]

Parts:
C13, C14, C24, C25: 1uF; C_0402_1005Metric_Pad0.74x0.62mm_HandSolder
C15, C20, C22, C28: 100nF; C_0402_1005Metric_Pad0.74x0.62mm_HandSolder
C16, C17, C19, C21, C23, C27: 4.7uF; C_0402_1005Metric_Pad0.74x0.62mm_HandSolder
C18, C26: 2.2uF; C_0402_1005Metric_Pad0.74x0.62mm_HandSolder
C29, C30, C31, C32, C33, C34, C35, C37: 1uF/25V; C_0402_1005Metric_Pad0.74x0.62mm_HandSolder
C36, C38: 4.7uF/25V; C_0402_1005Metric_Pad0.74x0.62mm_HandSolder
D1, D2: D; D_DO-35_SOD27_P7.62mm_Horizontal
D3, D4, D5: MBR0530; D_0805_2012Metric_Pad1.15x1.40mm_HandSolder
J2: FFC2B28-24-G; GCT_FFC2B28-24-G; PARTREV A
J3: 2328702-6; CONN6_2328702-6_TEC
L3: 47uH 500mA; Untitled
Q1: SI1308EDL-T1-GE3; SOT65P210X110-3N; Mouser_Part_Number 78-SI1308EDL-T1-GE3
R5, R6, R7, R9, R10, R11, R15, R16: 4.7K; R_0402_1005Metric_Pad0.72x0.64mm_HandSolder
R8, R12: 560K; R_0402_1005Metric_Pad0.72x0.64mm_HandSolder
R13: 1M; R_0402_1005Metric_Pad0.72x0.64mm_HandSolder
R14: 2.2R; R_0402_1005Metric_Pad0.72x0.64mm_HandSolder
TP10: MAIN_SCL; TestPoint_Pad_D1.0mm
TP11: MAIN_SDA; TestPoint_Pad_D1.0mm
TP12: TOUCH_INT; TestPoint_Pad_D1.0mm
TP13: TOUCH_RESET; TestPoint_Pad_D1.0mm
TP14: EINK_BUSY; TestPoint_Pad_D1.0mm
TP15: EINK_RESET; TestPoint_Pad_D1.0mm
TP16: EINK_D/C; TestPoint_Pad_D1.0mm
TP17: EINK_CS; TestPoint_Pad_D1.0mm
TP18: SPI_SCK; TestPoint_Pad_D1.0mm
TP19: SPI_MOSI; TestPoint_Pad_D1.0mm
U4, U5: Untitled

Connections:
+3V3: C15.1, C16.1, C21.1, C22.1, C30.2, C38.2, D1.1 (K), D2.1 (K), J2.15, J2.16, J3.3, L3.1, R5.1, R6.2, R7.2, R9.1, R10.2, R11.2, R15.1, R16.2, U4.5 (VBAT), U4.8 (VDD), U5.5 (VBAT), U5.8 (VDD); also elsewhere on the board
E_INK_BUSY: J2.9, TP14.1; also elsewhere on the board
E_INK_CS: J2.12, TP17.1; also elsewhere on the board
E_INK_D/C: J2.11, TP16.1; also elsewhere on the board
E_INK_RESET: J2.10, TP15.1; also elsewhere on the board
GND: C15.2, C16.2, C17.2, C18.2, C19.2, C20.2, C21.2, C22.2, C23.2, C26.2, C27.2, C28.2, C29.2, C30.1, C31.1, C32.1, C33.1, C34.1, C35.1, C37.1, C38.1, D4.1 (K), J2.8, J2.17, J2.S1 (SHIELD), J2.S2 (SHIELD), J3.6, R8.1, R12.1, R13.2, R14.2, U4.7 (VSS), U5.7 (VSS); also elsewhere on the board
unnamed: C29.1, J2.5
unnamed: C31.2, J2.18
unnamed: C32.2, J2.20
unnamed: C33.2, J2.22
unnamed: C35.2, J2.24
unnamed: C17.1, D1.2 (A), R5.2, U5.9 (RES#)
unnamed: C23.1, D2.2 (A), R9.2, U4.9 (RES#)
unnamed: C34.2, D3.2 (A), J2.23
unnamed: C36.1, D3.1 (K), D4.2 (A)
unnamed: C36.2, D5.2 (A), L3.2, Q1.3
unnamed: C37.2, D5.1 (K), J2.21
unnamed: J2.2, Q1.1, R13.1
unnamed: J2.3, Q1.2, R14.1
unnamed: C24.2, U4.4 (C1N)
unnamed: C24.1, U4.3 (C1P)
unnamed: C25.2, U4.2 (C2N)
unnamed: C25.1, U4.1 (C2P)
unnamed: R12.2, U4.12 (IREF)
unnamed: C27.1, C28.1, U4.14 (VCC)
unnamed: C26.1, U4.13 (VCOMH)
unnamed: C14.2, U5.4 (C1N)
unnamed: C14.1, U5.3 (C1P)
unnamed: C13.2, U5.2 (C2N)
unnamed: C13.1, U5.1 (C2P)
unnamed: R8.2, U5.12 (IREF)
unnamed: C19.1, C20.1, U5.14 (VCC)
unnamed: C18.1, U5.13 (VCOMH)
SCL: J3.2, R6.1, R10.1, R16.1, TP10.1, U4.10 (SCL), U5.10 (SCL); also elsewhere on the board
SDA: J3.1, R7.1, R11.1, R15.2, TP11.1, U4.11 (SDA), U5.11 (SDA); also elsewhere on the board
SPI_MOSI: J2.14, TP19.1; also elsewhere on the board
SPI_SCK: J2.13, TP18.1; also elsewhere on the board
TOUCH_INT: J3.5, TP12.1; also elsewhere on the board
TOUCH_RESET: J3.4, TP13.1; also elsewhere on the board

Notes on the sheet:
E-ink Display Circuit
Dual OLED Display Circuits
E-ink Touch Panel Circuit

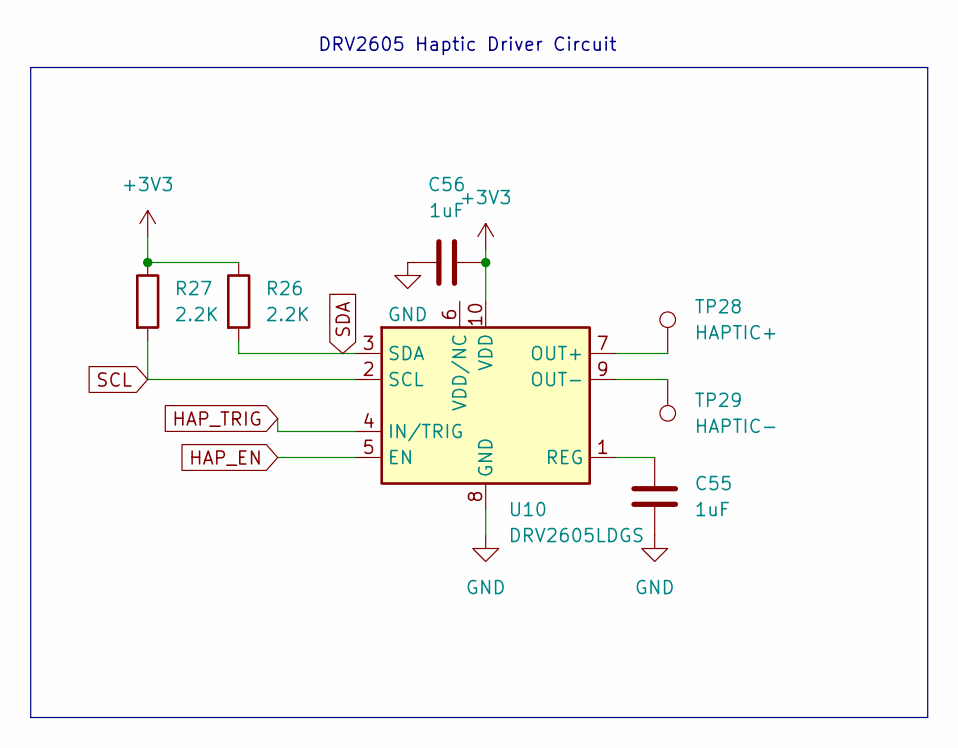
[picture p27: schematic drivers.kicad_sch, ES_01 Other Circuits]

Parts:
C55, C56: 1uF; C_0402_1005Metric_Pad0.74x0.62mm_HandSolder
R26, R27: 2.2K; R_0402_1005Metric_Pad0.72x0.64mm_HandSolder
TP28: HAPTIC+; TestPoint_Pad_1.5x1.5mm
TP29: HAPTIC-; TestPoint_Pad_1.5x1.5mm
U10: DRV2605LDGS; VSSOP-10_3x3mm_P0.5mm

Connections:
+3V3: C56.2, R26.1, R27.1, U10.10 (VDD); also elsewhere on the board
GND: C55.2, C56.1, U10.8 (GND); also elsewhere on the board
HAP_EN: U10.5 (EN); also elsewhere on the board
HAP_TRIG: U10.4 (IN/TRIG); also elsewhere on the board
unnamed: TP28.1, U10.7 (OUT+)
unnamed: TP29.1, U10.9 (OUT-)
unnamed: C55.1, U10.1 (REG)
SCL: R27.2, U10.2 (SCL); also elsewhere on the board
SDA: R26.2, U10.3 (SDA); also elsewhere on the board

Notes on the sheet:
DRV2605 Haptic Driver Circuit

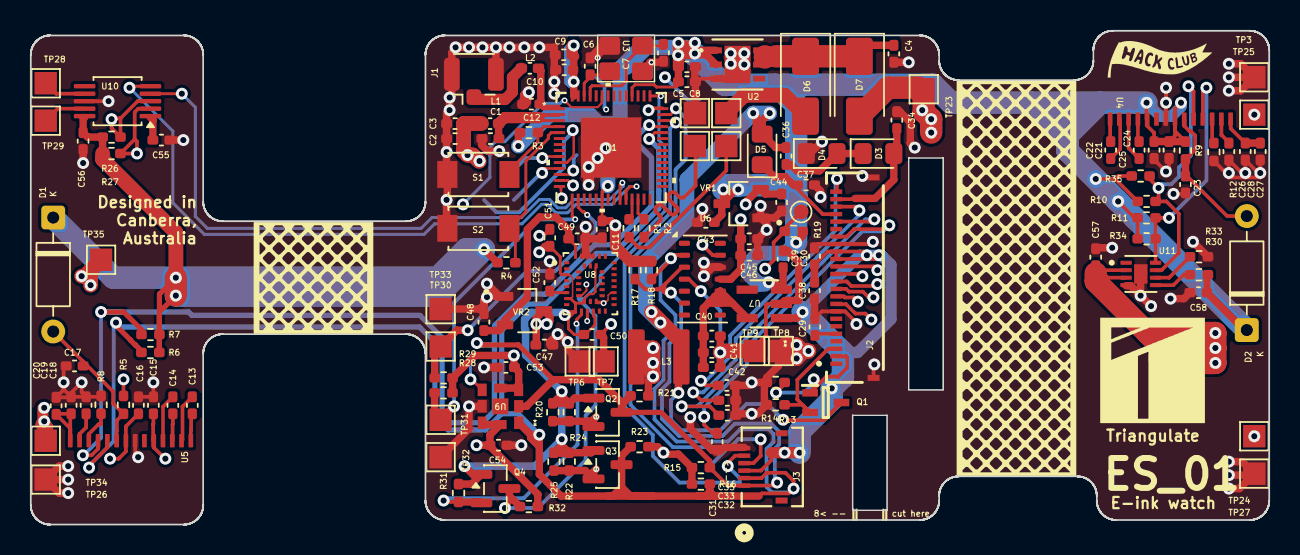
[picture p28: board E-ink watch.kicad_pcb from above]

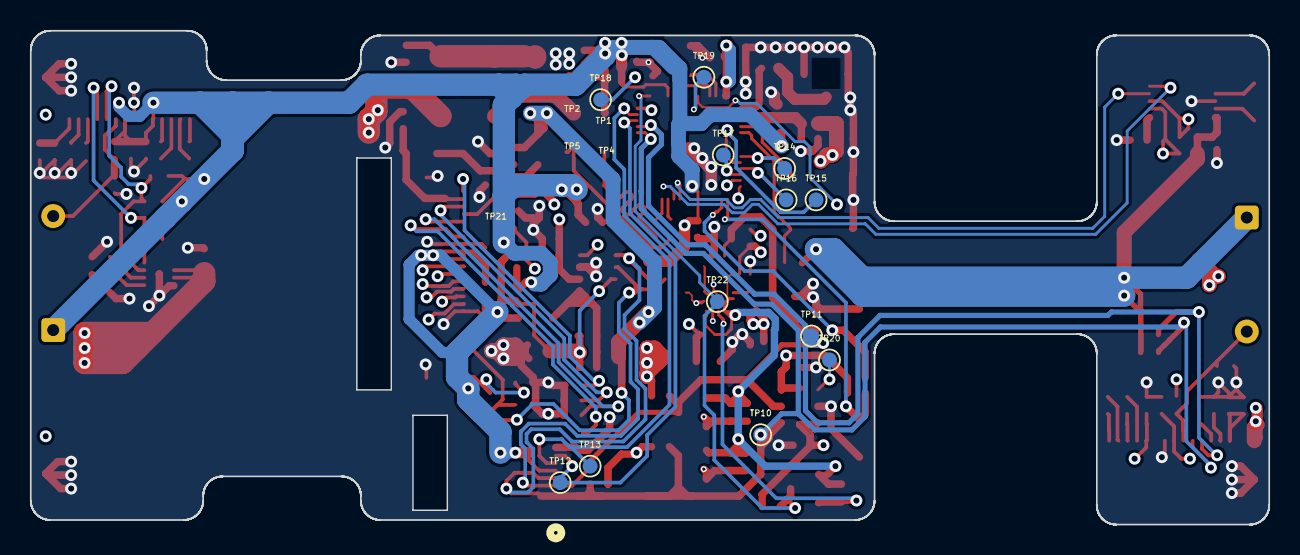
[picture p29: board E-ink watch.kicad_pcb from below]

Board: 4 copper layers, 82.8 x 33.0 mm, 160 parts (12 on the bottom side), 75 nets.

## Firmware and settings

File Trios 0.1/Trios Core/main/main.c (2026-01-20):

#include <stdio.h>
#include <math.h>
#include <stdint.h>
#include <stddef.h>

#include "freertos/FreeRTOS.h"
#include "freertos/task.h"
#include "esp_sleep.h"
#include "esp_log.h"
#include "esp_rom_sys.h"

#include "driver/gpio.h"
#include "driver/spi_master.h"
#include "driver/i2c.h"

#include "lvgl.h"
#include "esp_timer.h"

#include "epd_ssd1681.h"
#include "ft6336.h"

#include "esp_lcd_panel_io.h"
#include "esp_lcd_panel_ssd1306.h"
#include "esp_lcd_panel_vendor.h"
#include "esp_lcd_panel_ops.h"

#include "max30102.h"

#include "BHI260AP.fw.h"
#include "bhy2.h"
#include "bhy2_defs.h"

#include "bmp5.h"
#include "bmp5_defs.h"

#include "drv2605.h"

/* =======================
 *  Display (SPI / EPD)
 * ======================= */

#define PIN_NUM_MOSI   23
#define PIN_NUM_CLK    18
#define PIN_NUM_CS      5
#define PIN_NUM_DC     17
#define PIN_NUM_RST    16
#define PIN_NUM_BUSY    4

#define OLED1_ADDR 0x3C
#define OLED2_ADDR 0x3D

/* =======================
 *  Touch (I2C / FT6336)
 * ======================= */

#define I2C_PORT I2C_NUM_0
#define I2C_SDA  GPIO_NUM_8
#define I2C_SCL  GPIO_NUM_9
#define I2C_FREQ 400000

/* =======================
 *  Sensors
 * ======================= */

 #define HR_FREQUENCY_HZ 50
 #define HR_TIME_WINDOW_MS 6000
 #define HR_SAMPLES (HR_FREQUENCY_HZ * HR_TIME_WINDOW_MS / 1000)
 #define HR_MIN_INTERVAL_MS   300     // 200 BPM max
 #define HR_MAX_INTERVAL_MS  2000     // 30 BPM min
 #define AC_WINDOW_SAMPLES   (HR_FREQUENCY_HZ * 2)   // 2 seconds
 #define X 2
 #define Y 1
 #define Z 0

 #define BHI260_INT_GPIO  GPIO_NUM_7

 #define SEC_BTW_MEAS_IN_SLEEP 60 // The time in seconds between the ESP32 waking up to take HR measurements while it is sleeping
 #define INACTIVE_SEC_BEFORE_SLEEP 10 // Time in seconds of touch inactivity on E-ink display before going to sleep

/* =======================
 *  Globals
 * ======================= */

static spi_device_handle_t spi;
static epd_t epd;
static lv_display_t *e_ink_disp;
static esp_lcd_panel_io_handle_t io_hndl_oled1 = NULL;
static esp_lcd_panel_handle_t oled1 = NULL;
static esp_lcd_panel_io_handle_t io_hndl_oled2 = NULL;
static esp_lcd_panel_handle_t oled2 = NULL;
static max30102_t hr_sensor;
static float heart_rate = 0.0;
volatile bool hr_resuming = true;

static bool just_woke_up = false;

static TaskHandle_t hr_task_handle;
static TaskHandle_t lvgl_task_handle;

struct bhy2_dev bhi260ap;
uint8_t work_buffer[2048]; // FIFO data buffer
uint8_t gesture_code; // BHI260AP wrist turn gesture code

uint32_t steps; // Total step count since BHI260 reset

typedef struct {
    int16_t x;
    int16_t y;
    int16_t z;
    int16_t w;
    uint16_t accuracy; // estimated accuracy in radians * 2^14 (sometimes reserved)
} bhy2_data_quaternion;

float euler_angles[3] = {0.0f, 0.0f, 0.0f}; // Euler angles that were converted from quaternions

SemaphoreHandle_t i2c_mux;

struct bmp5_dev bmp585;

struct bmp5_sensor_data bmp585_data;

/* ==========================================
 *  OLED flush callbacks forward declarations
 * ========================================== */

static void lv_oled1_flush_cb(lv_display_t *disp, const lv_area_t *area, uint8_t *px_map);
static void lv_oled2_flush_cb(lv_display_t *disp, const lv_area_t *area, uint8_t *px_map);

/* ==========================
 *  Signal processing helpers
 * ========================== */

static float mean_u32(const uint32_t *buf, int len)
{
    uint64_t sum = 0;
    for (int i = 0; i < len; i++) {
        sum += buf[i];
    }
    return (float)sum / len;
}

static float rms_u32(const uint32_t *buf, int len, float mean)
{
    float sum_sq = 0.0f;
    for (int i = 0; i < len; i++) {
        float v = buf[i] - mean;
        sum_sq += v * v;
    }
    return sqrtf(sum_sq / len);
}

float fixed_to_float(int16_t val) {
    return val / 16384.0f; // 2^14
}

/* =======================
 *  I2C init
 * ======================= */

static void i2c_init(void)
{
    i2c_mux = xSemaphoreCreateMutex();
    configASSERT(i2c_mux);

    if (i2c_mux == NULL) {
        printf("Failed to create I2C mutex\n");
        while(1) {
            vTaskDelay(pdMS_TO_TICKS(1000));
        }
    }

    i2c_config_t cfg = {
        .mode = I2C_MODE_MASTER,
        .sda_io_num = I2C_SDA,
        .scl_io_num = I2C_SCL,
        .sda_pullup_en = GPIO_PULLUP_ENABLE,
        .scl_pullup_en = GPIO_PULLUP_ENABLE,
        .master.clk_speed = I2C_FREQ
    };

    i2c_param_config(I2C_PORT, &cfg);
    i2c_driver_install(I2C_PORT, cfg.mode, 0, 0, 0);
}

/* =======================
 *  Touch → LVGL callback
 * ======================= */

static void touch_read_cb(lv_indev_t *indev, lv_indev_data_t *data)
{
    static uint16_t last_x;
    static uint16_t last_y;

    uint16_t x, y;

    if (ft6336_get_touch(&x, &y)) {
        last_x = x;
        last_y = y;

        data->state = LV_INDEV_STATE_PRESSED;
        data->point.x = x;
        data->point.y = y;
    } else {
        data->state = LV_INDEV_STATE_RELEASED;
        data->point.x = last_x;
        data->point.y = last_y;
    }
}

static void lvgl_touch_init(void)
{
    lv_indev_t *indev = lv_indev_create();
    lv_indev_set_type(indev, LV_INDEV_TYPE_POINTER);
    lv_indev_set_read_cb(indev, touch_read_cb);
}

/* =======================
 *  SPI init
 * ======================= */

static void spi_init(void)
{
    spi_bus_config_t buscfg = {
        .mosi_io_num = PIN_NUM_MOSI,
        .miso_io_num = -1,
        .sclk_io_num = PIN_NUM_CLK,
        .quadwp_io_num = -1,
        .quadhd_io_num = -1,
        .max_transfer_sz = 4096,
    };

    spi_device_interface_config_t devcfg = {
        .clock_speed_hz = 4 * 1000 * 1000,
        .mode = 0,
        .spics_io_num = -1,
        .queue_size = 1,
    };

    spi_bus_initialize(SPI2_HOST, &buscfg, SPI_DMA_CH_AUTO);
    spi_bus_add_device(SPI2_HOST, &devcfg, &spi);
}

/* =======================
 *  GPIO init
 * ======================= */

static void gpio_init(void)
{
    gpio_config_t out_cfg = {
        .mode = GPIO_MODE_OUTPUT,
        .pin_bit_mask =
            (1ULL << PIN_NUM_CS) |
            (1ULL << PIN_NUM_DC) |
            (1ULL << PIN_NUM_RST),
    };
    gpio_config(&out_cfg);

    gpio_config_t in_cfg = {
        .mode = GPIO_MODE_INPUT,
        .pin_bit_mask = (1ULL << PIN_NUM_BUSY),
    };
    gpio_config(&in_cfg);

    gpio_set_level(PIN_NUM_CS, 1);
}

/* =======================
 *  EPD driver init
 * ======================= */

static void epd_driver_init(void)
{
    epd.spi = spi;
    epd.pin_cs = PIN_NUM_CS;
    epd.pin_dc = PIN_NUM_DC;
    epd.pin_rst = PIN_NUM_RST;
    epd.pin_busy = PIN_NUM_BUSY;

    epd_init(&epd);
}

/* =======================
 *  LVGL flush callback
 * ======================= */

static void lvgl_flush_cb(lv_display_t *disp,
                          const lv_area_t *area,
                          uint8_t *px_map)
{
    epd_lvgl_flush(&epd,
                   area->x1, area->y1,
                   area->x2, area->y2,
                   px_map);

    lv_display_flush_ready(disp);
}

/* =======================
 *  LVGL display init
 * ======================= */

static void lvgl_displays_init(void)
{
    static lv_draw_buf_t draw_buf_ep;
    static lv_color_t buf1[EPD_WIDTH * 40];   // 40 lines buffer

    static lv_draw_buf_t draw_buf_oled1;
    static lv_color_t buf_oled1[128 * 32]; // 128 x 32 oled

    static lv_draw_buf_t draw_buf_oled2;
    static lv_color_t buf_oled2[128 * 32]; // 128 x 32 oled

    lv_draw_buf_init(
        &draw_buf_ep,
        EPD_WIDTH,
        40,
        LV_COLOR_FORMAT_NATIVE,
        EPD_WIDTH * sizeof(lv_color_t),
        buf1,
        sizeof(buf1)
    );

    lv_draw_buf_init(
        &draw_buf_oled1,
        128,
        32,
        LV_COLOR_FORMAT_NATIVE,
        128 * sizeof(lv_color_t),
        buf_oled1,
        sizeof(buf_oled1)
    );

    lv_draw_buf_init(
        &draw_buf_oled2,
        128,
        32,
        LV_COLOR_FORMAT_NATIVE,
        128 * sizeof(lv_color_t),
        buf_oled2,
        sizeof(buf_oled2)
    );

    e_ink_disp = lv_display_create(EPD_WIDTH, EPD_HEIGHT);
    lv_display_set_draw_buffers(e_ink_disp, &draw_buf_ep, NULL);
    lv_display_set_flush_cb(e_ink_disp, lvgl_flush_cb);

    lv_display_t *oled1_disp = lv_display_create(128, 32);
    lv_display_set_draw_buffers(oled1_disp, &draw_buf_oled1, NULL);
    lv_display_set_flush_cb(oled1_disp, lv_oled1_flush_cb);

    lv_display_t *oled2_disp = lv_display_create(128, 32);
    lv_display_set_draw_buffers(oled2_disp, &draw_buf_oled2, NULL);
    lv_display_set_flush_cb(oled2_disp, lv_oled2_flush_cb);
}

/* =======================
 *  FT6336 init
 * ======================= */

static void touch_init(void)
{
    ft6336_config_t cfg = {
        .i2c_port = I2C_PORT,
        .i2c_addr = 0x38,
        .rst_gpio = GPIO_NUM_10,
        .int_gpio = GPIO_NUM_NC,
        .x_max = 320,
        .y_max = 240
    };

    ESP_ERROR_CHECK(ft6336_init(&cfg));
}

/* =======================
 *  OLED1 init
 * ======================= */

static void oled1_init(void)
{
    esp_lcd_panel_io_i2c_config_t io_i2c_cfg_oled1 = {
        .dev_addr = OLED1_ADDR,
        .control_phase_bytes = 1,
    };
    esp_lcd_new_panel_io_i2c(I2C_PORT, &io_i2c_cfg_oled1, &io_hndl_oled1);
    
    esp_lcd_panel_dev_config_t oled_cfg = {
        .bits_per_pixel = 1,
    };

    ESP_ERROR_CHECK(
        esp_lcd_new_panel_ssd1306(io_hndl_oled1, &oled_cfg, &oled1)
    );

    esp_lcd_panel_reset(oled1);
    esp_lcd_panel_init(oled1);
}

/* =======================
 *  OLED2 init
 * ======================= */

static void oled2_init(void)
{
    esp_lcd_panel_io_i2c_config_t io_i2c_cfg_oled2 = {
    .dev_addr = OLED2_ADDR,
    .control_phase_bytes = 1,
};
    esp_lcd_new_panel_io_i2c(I2C_PORT, &io_i2c_cfg_oled2, &io_hndl_oled2);

    esp_lcd_panel_dev_config_t oled_cfg = {
        .bits_per_pixel = 1,
    };
    ESP_ERROR_CHECK(
        esp_lcd_new_panel_ssd1306(io_hndl_oled2, &oled_cfg, &oled2)
    );

    esp_lcd_panel_reset(oled2);
    esp_lcd_panel_init(oled2);
}

/* ===============================
 *  OLED flush callbacks for LVGL
 * =============================== */

static void lv_oled1_flush_cb(lv_display_t *disp,
                              const lv_area_t *area,
                              uint8_t *px_map)
{
    esp_lcd_panel_draw_bitmap(oled1,
                               area->x1, area->y1,
                               area->x2+1, area->y2+1,
                               px_map);
    lv_display_flush_ready(disp);
}

static void lv_oled2_flush_cb(lv_display_t *disp,
                              const lv_area_t *area,
                              uint8_t *px_map)
{
    esp_lcd_panel_draw_bitmap(oled2,
                               area->x1, area->y1,
                               area->x2+1, area->y2+1,
                               px_map);
    lv_display_flush_ready(disp);
}

/* =======================
 *  UI
 * ======================= */

static void ui_init(void)
{
    lv_obj_t *label = lv_label_create(lv_scr_act());
    lv_label_set_text(label, "Hello e-paper");
    lv_obj_center(label);
}

/* =======================
 *  LVGL tick callback
 * ======================= */

static void lv_tick_cb(void *arg)
{
    lv_tick_inc(1);
}

/* =======================
 *  LVGL task
 * ======================= */

static void lvgl_task(void *arg)
{
    while (1) {
        lv_timer_handler();
        vTaskDelay(pdMS_TO_TICKS(5));
    }
}

/* ======================
*  Heart Rate Init
*  ====================== */

static void heart_rate_init(void)
{
    esp_err_t err = max30102_init(&hr_sensor, I2C_PORT);
    if (err != ESP_OK) {
        printf("Failed to initialize MAX30102 sensor\n");
        vTaskDelete(NULL);
        return;
    }

    max30102_configure(&hr_sensor,
                       0x1F, // LED brightness
                       4, // Sample average
                       3, // LED mode
                       3, // Sample rate
                       3, // Pulse width
                       3  // ADC range
    );
}

/* ========================
*  Heart Rate Reading Task
*  ======================== */

static void heart_rate_task(void *arg)
{
    uint32_t ir_buf[HR_SAMPLES] = {0};
    int buf_idx = 0;
    bool buffer_filled = false;

    uint32_t last_peak_time = 0;
    float bpm_sum = 0.0f;
    int bpm_count = 0;

    uint32_t prev_ir = 0;
    uint32_t curr_ir = 0;

    while (1) {
        if (hr_resuming) {
            buffer_filled = false;
            buf_idx = 0;
            last_peak_time = 0;
            bpm_sum = 0;
            bpm_count = 0;
            hr_resuming = false;
        }
        // Sample IR
        if (max30102_read_ir(&hr_sensor, &curr_ir) != ESP_OK) {
            vTaskDelay(pdMS_TO_TICKS(20));
            continue;
        }

        ir_buf[buf_idx++] = curr_ir;
        if (buf_idx >= HR_SAMPLES) {
            buf_idx = 0;
            buffer_filled = true;
        }

        if (buffer_filled) {
            // DC over full window
            float dc = mean_u32(ir_buf, HR_SAMPLES);

            // AC over shorter window
            int ac_start = (buf_idx - AC_WINDOW_SAMPLES + HR_SAMPLES) % HR_SAMPLES;
            uint32_t ac_buf[AC_WINDOW_SAMPLES];

            for (int i = 0; i < AC_WINDOW_SAMPLES; i++) {
                ac_buf[i] = ir_buf[(ac_start + i) % HR_SAMPLES];
            }

            float ac_rms = rms_u32(ac_buf, AC_WINDOW_SAMPLES, dc);

            // Signal quality check
            if ((ac_rms / dc) > 0.005f) {
                float threshold = 0.5f * ac_rms;

                float prev_ac = (float)prev_ir - dc;
                float curr_ac = (float)curr_ir - dc;

                uint32_t now = esp_timer_get_time() / 1000; // ms

                // Peak detection
                if (prev_ac < threshold && curr_ac >= threshold) {
                    if (last_peak_time != 0) {
                        uint32_t interval = now - last_peak_time;

                        if (interval > HR_MIN_INTERVAL_MS &&
                            interval < HR_MAX_INTERVAL_MS) {

                            float bpm = 60000.0f / interval;

                            bpm_sum += bpm;
                            bpm_count++;

                            if (bpm_count >= 3) {
                                heart_rate = bpm_sum / bpm_count;
                                bpm_sum = 0;
                                bpm_count = 0;
                                printf("Heart rate: %.2f bpm\n", heart_rate); // For debugging
                            }
                        }
                    }
                    last_peak_time = now;
                }
            }
        }

        prev_ir = curr_ir;
        vTaskDelay(pdMS_TO_TICKS(1000 / HR_FREQUENCY_HZ));
    }
}

/* ===========================
*  Stop heart rate measurement
*  =========================== */

void stop_hr_measurement(void)
{
    vTaskSuspend(hr_task_handle);
    max30102_shutdown(&hr_sensor);
}

/* =============================
*  Resume heart rate measurement
*  ============================= */

void resume_hr_measurement(void)
{
    hr_resuming = true;
    max30102_wakeup(&hr_sensor);
    max30102_configure(&hr_sensor,
                   0x1F,
                   4,
                   3,
                   3,
                   3,
                   3);
    vTaskResume(hr_task_handle);
}


/* ======================
*  Orientation callback
*  ====================== */

void orientation_callback(const struct bhy2_fifo_parse_data_info *callback_info, void *callback_ref) {
    bhy2_data_quaternion *quat_data = (bhy2_data_quaternion *)callback_info->data_ptr;
    
    float x = fixed_to_float(quat_data->x);
    float y = fixed_to_float(quat_data->y);
    float z = fixed_to_float(quat_data->z);
    float w = fixed_to_float(quat_data->w);

    printf("Orientation (quat): X:%.2f, Y:%.2f, Z:%.2f, W:%.2f\n", x, y, z, w);


    // Convert from quaternion to Euler angles (in radians)

    // X-axis
    double sinr_cosp = 2 * (w * x + y * z);
    double cosr_cosp = 1 - 2 * (x * x + y * y);
    euler_angles[X] = atan2(sinr_cosp, cosr_cosp);

    // Y-axis
    double sinp = 2 * (w * y - z * x);
    if (fabs(sinp) >= 1) {
        euler_angles[Y] = copysign(M_PI / 2, sinp);
    } else {
        euler_angles[Y] = asin(sinp);
    }

    // Z-axis
    double siny_cosp = 2 * (w * z + x * y);
    double cosy_cosp = 1 - 2 * (y * y + z * z);
    euler_angles[Z] = atan2(siny_cosp, cosy_cosp);
}

/* ======================
*  Step counter callback
*  ====================== */

void step_counter_callback(const struct bhy2_fifo_parse_data_info *callback_info, void *callback_ref) {
    
    
    // Copy the data from the FIFO pointer to our variable
    // The driver usually provides 4 bytes for the step count
    memcpy(&steps, callback_info->data_ptr, sizeof(steps));

    printf("Total Steps: %lu\n", (unsigned long)steps);
}

/* ======================
*  Wrist wakeup callback
*  ====================== */

void wrist_callback(const struct bhy2_fifo_parse_data_info *callback_info, void *callback_ref) {
    // The data_ptr points to a 1-byte value for this sensor
    gesture_code = *callback_info->data_ptr;

    /* * Standard Bosch Gesture Codes:
     * 0x01: Wrist Up (User looking at watch)
     * 0x02: Wrist Down (User moved arm away)
     */
    if (gesture_code == 0x01) {
        printf("Wrist Flick UP detected!\n");
    } else if (gesture_code == 0x02) {
        printf("Wrist Flick DOWN detected!\n");
    }
}

/* ================================
*  Inertial measurement unit setup
*  ================================ */

void bhi260_setup(void)
{
    bhy2_init(BHY2_I2C_INTERFACE,
            bhi260_i2c_read,
            bhi260_i2c_write,
            bhi260_delay_us,
            256,
            NULL,
            &bhi260ap);
    
    bhy2_soft_reset(&bhi260ap);
    bhy2_upload_firmware_to_ram(bhy2_firmware_image, sizeof(bhy2_firmware_image), &bhi260ap);
    bhy2_boot_from_ram(&bhi260ap);
    bhy2_update_virtual_sensor_list(&bhi260ap);

    uint8_t ornt_snsr_id = BHY2_SENSOR_ID_GAMERV;
    bhy2_register_fifo_parse_callback(ornt_snsr_id, orientation_callback, NULL, &bhi260ap);

    if (bhy2_is_sensor_available(ornt_snsr_id, &bhi260ap)) {
        bhy2_set_virt_sensor_cfg(ornt_snsr_id, 100.0f, 0, &bhi260ap);
        printf("Orientation sensor available\n");
    } else {
        printf("Error: Sensor not available\n");
    }

    uint8_t step_snsr_id = BHY2_SENSOR_ID_STC;

    bhy2_register_fifo_parse_callback(step_snsr_id, step_counter_callback, NULL, &bhi260ap);

    bhy2_set_virt_sensor_cfg(step_snsr_id, 1.0f, 0, &bhi260ap);

    // BHY2_SENSOR_ID_WRIST_WEAR_WAKE_UP is usually ID 46
    uint8_t wrist_snsr_id = BHY2_PHYS_SENSOR_ID_WRIST_WEAR_WAKEUP;

    // 1. Register a callback (useful if the ESP32 is already awake)
    bhy2_register_fifo_parse_callback(wrist_snsr_id, wrist_callback, NULL, &bhi260ap);

    // 2. Enable the sensor
    // Being a gesture sensor, the sample rate is often ignored, but set to 1.0Hz
    bhy2_set_virt_sensor_cfg(wrist_snsr_id, 1.0f, 0, &bhi260ap);
}

/* ========================
*  Puts ESP32 in light sleep
*  ======================== */

void go_to_sleep() {
    // 1. Configure the pin as a wakeup source
    // BHI260AP HIRQ is usually active HIGH (1.8V -> 3.3V via shifter)
    
    gpio_wakeup_enable(BHI260_INT_GPIO, GPIO_INTR_HIGH_LEVEL);
    esp_sleep_enable_gpio_wakeup();
    printf("Entering light sleep. Flick wrist to wake!\n");
    
    // 2. Enter light sleep
    esp_light_sleep_start();
    
}

/* ========================
*  IMU task
*  ======================== */

static void bhi260_task(void *arg) {
    while (1) {
        // Only process if the HIRQ pin is high (Level shifter ensures 3.3V logic)
        if (gpio_get_level(BHI260_INT_GPIO)) {
            bhy2_get_and_process_fifo(work_buffer, sizeof(work_buffer), &bhi260ap);
        }
        vTaskDelay(pdMS_TO_TICKS(10)); // Poll every 10ms
    }
}

/* ============================
*  I2C read function for BMP585
*  ============================ */

static int8_t bmp5_i2c_read(uint8_t reg_addr, uint8_t *data, uint32_t len, void *intf_ptr)
{
    i2c_port_t port = *(i2c_port_t *)intf_ptr;

    if (xSemaphoreTake(i2c_mux, pdMS_TO_TICKS(100)) != pdTRUE) {
        return BMP5_E_COM_FAIL;
    }
    esp_err_t err = i2c_master_write_read_device(
        port,
        BMP5_I2C_ADDR_PRIM,
        &reg_addr,
        1,
        data,
        len,
        pdMS_TO_TICKS(100)
    );

    xSemaphoreGive(i2c_mux);

    return (err == ESP_OK) ? BMP5_OK : BMP5_E_COM_FAIL;
}

/* =============================
*  I2C write function for BMP585
*  ============================= */

static int8_t bmp5_i2c_write(uint8_t reg_addr, const uint8_t *data, uint32_t len, void *intf_ptr)
{
    i2c_port_t port = *(i2c_port_t *)intf_ptr;

    uint8_t buf[len + 1];
    buf[0] = reg_addr;
    memcpy(&buf[1], data, len);

    if (xSemaphoreTake(i2c_mux, pdMS_TO_TICKS(100)) != pdTRUE) {
        return BMP5_E_COM_FAIL;
    }

    esp_err_t err = i2c_master_write_to_device(
        port,
        BMP5_I2C_ADDR_PRIM,
        buf,
        len + 1,
        pdMS_TO_TICKS(100)
    );

    xSemaphoreGive(i2c_mux);

    return (err == ESP_OK) ? BMP5_OK : BMP5_E_COM_FAIL;
}

/* ============================
*  Delay function for BMP585
*  ============================ */

static void bmp5_delay_us(uint32_t period, void *intf_ptr)
{
    esp_rom_delay_us(period);
}

/* ============================
*  BMP585 setup function
*  ============================ */
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
void app_main(void)
{
    startup_sequence(); // Start EVERYTHING up
}

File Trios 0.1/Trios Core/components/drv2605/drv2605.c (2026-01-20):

#include "drv2605.h"
#include "driver/i2c.h"
#include "freertos/FreeRTOS.h"
#include "freertos/semphr.h"

#define DRV2605_ADDR 0x5A

#define DRV2605_REG_STATUS     0x00
#define DRV2605_REG_MODE       0x01
#define DRV2605_REG_RTP_INPUT  0x02
#define DRV2605_REG_WAVESEQ1   0x04
#define DRV2605_REG_GO         0x0C
#define DRV2605_REG_FEEDBACK   0x1A
#define DRV2605_REG_CONTROL1   0x1B
#define DRV2605_REG_CONTROL2   0x1C
#define DRV2605_REG_CONTROL3   0x1D
#define DRV2605_REG_CONTROL4   0x1E

extern SemaphoreHandle_t i2c_mux;

/* ---------- Internal no-lock I2C helpers ---------- */

static esp_err_t drv2605_write_nolock(i2c_port_t port, uint8_t reg, uint8_t val)
{
    uint8_t buf[2] = { reg, val };
    return i2c_master_write_to_device(port, DRV2605_ADDR, buf, 2, pdMS_TO_TICKS(50));
}

static esp_err_t drv2605_read_nolock(i2c_port_t port, uint8_t reg, uint8_t *val)
{
    return i2c_master_write_read_device(port, DRV2605_ADDR,
                                        &reg, 1, val, 1,
                                        pdMS_TO_TICKS(50));
}

/* ---------- Public API ---------- */

esp_err_t drv2605_init(i2c_port_t port)
{
    if (xSemaphoreTake(i2c_mux, pdMS_TO_TICKS(200)) != pdTRUE)
        return ESP_ERR_TIMEOUT;

    esp_err_t ret = ESP_OK;

    ret |= drv2605_write_nolock(port, DRV2605_REG_MODE, 0x00);     // Exit standby
    ret |= drv2605_write_nolock(port, DRV2605_REG_FEEDBACK, 0x80); // LRA mode
    ret |= drv2605_write_nolock(port, DRV2605_REG_CONTROL1, 0x93);
    ret |= drv2605_write_nolock(port, DRV2605_REG_CONTROL2, 0xF5);
    ret |= drv2605_write_nolock(port, DRV2605_REG_CONTROL3, 0xA3);
    ret |= drv2605_write_nolock(port, DRV2605_REG_CONTROL4, 0x20);

    xSemaphoreGive(i2c_mux);
    return ret;
}

esp_err_t drv2605_autocalibrate(i2c_port_t port)
{
    if (xSemaphoreTake(i2c_mux, pdMS_TO_TICKS(500)) != pdTRUE)
        return ESP_ERR_TIMEOUT;

    drv2605_write_nolock(port, DRV2605_REG_MODE, 0x07);
    drv2605_write_nolock(port, DRV2605_REG_GO, 1);

    uint8_t go;
    do {
        vTaskDelay(pdMS_TO_TICKS(10));
        drv2605_read_nolock(port, DRV2605_REG_GO, &go);
    } while (go & 0x01);

    uint8_t status;
    drv2605_read_nolock(port, DRV2605_REG_STATUS, &status);

    xSemaphoreGive(i2c_mux);
    return (status & 0x08) ? ESP_FAIL : ESP_OK;
}

esp_err_t drv2605_play_effect(i2c_port_t port, uint8_t effect)
{
    if (xSemaphoreTake(i2c_mux, pdMS_TO_TICKS(200)) != pdTRUE)
        return ESP_ERR_TIMEOUT;

    drv2605_write_nolock(port, DRV2605_REG_MODE, 0x00);
    drv2605_write_nolock(port, DRV2605_REG_WAVESEQ1, effect);
    drv2605_write_nolock(port, DRV2605_REG_WAVESEQ1 + 1, 0);
    esp_err_t ret = drv2605_write_nolock(port, DRV2605_REG_GO, 1);

    xSemaphoreGive(i2c_mux);
    return ret;
}

esp_err_t drv2605_set_rtp(i2c_port_t port, uint8_t strength)
{
    if (xSemaphoreTake(i2c_mux, pdMS_TO_TICKS(200)) != pdTRUE)
        return ESP_ERR_TIMEOUT;

    drv2605_write_nolock(port, DRV2605_REG_MODE, 0x05);
    esp_err_t ret = drv2605_write_nolock(port, DRV2605_REG_RTP_INPUT, strength);

    xSemaphoreGive(i2c_mux);
    return ret;
}

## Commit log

2025-12-14 Updated KiCAD Files with finished PCB and manufacturing files
    [E-ink watch.kicad_pcb, E-ink watch.kicad_sch, ES_01_mainPCB_bom.csv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]
2025-12-14 Added the V1 KiCAD files back (to see progression ig
    [E-ink watch.kicad_sch, OLED_circuits.kicad_sch, sensors.kicad_sch]
2025-12-25 Update README.md with full BoM and pricing
2025-12-25 Update README.md with PNG schematics
2025-12-25 Add final PCB folder (as per Blueprint guidelines)
    [E-ink watch.kicad_pcb, E-ink watch.kicad_sch, ES_01_mainPCB_bom.csv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]
2025-12-25 Add all files used for Blender Renders (materials are downloaded from BlenderKit)
    [black-plastic-tiles_2K_43d20e5f-ffd5-40af-b8ef-8094d5e06349.blend, black-plastic_6acbffe2-8be6-4458-9b88-4d81a32f724b.blend, black-scratched-plastic_2K_563fd0d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]
2025-12-25 Add actual Blender File (Too large for normal commit, instead using LFS)
    [ES01Render.blend]
2025-12-25 Add STEP File with full assembly
2025-12-25 Update README.md with license acknowledgment of Blender materials
2025-12-25 Update README.md with small tweaks to BoM and other stuff
2025-12-25 Add new and fully correct Electronics BOM
    [Electronics_BOM.csv]
2025-12-27 Replace Electronics BOM with new version (with screws and inserts)
    [Electronics_BOM.csv]
2026-01-10 Created ESP-IDF Project for firmware
    Also added E-ink display driver module as a submodule
2026-01-10 Added LVGL Dependency and fixed errors in E-ink driver
2026-01-10 Wrote E-ink display driver and added LVGL
    Installed LVGL as a dependency and wrote a rough E-ink display component based on the Arduino examples given by GooDisplay
2026-01-14 Add heart rate sensor driver and measurement details
2026-01-15 Added BHI260AP support and tweaked PCB
    Implemented BHI260AP functions, including orientation detection, step counter, and wrist raise gesture interrupt, and tweaked PCB to include a logic level shifter between BHI260AP's interrupt pin and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
    [E-ink watch.csv, E-ink watch.kicad_pcb, E-ink watch.kicad_sch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]
2026-01-15 Update README with new schematic images
    Added additional schematic images for the E-ink watch.
2026-01-15 Added new schematic PDF
2026-01-16 Added support for BMP585 pressure/temp sensor
2026-01-16 Update README with new driver and functionality details
    Added functions for Bosch BHI260AP IMU and BMP585 sensor, including sleep/wake logic.
2026-01-16 Update project time and add journal entry for sensors
    Updated total project time and added new journal entry detailing the implementation of sensors in firmware.
2026-01-16 Changed file and folder names for printing
    [100mah battery (2).step, 100mah battery (3).step, 100mah battery (4).step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]
2026-01-17 Revise enclosure materials and update total costs
    Updated materials for enclosure components and revised total costs.
2026-01-17 Remove 3D printed enclosure parts from BOM
    Removed two entries for 3D printed enclosure parts.
    [Manufactured_Parts_BOM.csv]
2026-01-17 Tweaked the PCB and changed a couple of filenames
    [E-ink watch-B_Cu.gbl, E-ink watch-B_Mask.gbs, E-ink watch-B_Paste.gbp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]
2026-01-20 Added support for DRV2605 haptic driver
2026-01-20 Update journal with new entry and time spent
    Updated total time spent and journal entries count. Added new journal entry about integrating DRV2605 haptic driver into firmware.
2026-01-27 Added two more "apps" to UI, added logic for ESP-IDF integration
    Added Activity stats and Vitals "apps" to UI, added considerable Flow logic to make integration into ESP-IDF easier
2026-01-29 Added timekeeping "app" to UI
    Timekeeping "app" includes a stopwatch and user-configurable timer
2026-02-01 Added fuel gauge, fixed PCB, ordering instructions
    Added a fuel gauge IC to the PCB and schematic, fived errors in the schematic and PCB relating to display circuits, exported updated PCB production files, and created a README.md in the PCB directory for instructions on how to order the PCB
    [E-ink watch-B_Cu.gbl, E-ink watch-B_Mask.gbs, E-ink watch-B_Paste.gbp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]
2026-02-01 Revise README with updated schematics and PCB layout
    Updated schematics and PCB layout images with new links and added headings for clarity.
2026-02-01 Updated PCB Schematic PDFs
2026-02-02 Added MAX17048 to BoM
    [Electronics_BOM.csv]
2026-02-07 Added "apps", Updated CAD, Journal
    Added a Timetable "app", a Calendar "app", a Find ur Phone button and a Shot Button to the UI, and tweaked CAD files with branding and side TPU pieces were changed. There's a new journal entry explai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
    [ES_01_FullAssembly.step, Side TPU 2.step, Side TPU Piece 1.step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]
2026-02-15 Updated BoM according to parts availability
    [Electronics_BOM.csv]
2026-02-15 Changed 401225 battery to 401230
    401230 batteries are 5mm longer, so that required an update to the main enclosure, specifically the battery segments. Adding 401230 batteries adds an extra 90mah of capacity, brining the total to 390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
    [130mah battery.step, 130mah battery_2.step, 130mah battery_3.step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]
2026-02-15 Changed CAD Files names
    [bottom plate (OLED 2).step, bottom plate (OLED)(DONT PRINT).step, bottom plate (OLED).step]
2026-03-12 Update MAX17048 part number and details in BOM
    [Electronics_BOM.csv]
2026-03-12 Fix formatting of MAX17048G+T10 entry in BOM
    [Electronics_BOM.csv]
2026-03-12 Update component details in Electronics BOM
    [Electronics_BOM.csv]
2026-03-12 Update ESP32 part number and details in BOM
    [Electronics_BOM.csv]
2026-04-20 Started ES_01.1 PCB
    [ES_01.1 PCB.kicad_pcb, ES_01.1 PCB.kicad_sch, OLED_circuits.kicad_sch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]
